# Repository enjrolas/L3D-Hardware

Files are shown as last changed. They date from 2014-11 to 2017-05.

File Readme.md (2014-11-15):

This repository contains all the hardware files we use to make our cubes.  It's organized in two directories 
for the two sizes of cubes we make, a 8x8x8 cube and a 16x16x16 cube.  Each directory includes the eagle files
for the baseboard that goes at the bottom of the cube, and the thin LED stick PCBs that hold the LED themselves.
The 8x8x8 cube has 64 LED sticks, and the 16x16x16 cube has a whopping 256 LED sticks.  

Electrically, the cubes are quite simple.  They're based around the popular WS2812B addressable LED and the Spark Core processor.  Our BOM
has Chinese sources, but you can also source the WS2812B LEDs from any number of sources, such as [Adafruit](https://www.adafruit.com/products/1655) and our 
friends [at Seeed Studios](http://www.seeedstudio.com/depot/WS2812B-RGB-LED-with-Integrated-Driver-Chip-10-PCs-pack-p-1675.html).
The other components are a few common passives detailed in the BOM.

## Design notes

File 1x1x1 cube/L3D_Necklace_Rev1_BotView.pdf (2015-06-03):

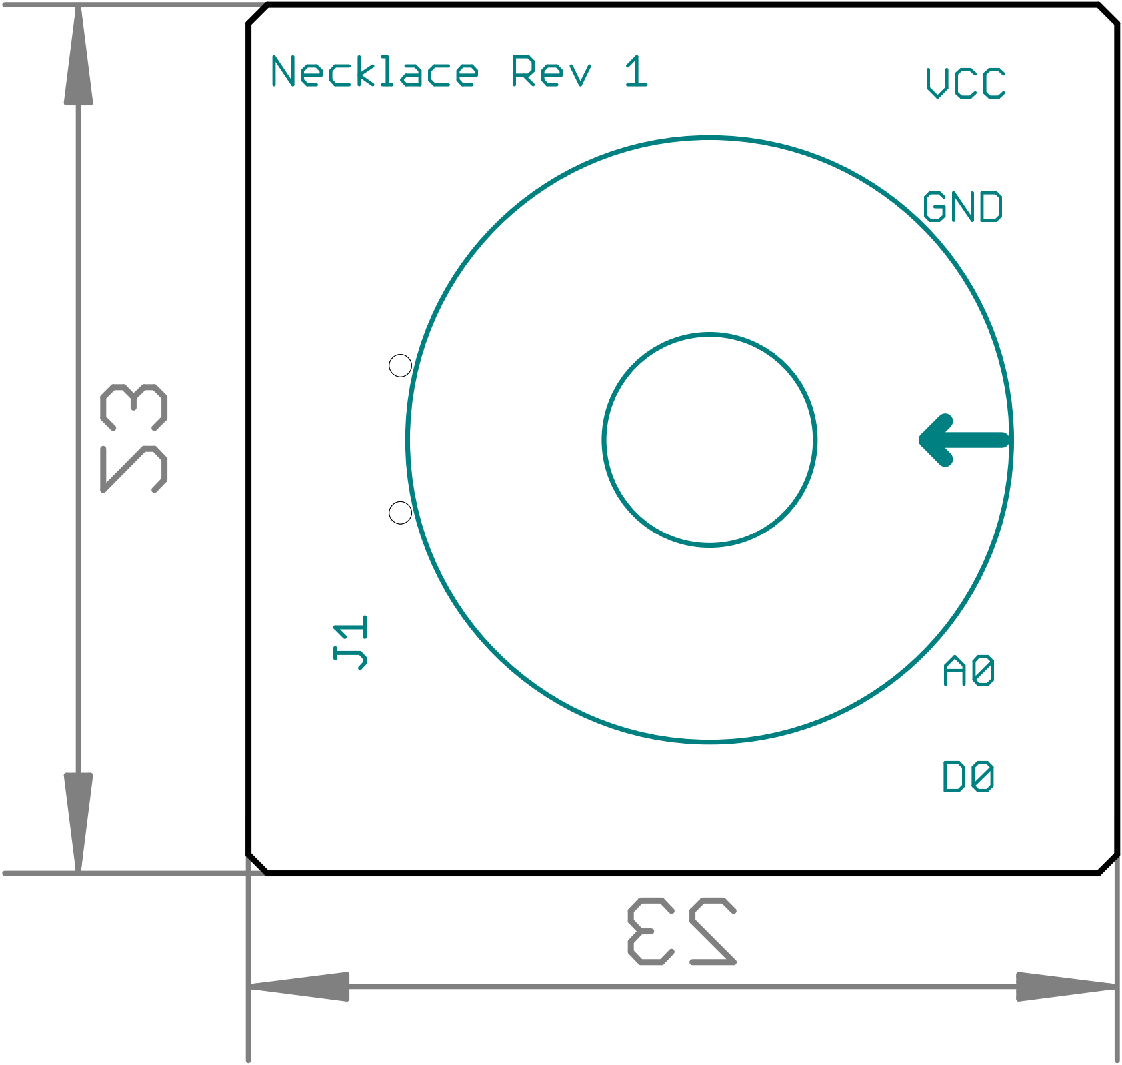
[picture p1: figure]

4/1/2015 4:39:10 PM f=8.00 mirrored D:\Dropbox\Dropbox (Haddock Invention)\L3D\Electronics\L3D_Necklace\L3D_NecklaceV1.brd

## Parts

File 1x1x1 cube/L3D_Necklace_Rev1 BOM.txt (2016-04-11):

Partlist exported from /Users/japhy/Downloads/L3D-Hardware-master/1x1x1 cube/L3D_Necklace_Rev1.sch at 4/11/16 1:42 PM

Part Value                              Device                             Package              Description                                                             
B1   BUTTONCELLLIR1632                  BUTTONCELLLIR1632                  BUTTONCELL_LIR1632                                                                           
C1   100nF                              C-0603                             0603                 Ceramic Capacitors                                                      
C2   100nF                              C-0603                             C0603                                                                                        
C6   10nF                               C-0603                             C0603                                                                                        
C7   100nF                              C-0603                             C0603                                                                                        
C9   100nF                              C-0603                             0603                 Ceramic Capacitors                                                      
C11  100nF                              C-0603                             0603                 Ceramic Capacitors                                                      
C12  100nF                              C-0603                             0603                 Ceramic Capacitors                                                      
D1                                      WS2812BWS2812B_STANDARD            WS2812B_STANDARD                                                                             
D2                                      LEDLED1206                         LED1206              LED                                                                     
J1   CONNECTOR-HEADER-2X3P2X3P-2.54-SMT CONNECTOR-HEADER-2X3P2X3P-2.54-SMT 2X3P-2.54-SMT                                                                                
J2   VCC                                1R5MM-HOLE                         1R5MM-HOLE                                                                                   
J3   GND                                1R5MM-HOLE                         1R5MM-HOLE                                                                                   
J4   D0                                 1R5MM-HOLE                         1R5MM-HOLE                                                                                   
J5   A0                                 1R5MM-HOLE                         1R5MM-HOLE                                                                                   
JP1  USBUSB-MICROB-SLOT-HOLE            USBUSB-MICROB-SLOT-HOLE            USB-MICROB-SLOT-HOLE                                                                         
M1   MICROPHONEMICROPHONE_1*3MM         MICROPHONEMICROPHONE_1*3MM         MICROPHONE_1*3MM                                                                             
Q1   TRANSISTOR-NPN-0400000P1           TRANSISTOR-NPN-0400000P1           SOT23                S9013：NPN Transistor                                                    
R1   75k                                R-0603                             0603                                                                                         
R2   100k                               R-0603                             0603                                                                                         
R3   50                                 R-0603                             0603                                                                                         
R4   1k                                 R-0603                             0603                                                                                         
R5   10k                                R-0603                             0603                                                                                         
R6   51                                 R-0603                             R0603                                                                                        
R7   100K                               R-0603                             R0603                                                                                        
R8   10K                                R-0603                             R0603                                                                                        
R9   10K                                R-0603                             R0603                                                                                        
R10  10K                                R-0603                             R0603                                                                                        
R11  100K                               R-0603                             R0603                                                                                        
R12  100K                               R-0603                             R0603                                                                                        
R13  100K                               R-0603                             R0603                                                                                        
R17  100K                               R-0603                             R0603                                                                                        
U1   MEGA8                              MEGA8                              MLF32X                                                                                       
U2   IC_SMD_FT232RQ                     IC_SMD_FT232RQ                     IC_SMD_QFN32         Source: http://www.ftdichip.com/Documents/DataSheets/DS_FT232R_v104.pdf 
U3   LM358DRSOT23-8(M8)                 LM358DRSOT23-8(M8)                 SOT-23-8(M8)         General purpose LOW Voltage, Rail-to-Rail Output Amplifiers             
Y1   SMARTPRJ_RESONATORMU               SMARTPRJ_RESONATORMU               SMARTPRJ_RESONATOR                                                                           
Z1   TL431                              TL431SOT23                         SOT23

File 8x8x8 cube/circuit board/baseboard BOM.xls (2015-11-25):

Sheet: Base PCBA
 |  | Base PCBA
Item | Part no. | Description | Reference | Qty | Remark
Base PCB | Base PCB | FR4, double side, 490x490mm, 2.0mm, 1oz black solder mask |  | 1
Resistors | ERJ-3GEYJ103V (http://www.digikey.com/product-detail/en/ERJ-3GEYJ103V) | RES 10K OHM 1/10W 5% 0603 SMD | R1,R4,R6,R8,R9,R10,R14,R15,R16,R20,R21,R26 | 12
Resistors | ERJ-3GEYJ104V (http://www.digikey.com/product-detail/en/ERJ-3GEYJ103V) | RES 100K OHM 1/10W 5% 0603 SMD | R11,R12,R18,R19, | 4
Resistors | ERJ-3GEYJ432V (http://www.digikey.com/product-detail/en/ERJ-3GEYJ103V) | RES 4.3K OHM 1/10W 5% 0603 SMD | R13 | 1
Resistors |  | RES 33 OHM, 1/10W 5% 0603 | R8 | 1
Resistors | ERJ-3GEYJ102V (http://www.digikey.com/product-detail/en/ERJ-3GEYJ103V) | RES 1K OHM 1/10W 5% 0603 SMD | R2,R5,R17 | 3
Resistors |  | RES 220K OHM 1/10W 5% 0603 | R22 | 1
Resistors |  | RES 180K OHM 1/10W 5% 0603 | R23 | 1
Resistors |  | RES 3.3M OHM 1/10W 5% 0603 | R24 | 1
Resistors |  | RESISTOR .68 OHM 2W, THROUGH HOLE | R3,R7 | 2
Capacitors | C1608X7R1E104K (http://www.digikey.com/product-detail/en/C1608X7R1E104K) | CAP CER 0.1UF 25V 10% X7R 0603 | C3,C6,C7,C8,C9,C10,C11,C12,C13 | 10
Capacitors | C3528 | TAN CAP 220UF C3528 | C19 | 1
Capacitors | C1608X7R1E106K (http://www.digikey.com/product-detail/en/C1608X7R1E104K) | CAP CER 10UF 6.3V 10% X7R 0603 | C5 | 1
Capacitors | C1608X7R1E224K | CAP CER 0.22uF 25V 10% X7R 0603 | C14, C17 | 2
Capacitors | C1608X7R1E104K (http://www.digikey.com/product-detail/en/C1608X7R1E104K) | CAP CER 10nF 25V 10% X7R 0603 | C15 | 1
Capacitors | C1608X7R1E681K | CAP CER 680PF 25V 10% NPO 0603 | C16 | 1
Capacitors |  | 470UF, 16V, E.CAP | C1,C2 | 2
Inductor | Inductors | 2.2uH, 100mA, 0603 | L1 | 1
MOSFET | FDD6637 | MOSFET, 5A, TO-252 | Q2 | 1
MOSFET | 2N7002 | 2N7002, SOT23, 200mA | Q1,Q3 | 2
DIODE | BAV199 | BAV199 | D1 | 1
DIODE | 1N4148 | 1N4148 | D2 | 1
TRANSISTOR | SS8550 | SS8550, SOT23 | Q4 | 1
OP AMP | LMV324I | OP AMP LMV324I SO-14 | U2 | 1
CONNECTOR | 2X2,FEMALE | XH2X2, 2.54MM, FEMALE, flash gold | j1-j64 | 64
CONNECTOR | 1X12, FEMALE | 1X12, FEMALE, 2.54MM | JP1,JP2 | 2
CONNECTOR | 1x40, MALE | 1X40, MALE PIN, 2.54MM | A1 | 1
SLIDE SWITCH | SK12D07VG3 | SLIDE SWITCH, 2P3T | S1 | 1
BUTTON SWITCH | MODE SWITCH | 12X12X7MM TACT SWITCH | MODE | 1
BUTTON SWITCH | RESET SWITCH | 6X6X5MM TACT SWITCH | RESET | 1
MICROPHONE | MICROPHONE | MICROPHONE, 52DB,DIA=9MM | M1 | 1
ACCELEROMETER | ADXL335BCPZ | ADXL335, 3 AXIS, 16FL | U1 | 1
Foam |  |  |  | 1

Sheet: LED PCBA
 |  | LED PCBA
Item | Part no. | Description | Reference | Qty
stick PCB | stick PCB | FR4, double side, 6.9x197mm, 1.0mm, 1oz black solder mask |  | 65
ESD bag | ESD bag | ESD bag 70*200, no zipper |  | 8
LED | WS2812B | WS2812B | D1-D520 | 520
connector | XH2x2 | XH2.54, 2X2, RIGHT ANGLE, FLASH GOLD | J1-J65 | 65

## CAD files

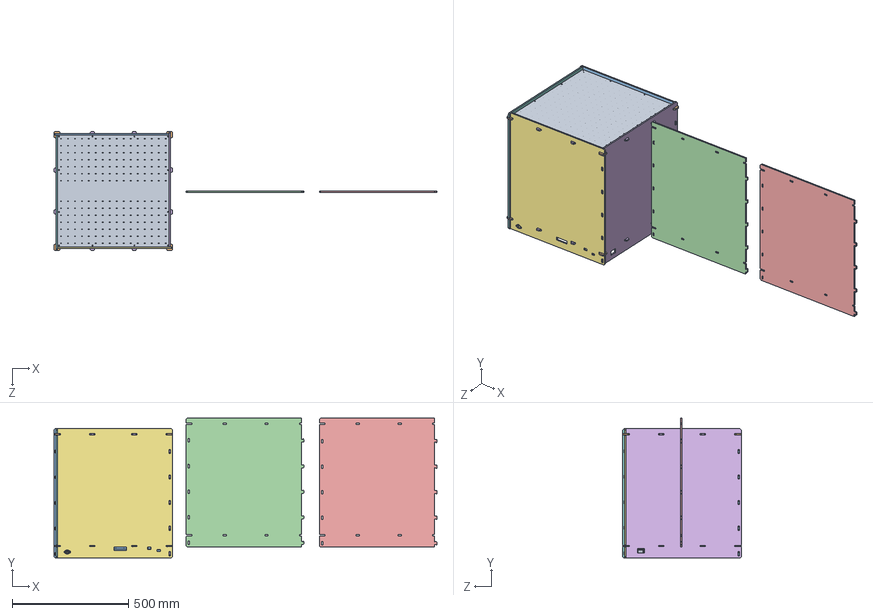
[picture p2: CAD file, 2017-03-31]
16x16x16 cube/3D model/LEDcube.SLDASM
1646.7 x 601.0 x 510.4 mm
pcb_bot
pcb_strick
box_side1
box_upside
box_downside
box_side2
box_side3
box_side4
box_top
corner x 8
box_bot
sup x 4
sup2 x 4
KPJX-PM-4S_rB8
spark
DC2DC
white connector
BigCubePowerPlugholder

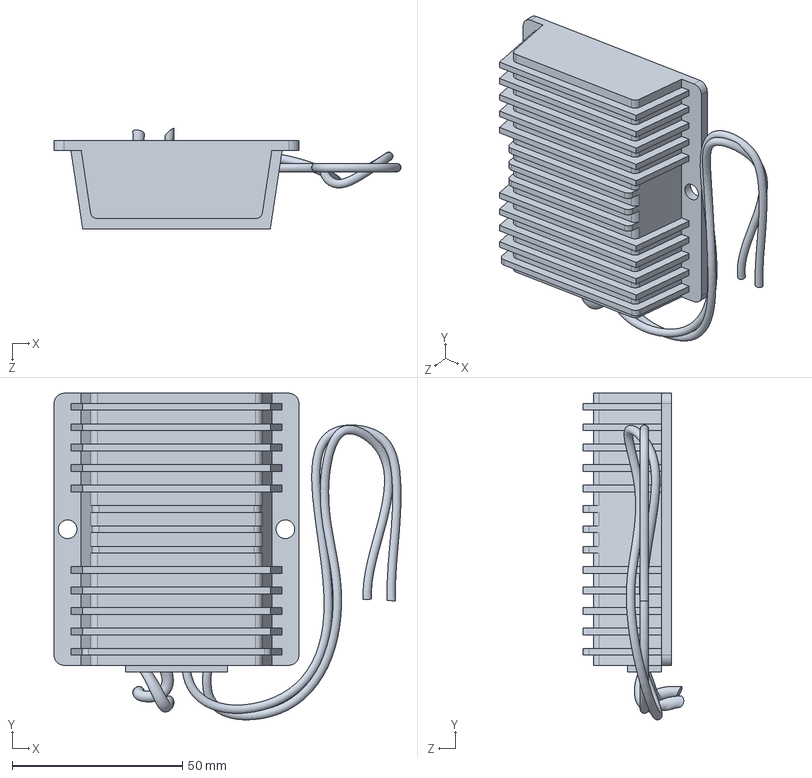
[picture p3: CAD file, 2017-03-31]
16x16x16 cube/3D model/DC2DC.SLDPRT
102.0 x 96.0 x 29.6 mm

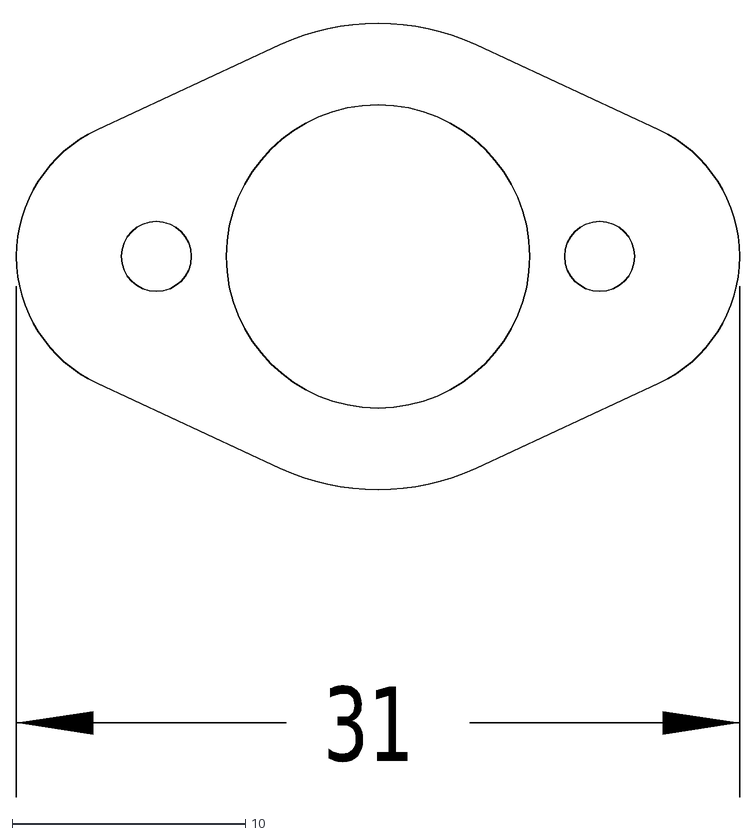
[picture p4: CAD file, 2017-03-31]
16x16x16 cube/case/3mm.DXF
31

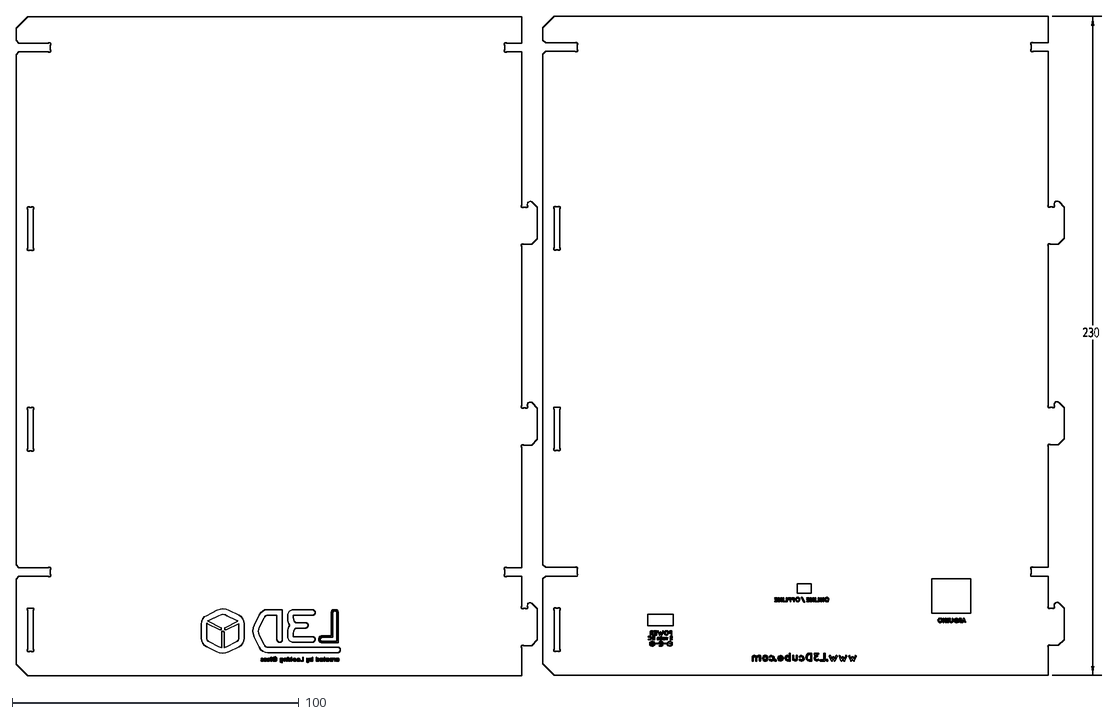
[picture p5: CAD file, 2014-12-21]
8x8x8 cube/case/2mm_eng.DXF
230

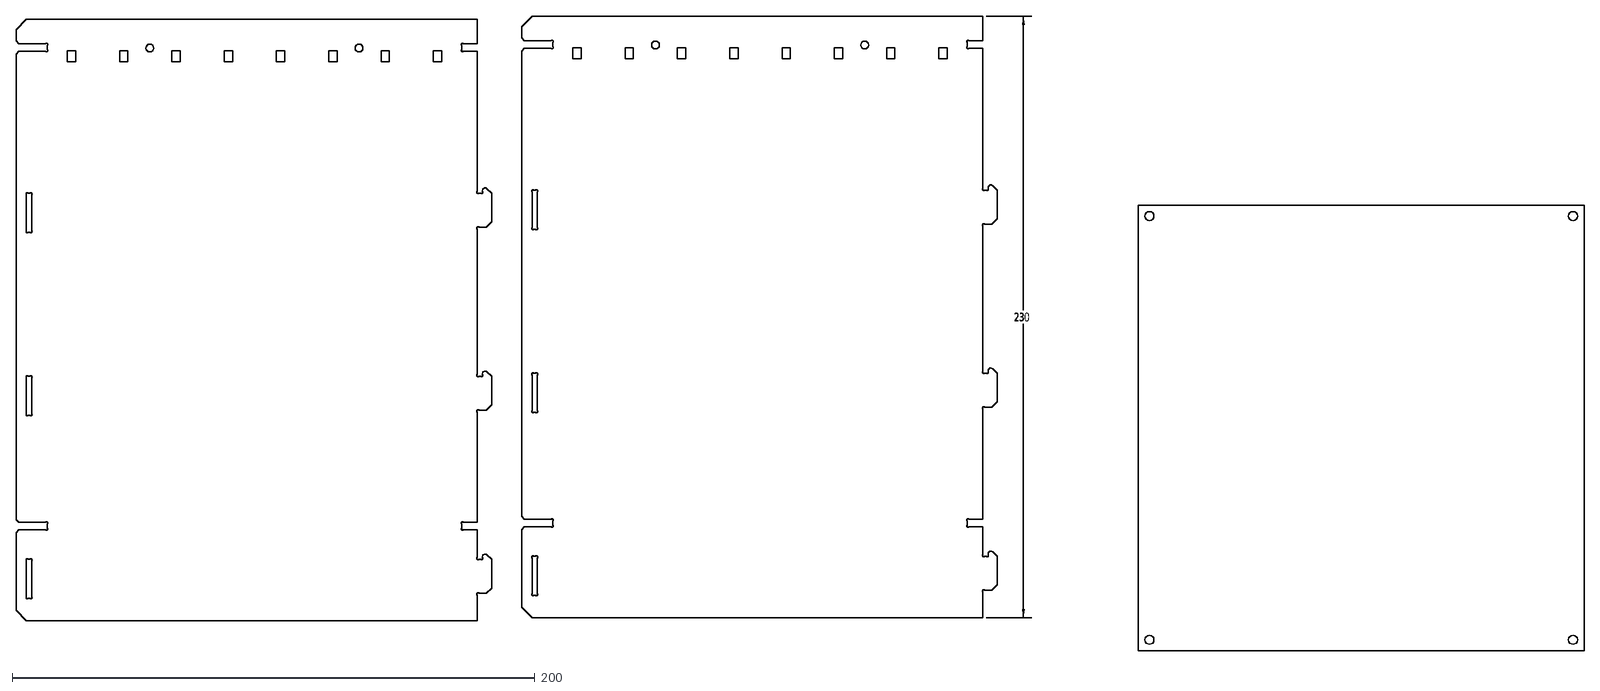
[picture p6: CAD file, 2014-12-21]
8x8x8 cube/case/2mm.DXF
230

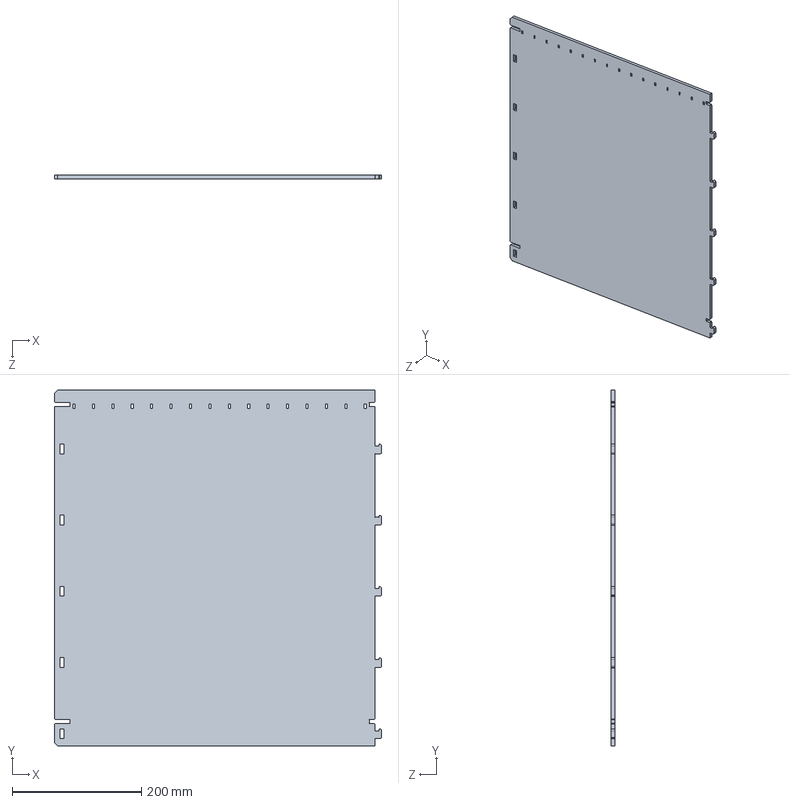
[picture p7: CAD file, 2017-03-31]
16x16x16 cube/3D model/box_side4.SLDPRT
505.4 x 550.0 x 6.00 mm

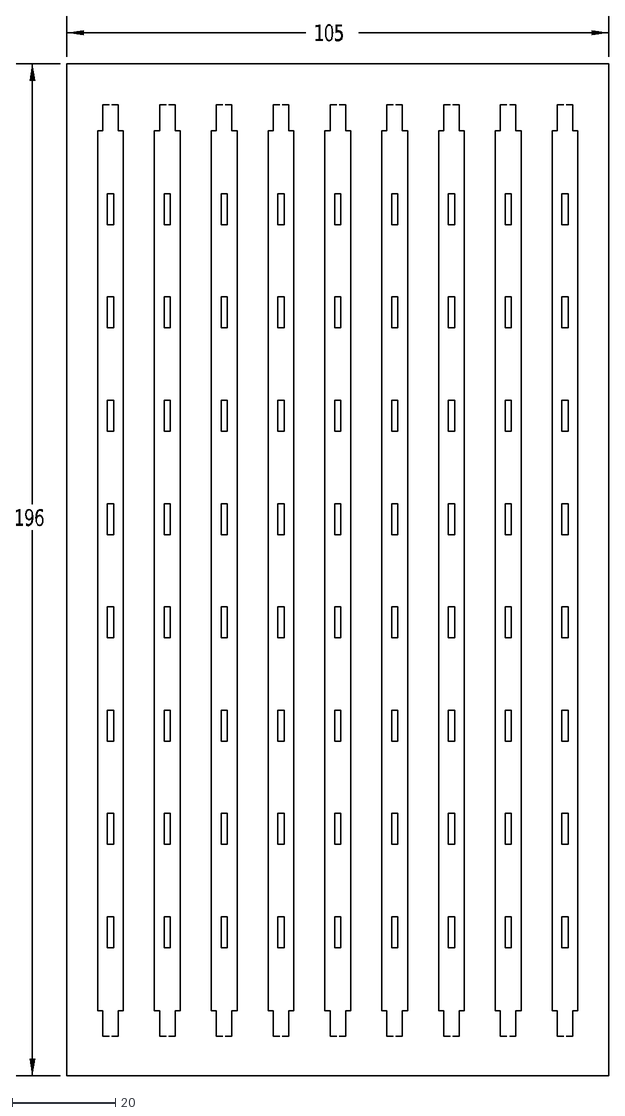
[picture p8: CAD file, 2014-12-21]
8x8x8 cube/case/4mm plate.DXF
105
196

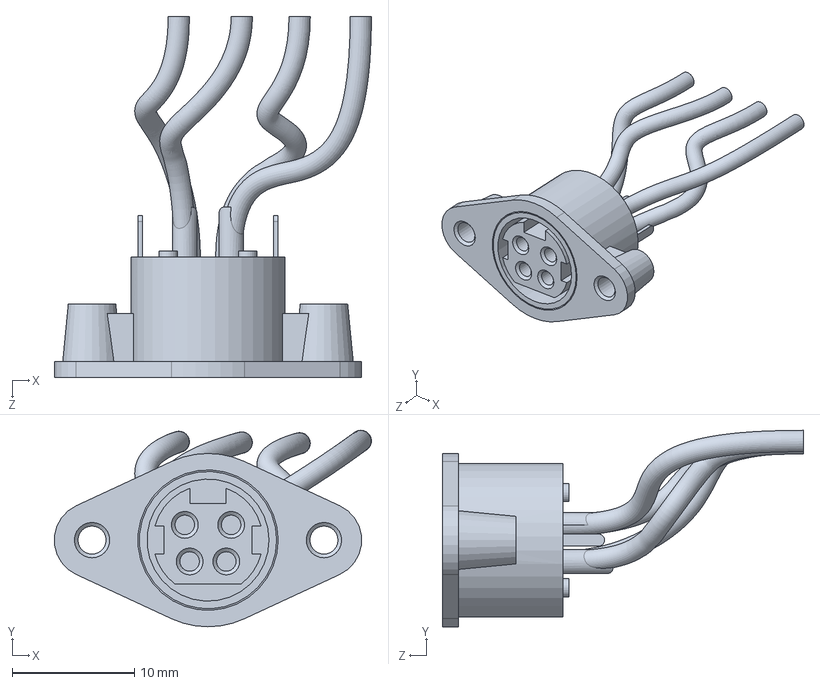
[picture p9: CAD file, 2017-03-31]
16x16x16 cube/3D model/KPJX-PM-4S_rB8.SLDPRT
26.0 x 16.1 x 29.6 mm

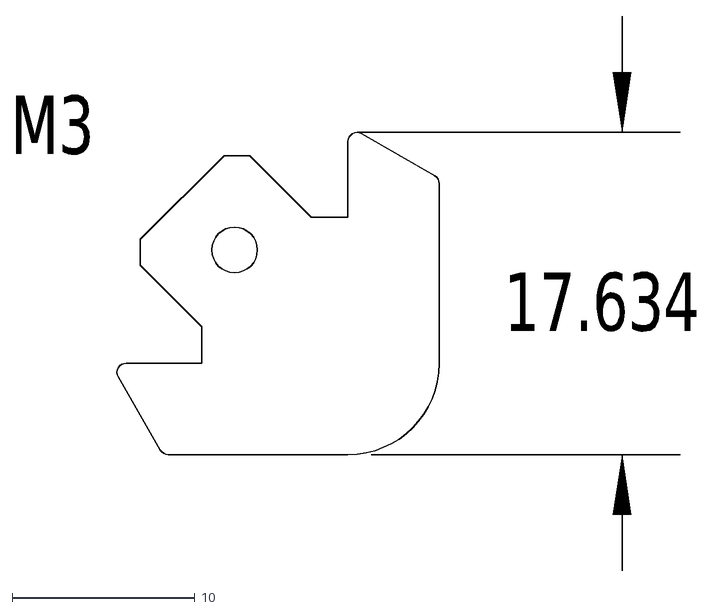
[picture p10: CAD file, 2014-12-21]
8x8x8 cube/case/corner.DXF
17.634
M3

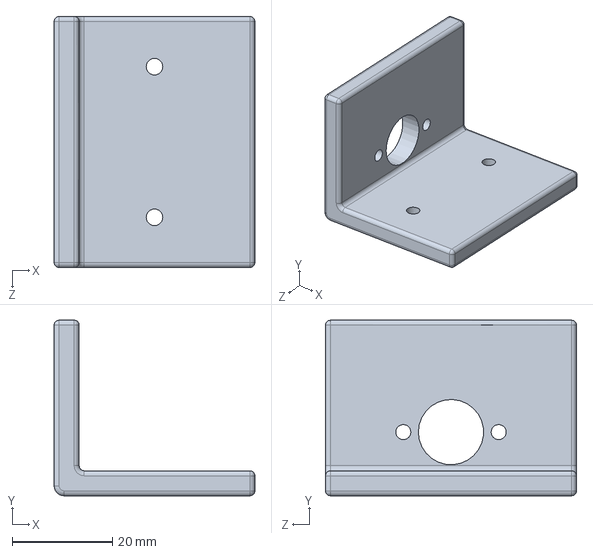
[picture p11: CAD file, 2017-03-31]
16x16x16 cube/3D model/BigCubePowerPlugholder.SLDPRT
40.0 x 35.0 x 50.0 mm

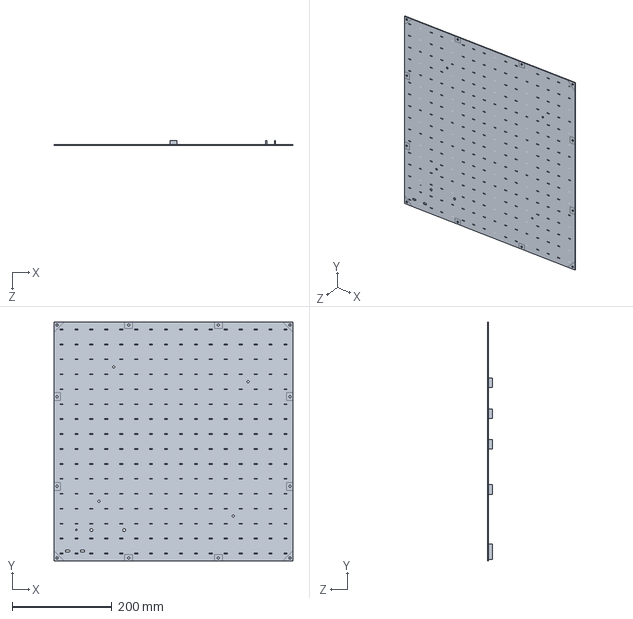
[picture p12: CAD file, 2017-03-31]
16x16x16 cube/3D model/pcb_bot.SLDPRT
480.0 x 480.0 x 10.5 mm

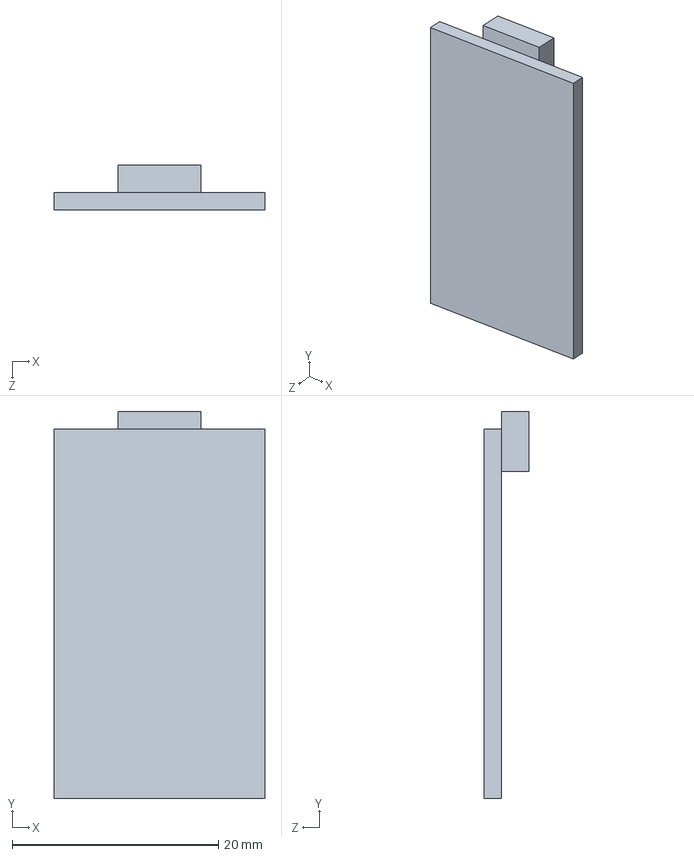
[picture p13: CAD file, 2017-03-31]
16x16x16 cube/3D model/spark.SLDPRT
20.4 x 37.5 x 4.40 mm

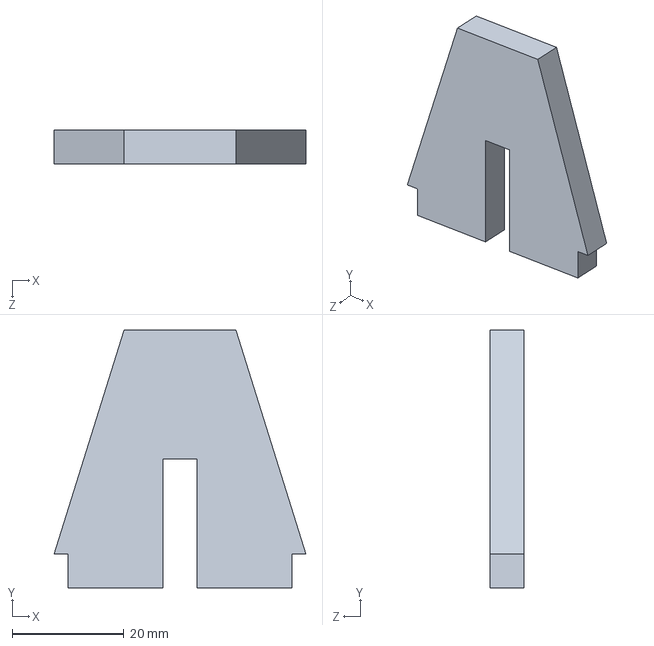
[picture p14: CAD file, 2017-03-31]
16x16x16 cube/3D model/sup2.SLDPRT
45.0 x 46.0 x 6.00 mm

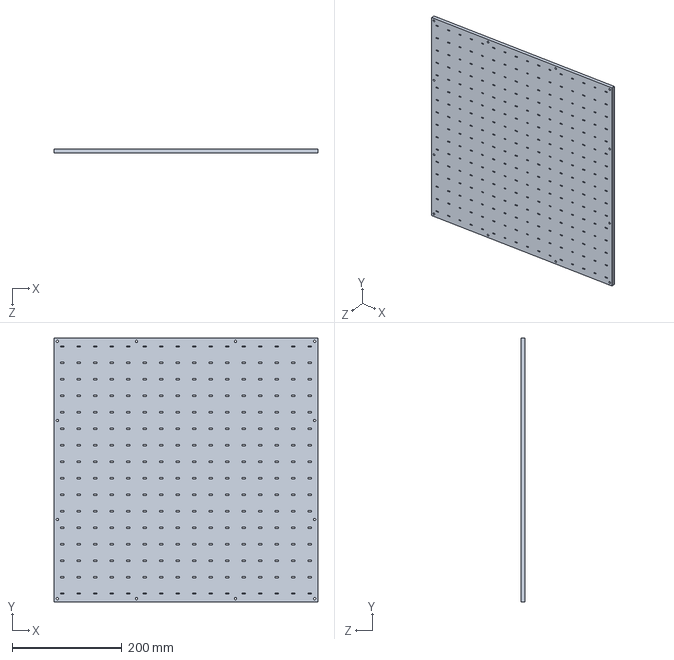
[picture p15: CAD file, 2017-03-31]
16x16x16 cube/3D model/box_top.SLDPRT
480.2 x 480.2 x 8.00 mm

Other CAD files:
16x16x16 cube/case/6mm.DXF
16x16x16 cube/case/8mm.DXF
16x16x16 cube/3D model/box_upside.SLDPRT
16x16x16 cube/3D model/box_side3.SLDPRT
16x16x16 cube/3D model/box_downside.SLDPRT
16x16x16 cube/3D model/box_side1.SLDPRT
16x16x16 cube/3D model/box_side2.SLDPRT
16x16x16 cube/3D model/corner.SLDPRT
16x16x16 cube/3D model/face.SLDPRT
16x16x16 cube/3D model/pcb_strick.SLDPRT
16x16x16 cube/3D model/sup.SLDPRT
16x16x16 cube/3D model/white connector.SLDPRT

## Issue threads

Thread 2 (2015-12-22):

Some questions about the L3D-Hardware

myxingchao, 2015-12-22:
Hello, I downloaded your hardware package, looked and found sch file with my altium designer can not open your schematic, ask you what software painting? ? Can you give me some guidance

enjrolas, 2015-12-22:
Hi — these were done in eagleCAD <https://www.google.com/url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>.  There’s a free download for hobbyist use.

—alex

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

myxingchao, 2015-12-30:
hello alex, after seen your schematic, I feel your light cube is very interesting, I ask that you have the entire list of parts it? ? Can you give me a look

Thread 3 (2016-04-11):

Is there a BOM for the 1x1x1 cube?

oculartechie, 2016-04-11:

enjrolas, 2016-04-11:
Thanks for mentioning — just added it to the repo.

—me

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

oculartechie, 2016-04-12:
Thanks.  Do you have Digikey part numbers for some of the parts?  Also, for the sketch, it is for one side of the 1x1x1 cube?  Thanks.

oculartechie, 2016-08-12:
Checking on this again.

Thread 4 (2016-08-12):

request .brd board layout for daughter board v3.1 (sept 2015) 16x16x16

scottjames, 2016-08-12:
Our local maker space and science center ([suncoastscience.org](http://suncoastscience.org)) has a 16x16x16 cube, and we really enjoy playing with it! Great job on the design and implementation!

However, ours has dark panels number 4, and 6.  I noticed the v3 schematic and board seems out of date, and wonder if you would update to the latest files for 16x cube?  The board on our cube shows Sept. 2015, but the .brd v3 files says January 2015.

Also, the v3 daughterboard has the .sch schematic layout, but no board .brd file.  I wanted to trace the signals to diagnose the two cube panels not working.  The schematic helps, but I was hoping to get the board layout file too?

We are also writing an updated library with driver for the 16x16x16 cube, since most files we find seem hardcoded for the 8x8x8 cube.  It's been a challenge finding software for the 16x cube and we wanted to create something to contribute back to the community.  This work is being done by the [Sarasota Software Engineers User Group](http://www.meetup.com/SarasotaSoftwareEngineers/) as we update create our library, we will update our [github page with Cube Examples](https://github.com/srqsoftware/Cubetube-Examples).

thanks!
-Scott

enjrolas, 2016-08-12:
Hi Scott,
	Thanks for letting me know, will chat with our team’s EE and get the latest schematic and board files up ASAP.  I’ll let you know once it’s up.

—me

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

ODINITE, 2017-02-08:
What is the status of the 16x16x16 .brd files? I can't seem to open the .brd files with Eagle.

Is there an updated set of files that can be posted? I am interested in seeing the layout to understand how to multiplex to 4096 addresses and may want to order a PCB sometime in the future to tinker with (when funds allow it).

enjrolas, 2017-02-08:
I just tried — was able to open them fine in eagle 7.7.0 on my mac — what version of eagle are you using?

—alex

On February 7, 2017 at 7:44:55 PM, Aaron Jensen (notifications@github.com) wrote:

What is the status of the 16x16x16 .brd files? I can't seem to open the .brd files with Eagle.

Is there an updated set of files that can be posted? I am interested in seeing the layout to understand how to multiplex to 4096 addresses and may want to order a PCB sometime in the future to tinker with (when funds allow it).

—
You are receiving this because you commented.
Reply to this email directly, view it on GitHub, or mute the thread.

enjrolas, 2017-02-08:
FWIW, we don’t multiplex in the L3D cube — we use WS2812B digital LEDs, and we clock the data out into strings of LEDs.  The 16x cube has 8 parallel data lines, and each data line has 512 LEDs — 2 16x16 planes.  The photon processor that we use is able to drive those strings at 60hz

On February 7, 2017 at 7:44:55 PM, Aaron Jensen (notifications@github.com) wrote:

What is the status of the 16x16x16 .brd files? I can't seem to open the .brd files with Eagle.

Is there an updated set of files that can be posted? I am interested in seeing the layout to understand how to multiplex to 4096 addresses and may want to order a PCB sometime in the future to tinker with (when funds allow it).

—
You are receiving this because you commented.
Reply to this email directly, view it on GitHub, or mute the thread.

ODINITE, 2017-02-08:
Thank you for the very prompt response. I reinstalled Eagle and re-downloaded the repository and it seems to be working now.

In the "L3D-Hardware-master\16x16x16 cube" folder, I see a Rev3 .brd file for the base board, but do not see a Rev3 .brd file for the Daughter board (although a .sch and a .pdf file exists for the Rev3 Daughter board). Is this missing, or will the Rev1 Daughter board work with the Rev3 base board?

Thanks for the info about the WS2812B digital LEDs! I erroneously assumed it was being multiplexed like some other Cube projects out there. I actually used a very similar setup on my Ambilight TV project. The LED strips are very easy to work with!

enjrolas, 2017-02-08:
Oh, good call — lemme chat with the EE and get the rev 3 brd file up in the repo.  Thanks for letting me know.  I’ll post once it’s up.

FWIW, there’s not that all that much going on in the daughter board.  We made that board because we couldn’t put the monster ~2’x2’ motherboard into a pick-and-place, so we just threw all the SMT parts onto the daughterboard so we could assemble it.

Basically, there’s a socket for a photon processor, a microphone and amplifier circuit (we route a mic signal into the photon so we can make stuff that responds to music), an accelerometer (I wrote a cute little interface where you smack the cube to change the pattern), and a 3.3v - 5v level shifter, to bring the 3.3v data signals from the photon for the WS2812s up to 5v, which the WS2812s prefer.

If you wanted a stripped-down DIY version, all you’d really need is the photon and the level shifter, and in fact, you can kiiinda get away without the level shifter, although with these long traces, it’s more reliable to work with 5V data.

On February 8, 2017 at 12:41:46 AM, Aaron Jensen (notifications@github.com) wrote:

Thank you for the very prompt response. I reinstalled Eagle and re-downloaded the repository and it seems to be working now.

In the "L3D-Hardware-master\16x16x16 cube" folder, I see a Rev3 .brd file for the base board, but do not see a Rev3 .brd file for the Daughter board (although a .sch and a .pdf file exists for the Rev3 Daughter board). Is this missing, or will the Rev1 Daughter board work with the Rev3 base board?

Thanks for the info about the WS2812B digital LEDs! I erroneously assumed it was being multiplexed like some other Cube projects out there. I actually used a very similar setup on my Ambilight TV project. The LED strips are very easy to work with!

—
You are receiving this because you commented.
Reply to this email directly, view it on GitHub, or mute the thread.

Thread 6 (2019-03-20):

Open hardware license

jdeglavina, 2019-03-20:
Hello!

I obviously missed when these cubes were first released. Awesome work!

I see that everything is open hardware, but I don't see any license attached on here, or to any of the hardware/software files. Is there one?

I'm asking because I made some tweaks to the design to use an ESP32 in place of a Particle Photon, and modified the LED sticks slightly. I would like to sell the PCB's in my store, if possible. Please let me know if we can arrange that.

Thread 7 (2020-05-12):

L3d Cube problem

Dan0583, 2020-05-12:
Hi. I bought the led cube some years ago. Cube tube site is not working anymore and I am unable to flash my cube. I wrongly deleted the firmware on the photon and I tried to add this one on the console but it doesn't work. Could you please help me? Thanks in advance.

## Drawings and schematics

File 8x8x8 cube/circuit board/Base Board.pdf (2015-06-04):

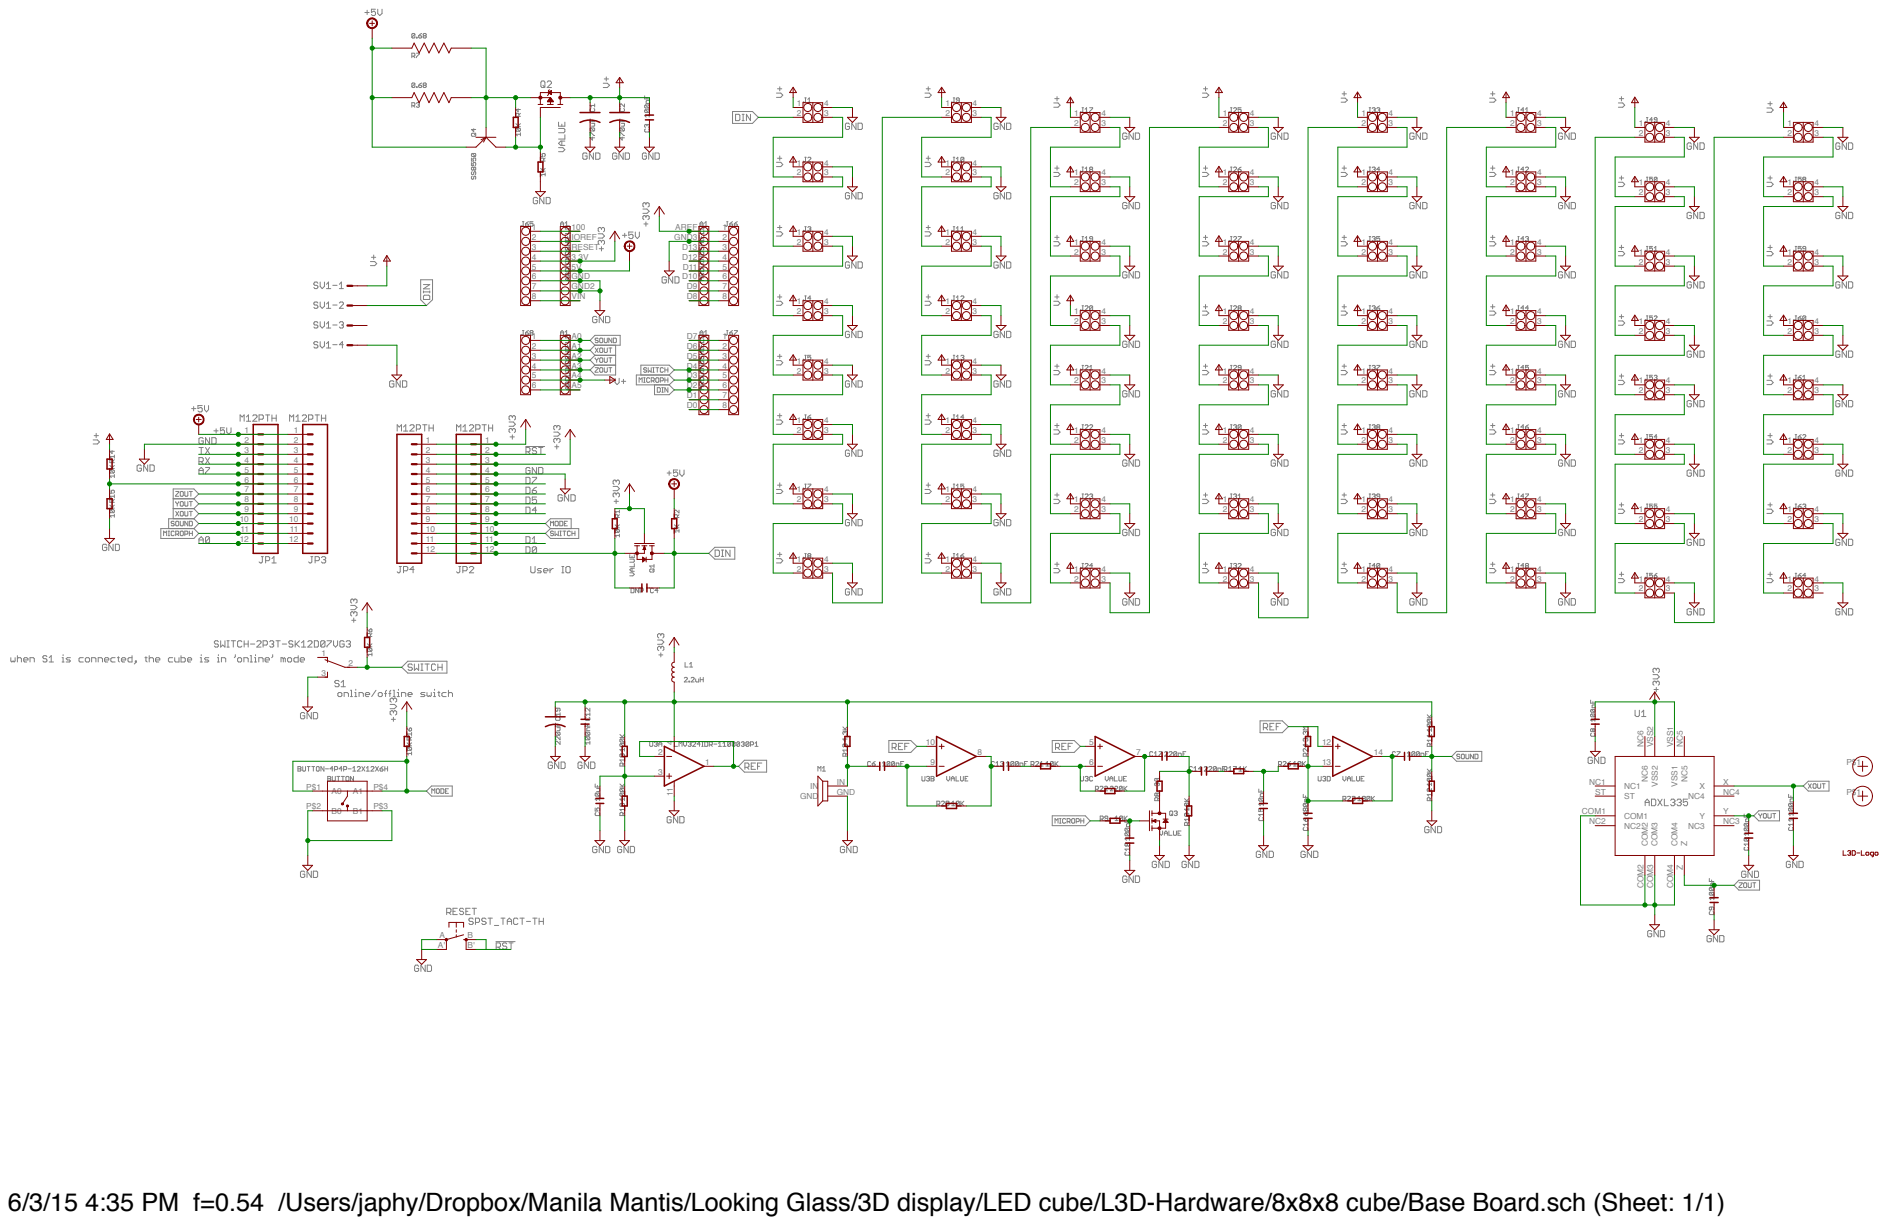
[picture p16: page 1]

6/3/15 4:35 PM f=0.54 /Users/japhy/Dropbox/Manila Mantis/Looking Glass/3D display/LED cube/L3D-Hardware/8x8x8 cube/Base Board.sch (Sheet: 1/1)

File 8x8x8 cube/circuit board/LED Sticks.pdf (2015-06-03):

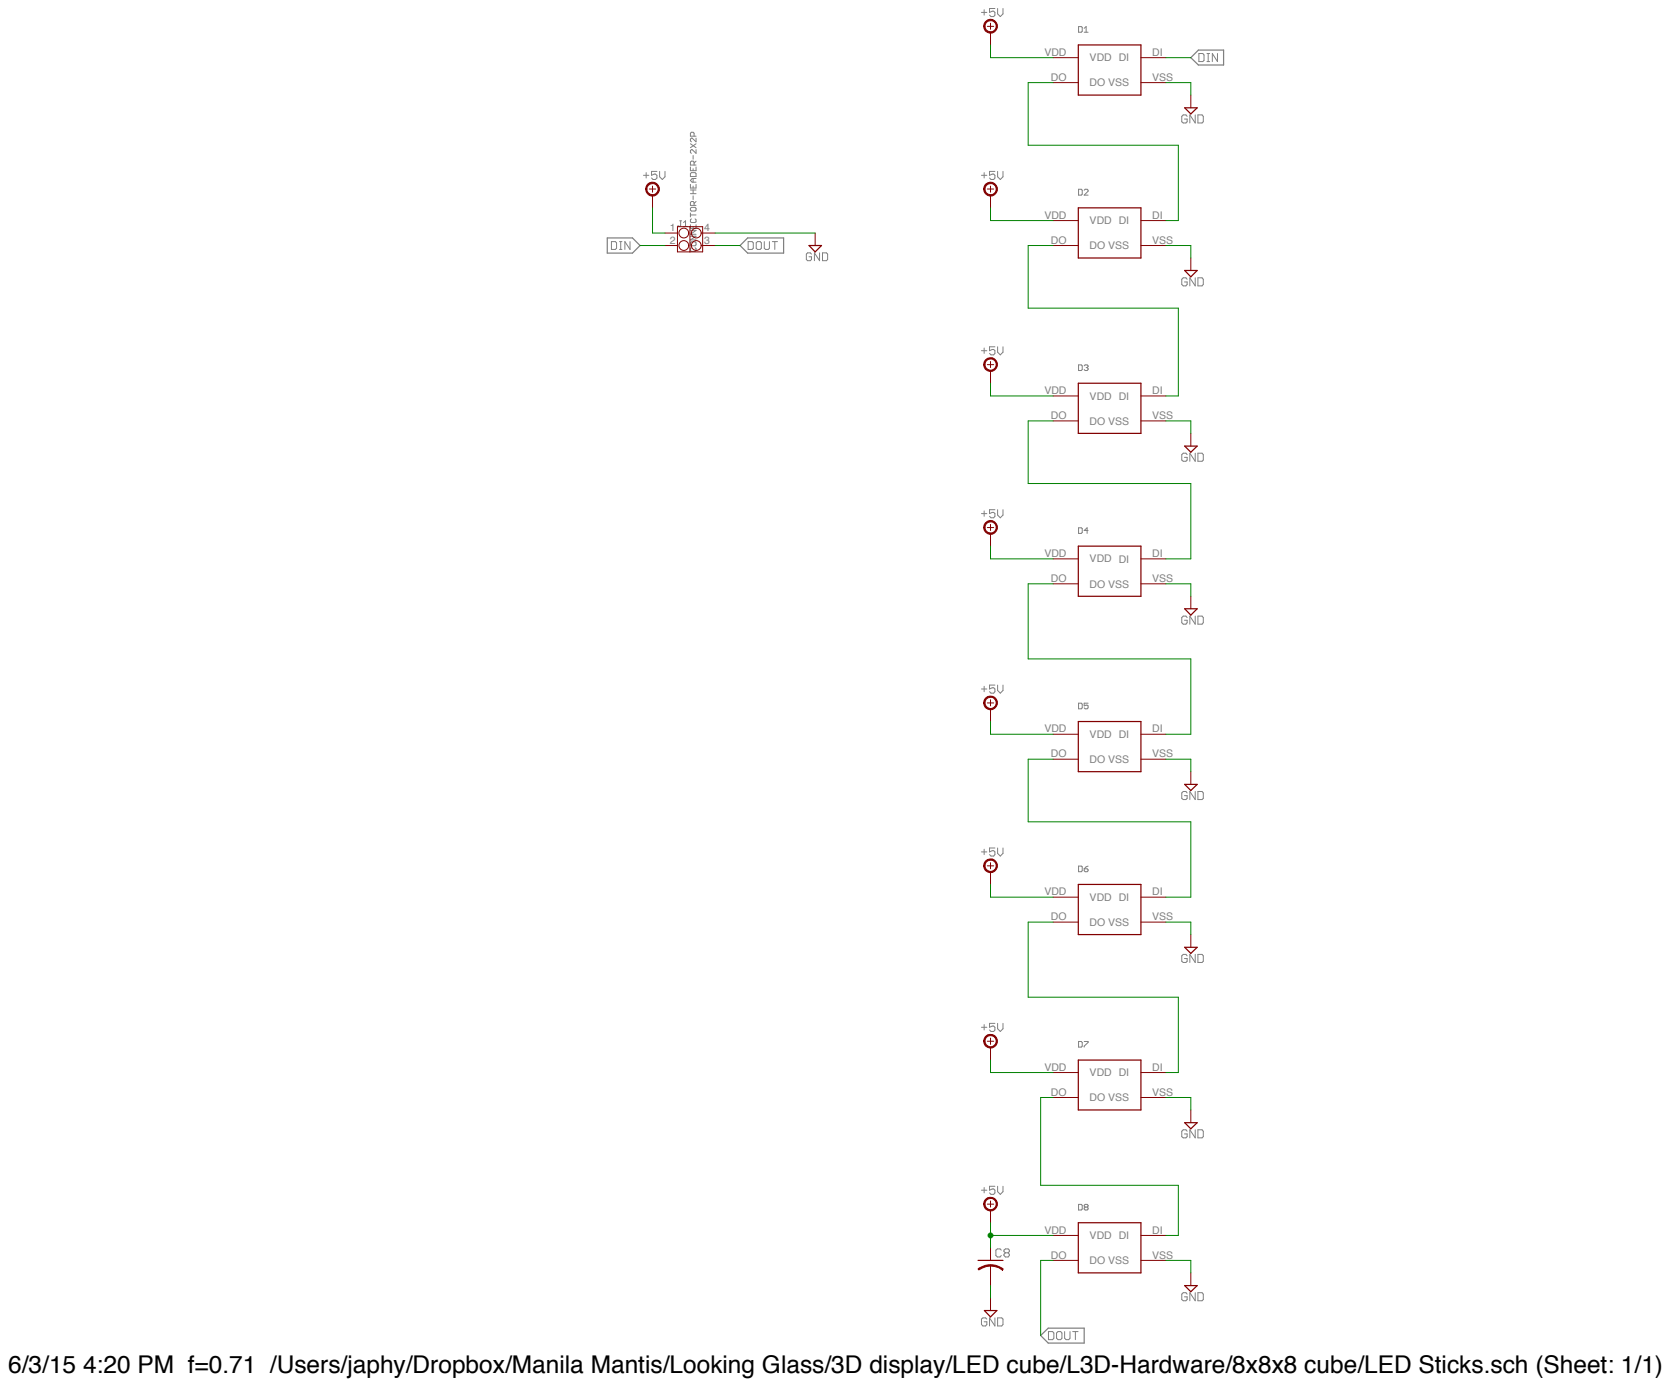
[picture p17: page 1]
VDD VDD; VSS

6/3/15 4:20 PM f=0.71 /Users/japhy/Dropbox/Manila Mantis/Looking Glass/3D display/LED cube/L3D-Hardware/8x8x8 cube/LED Sticks.sch (Sheet: 1/1)

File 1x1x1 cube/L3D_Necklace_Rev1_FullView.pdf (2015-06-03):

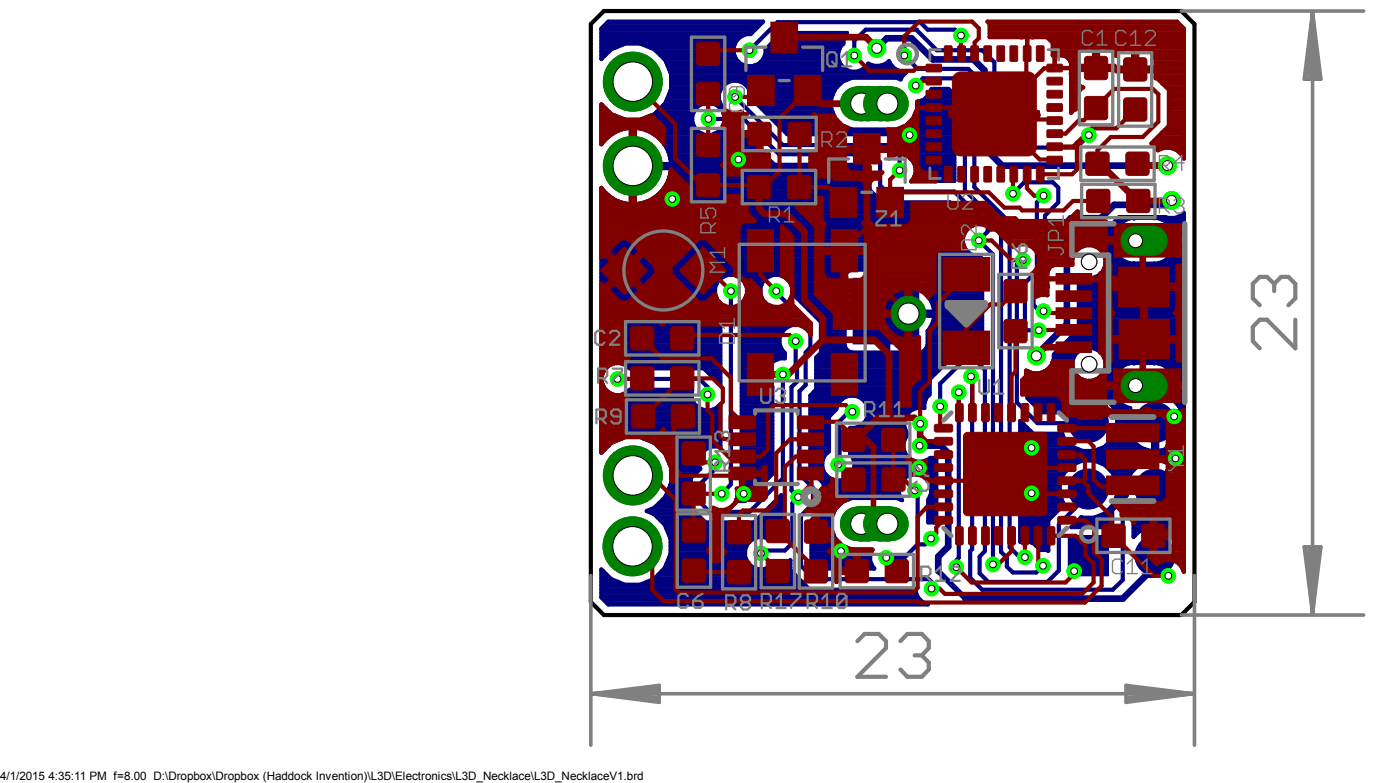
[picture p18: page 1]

4/1/2015 4:35:11 PM f=8.00 D:\Dropbox\Dropbox (Haddock Invention)\L3D\Electronics\L3D_Necklace\L3D_NecklaceV1.brd

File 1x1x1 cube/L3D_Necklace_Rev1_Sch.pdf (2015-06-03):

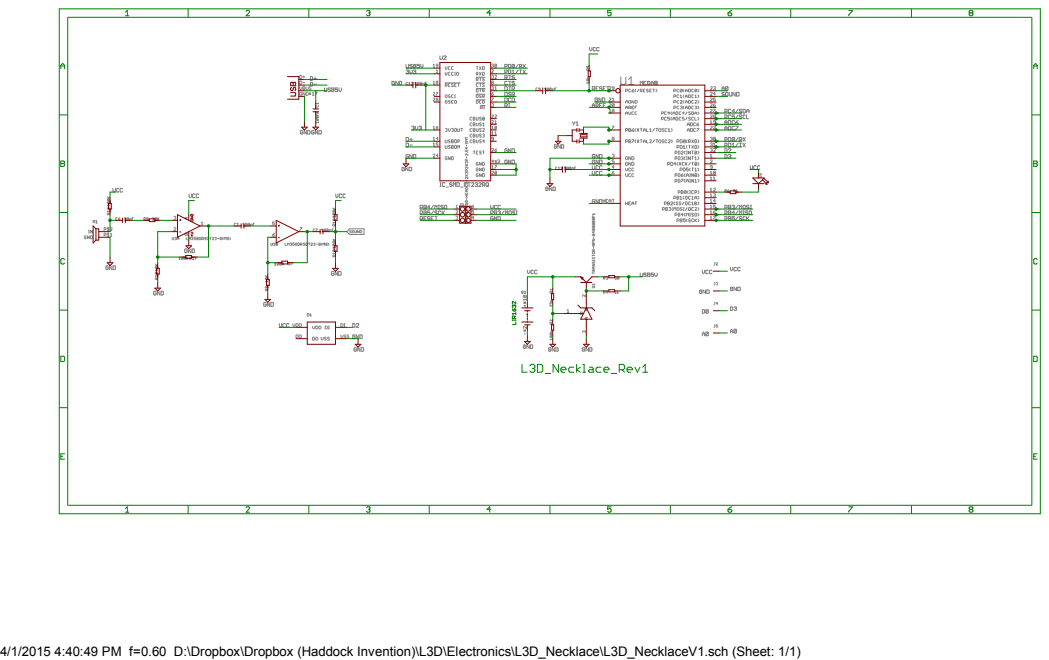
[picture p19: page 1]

4/1/2015 4:40:49 PM f=0.60 D:\Dropbox\Dropbox (Haddock Invention)\L3D\Electronics\L3D_Necklace\L3D_NecklaceV1.sch (Sheet: 1/1)

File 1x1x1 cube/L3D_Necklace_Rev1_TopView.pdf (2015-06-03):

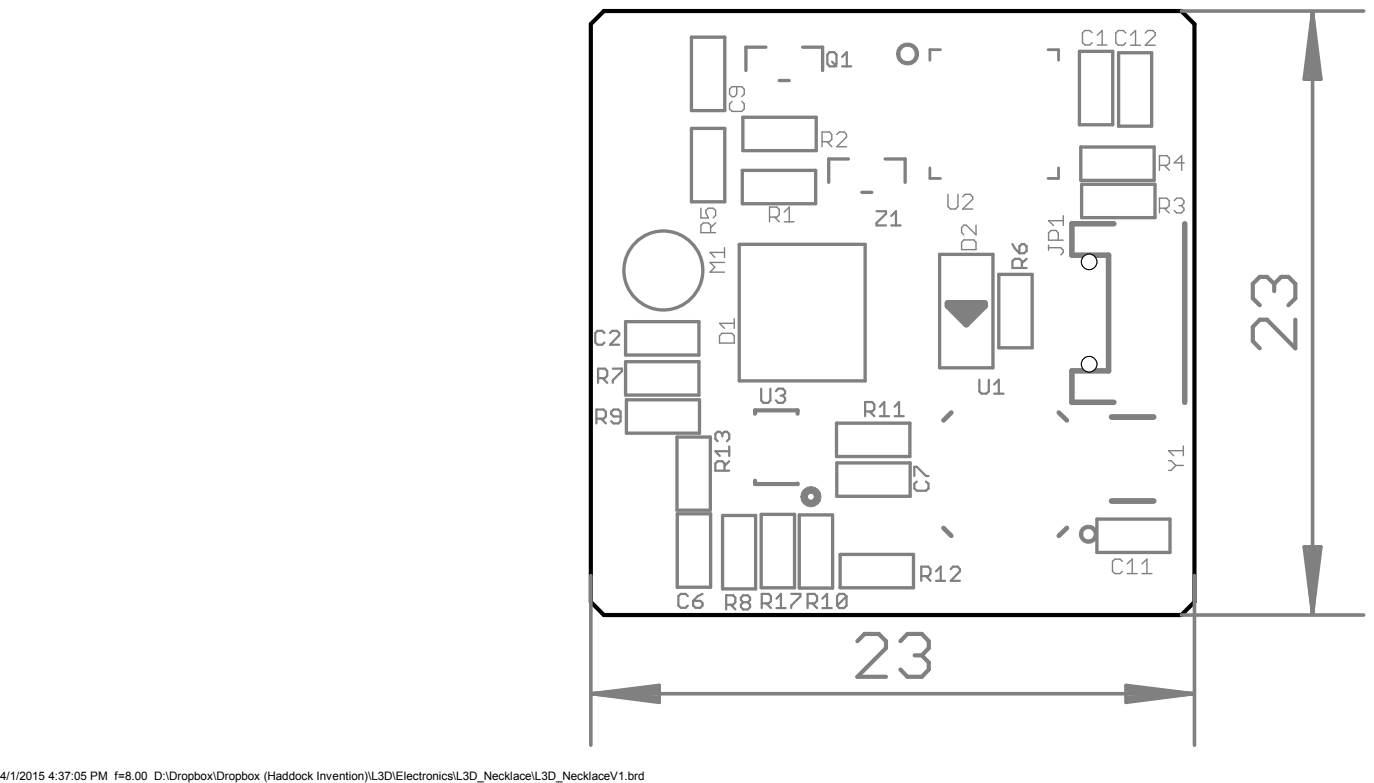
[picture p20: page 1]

4/1/2015 4:37:05 PM f=8.00 D:\Dropbox\Dropbox (Haddock Invention)\L3D\Electronics\L3D_Necklace\L3D_NecklaceV1.brd

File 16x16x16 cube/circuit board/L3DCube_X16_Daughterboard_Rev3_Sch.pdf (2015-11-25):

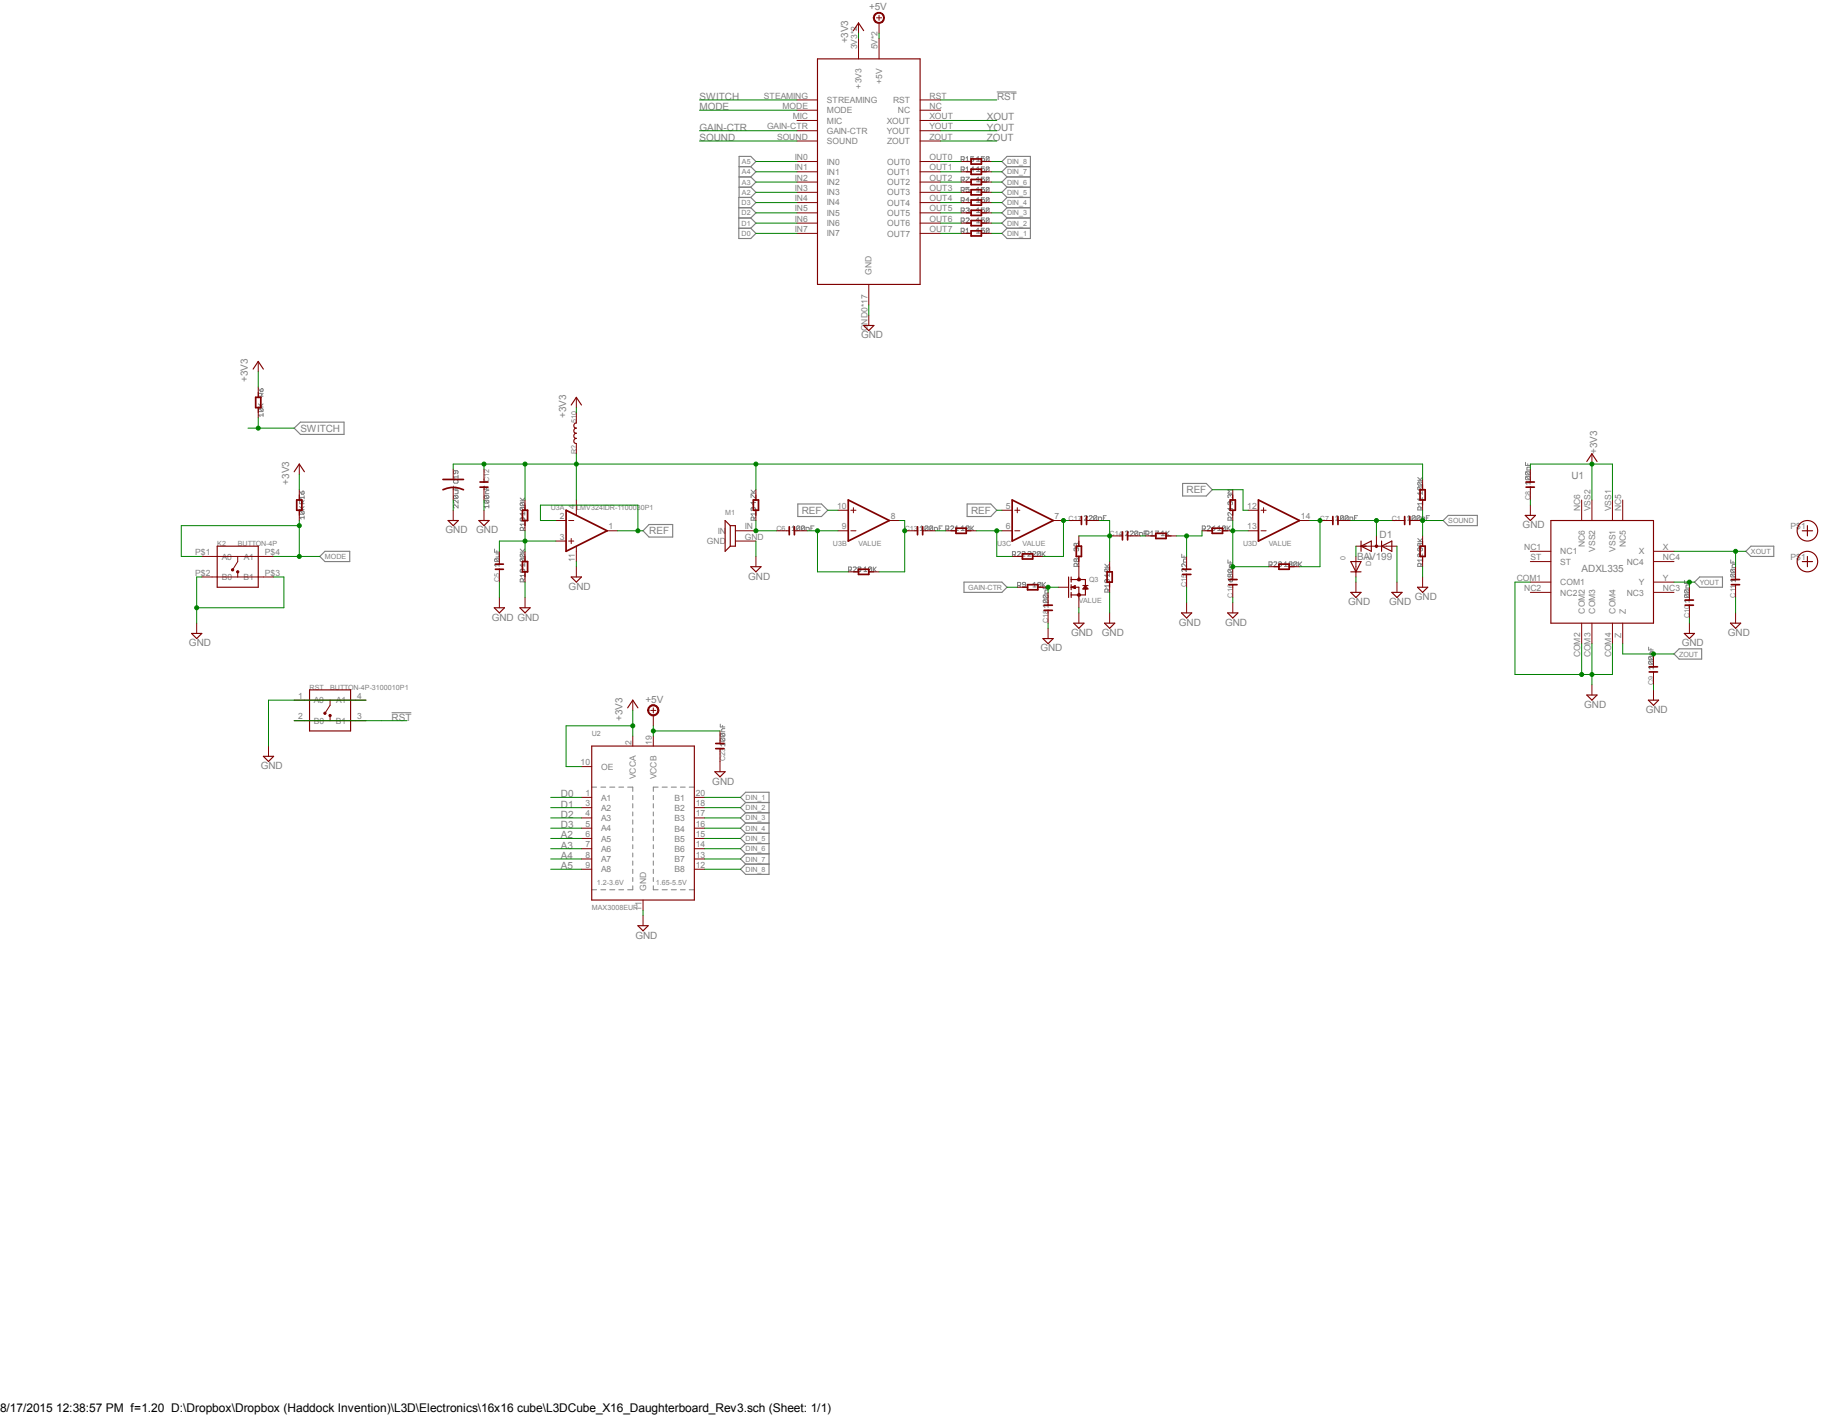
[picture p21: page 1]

GAIN-CTR
SOUND

8/17/2015 12:38:57 PM f=1.20 D:\Dropbox\Dropbox (Haddock Invention)\L3D\Electronics\16x16 cube\L3DCube_X16_Daughterboard_Rev3.sch (Sheet: 1/1)

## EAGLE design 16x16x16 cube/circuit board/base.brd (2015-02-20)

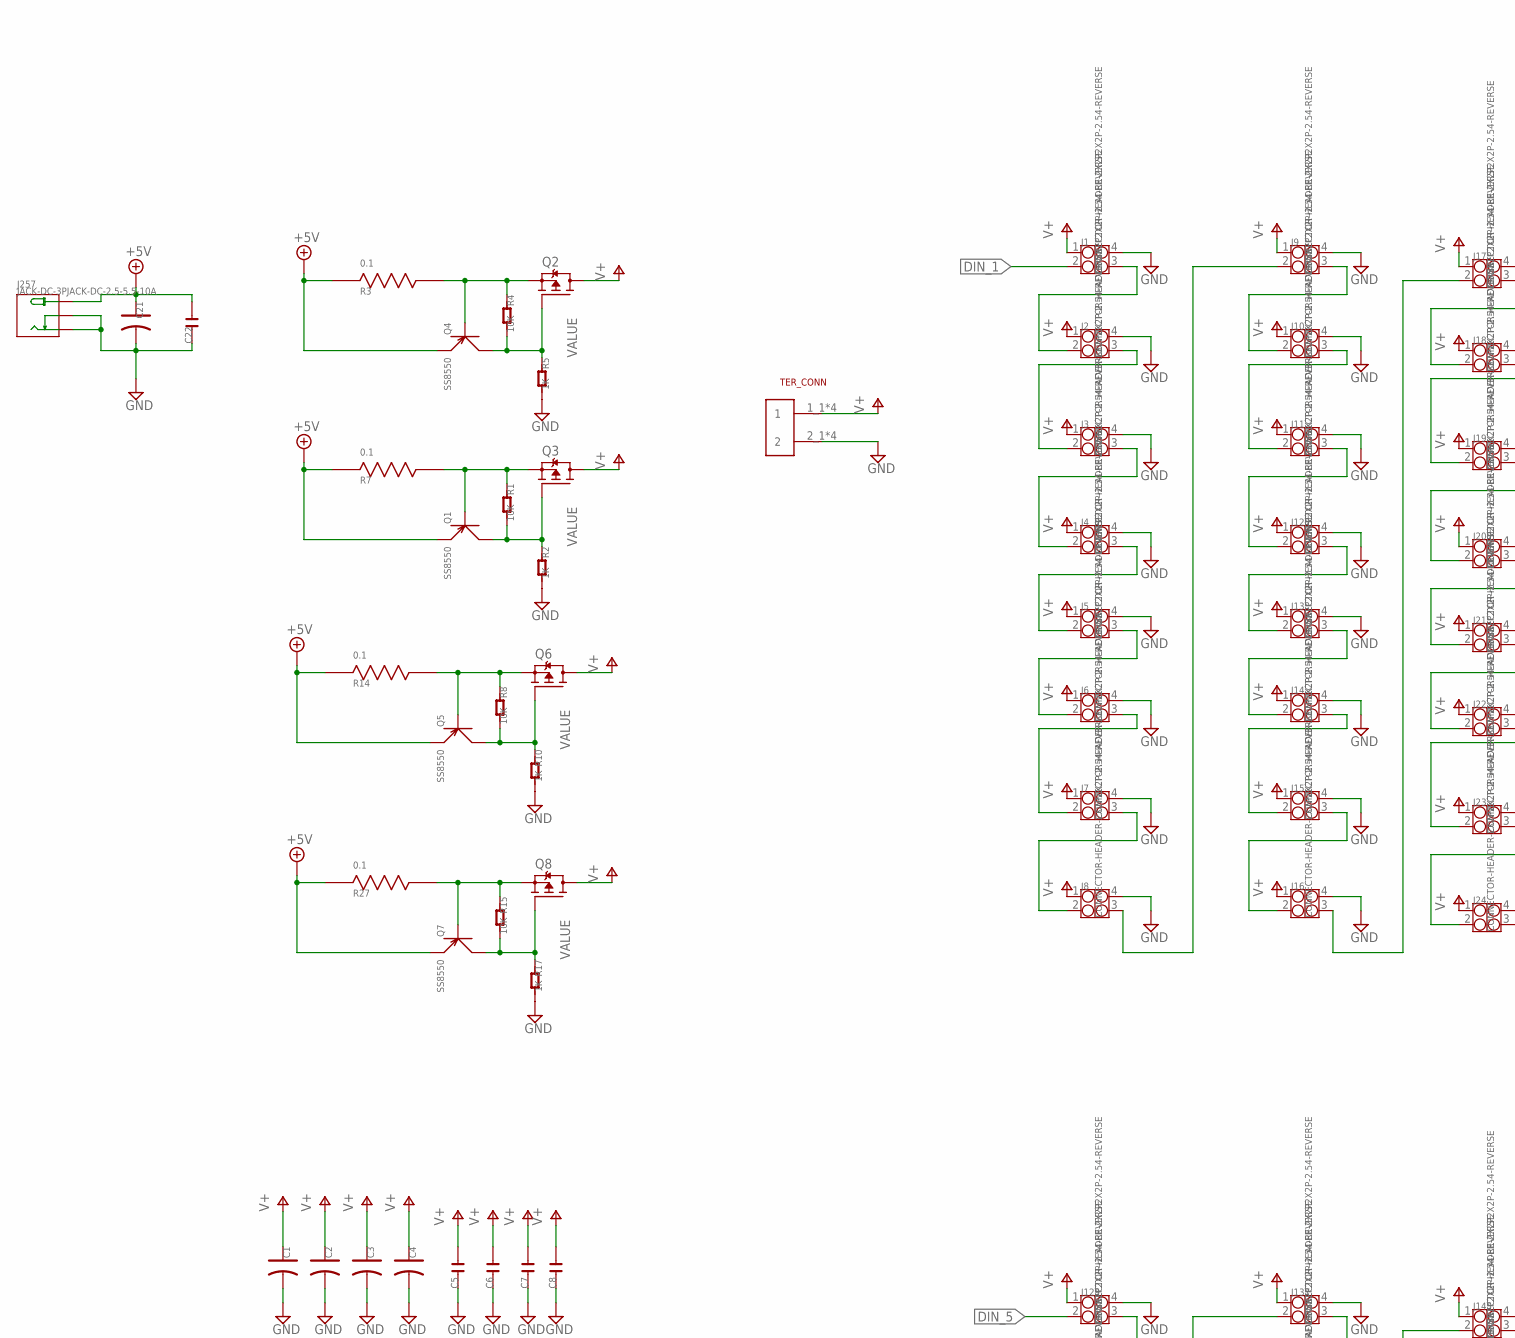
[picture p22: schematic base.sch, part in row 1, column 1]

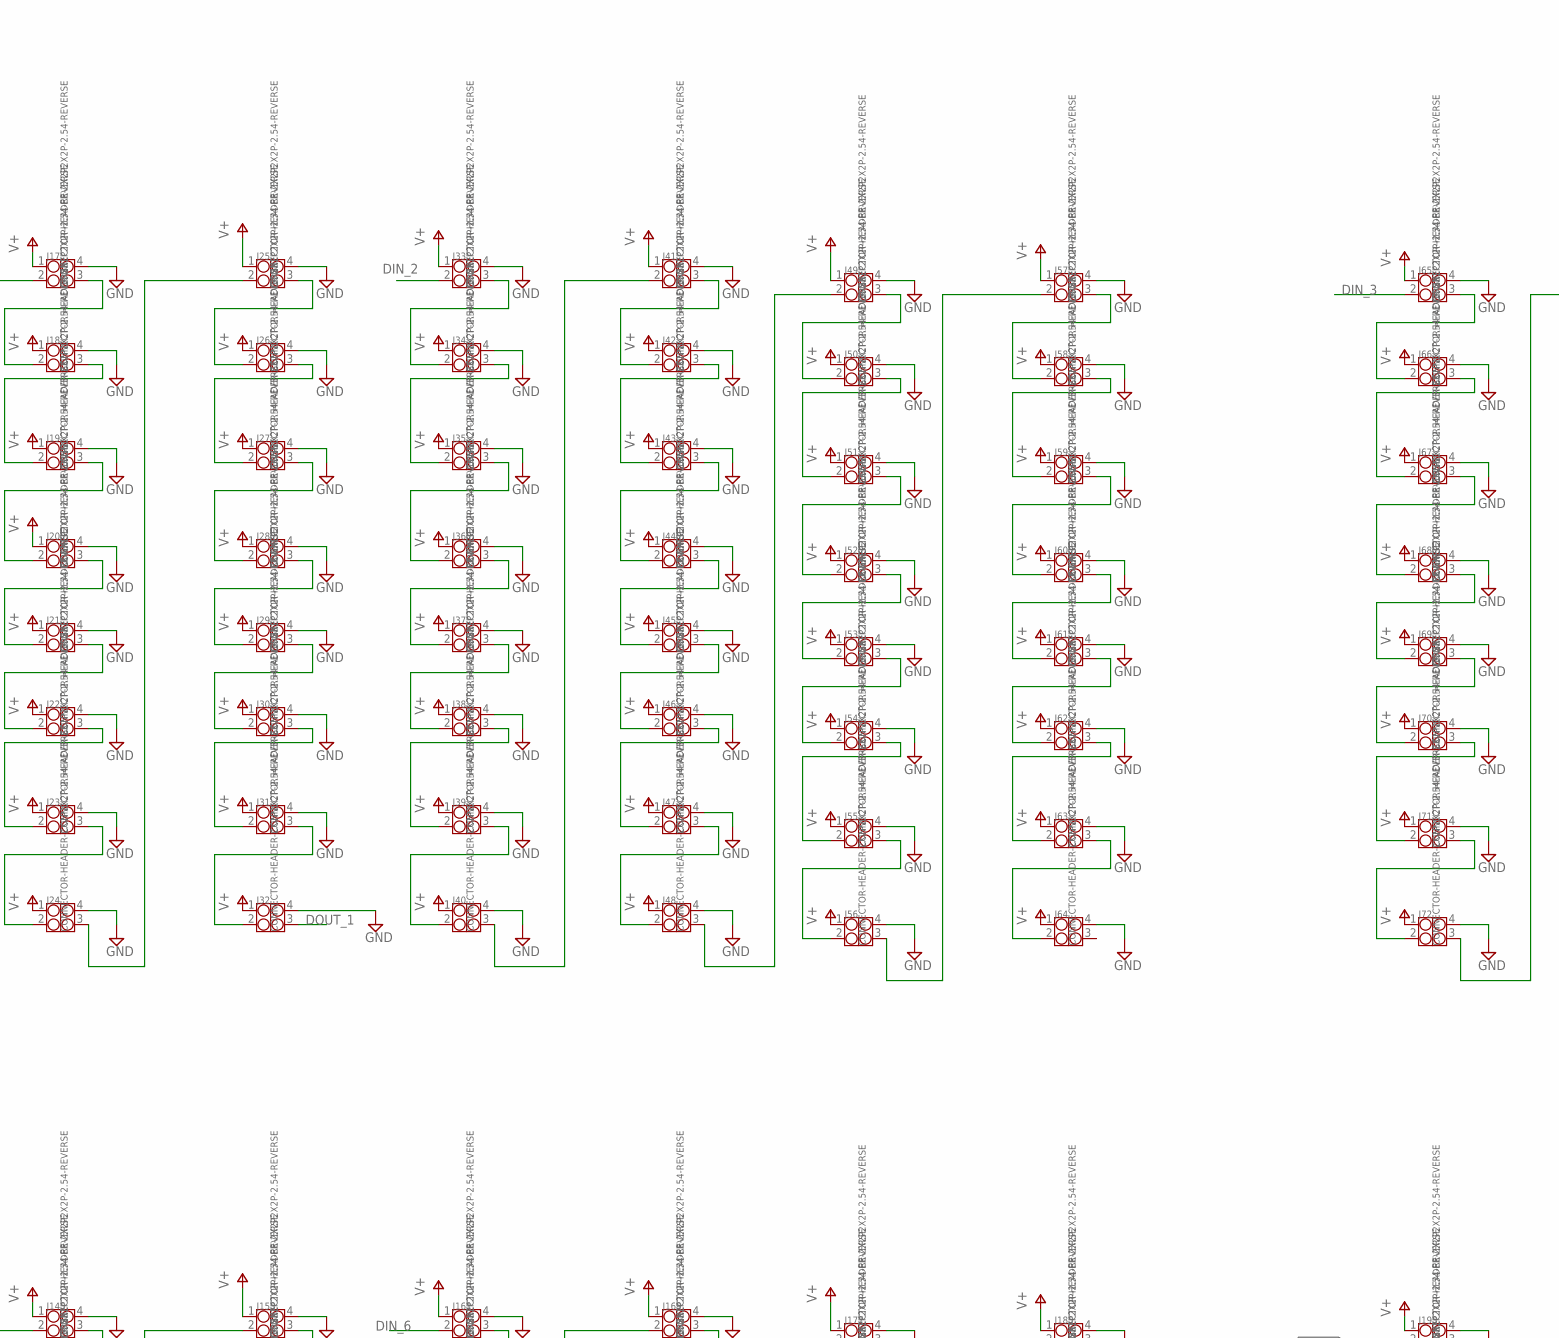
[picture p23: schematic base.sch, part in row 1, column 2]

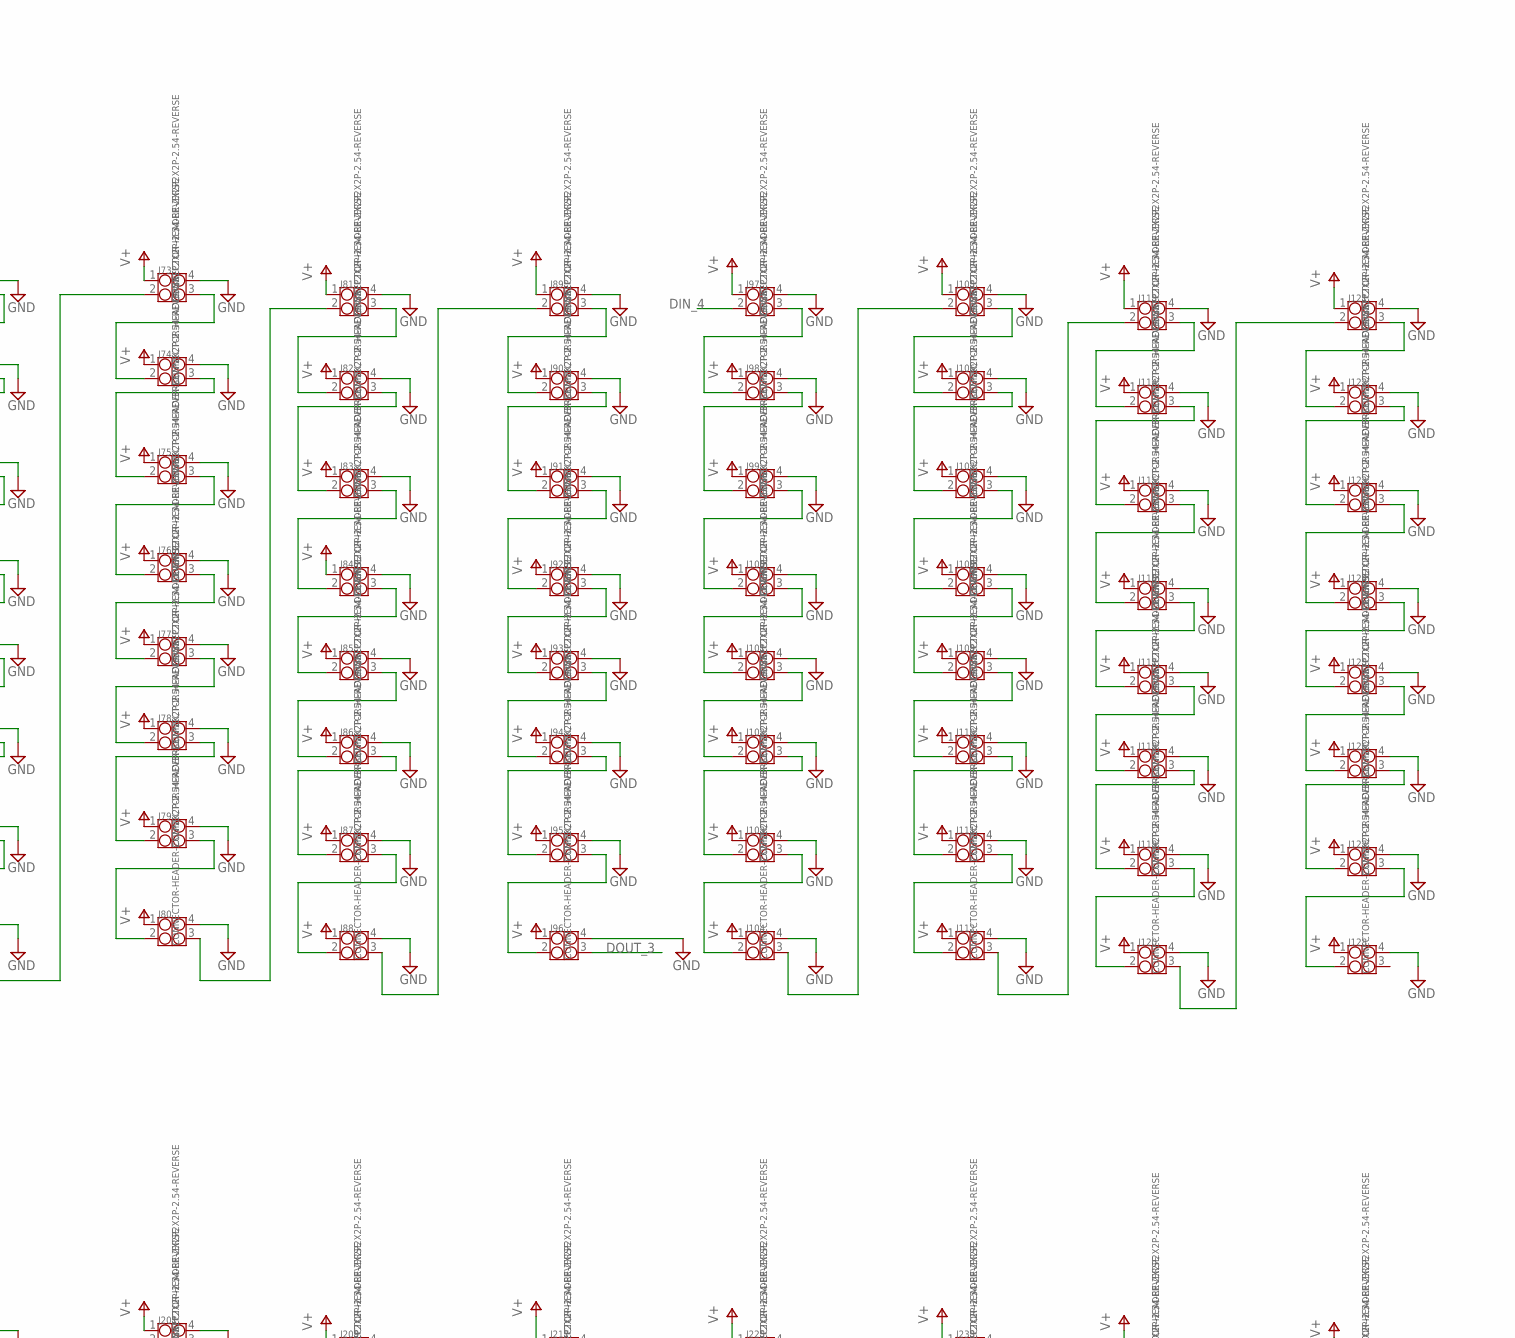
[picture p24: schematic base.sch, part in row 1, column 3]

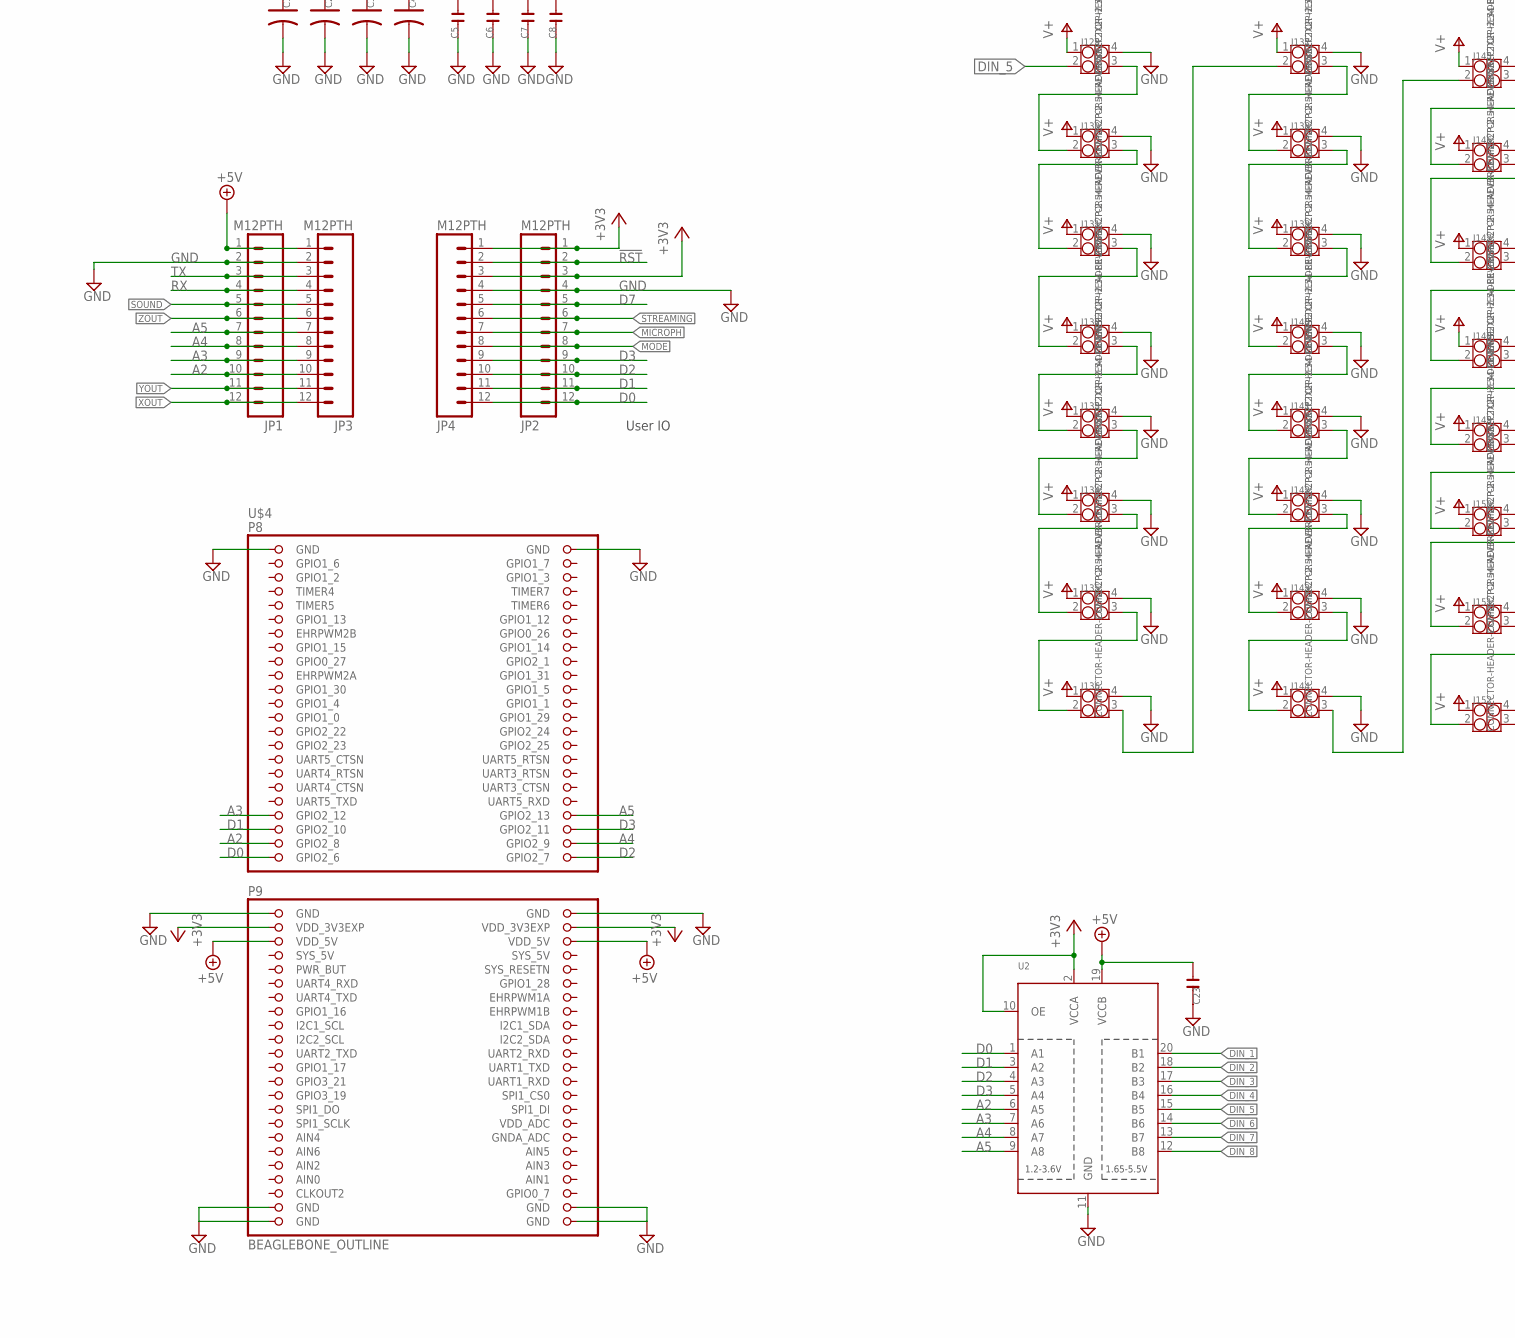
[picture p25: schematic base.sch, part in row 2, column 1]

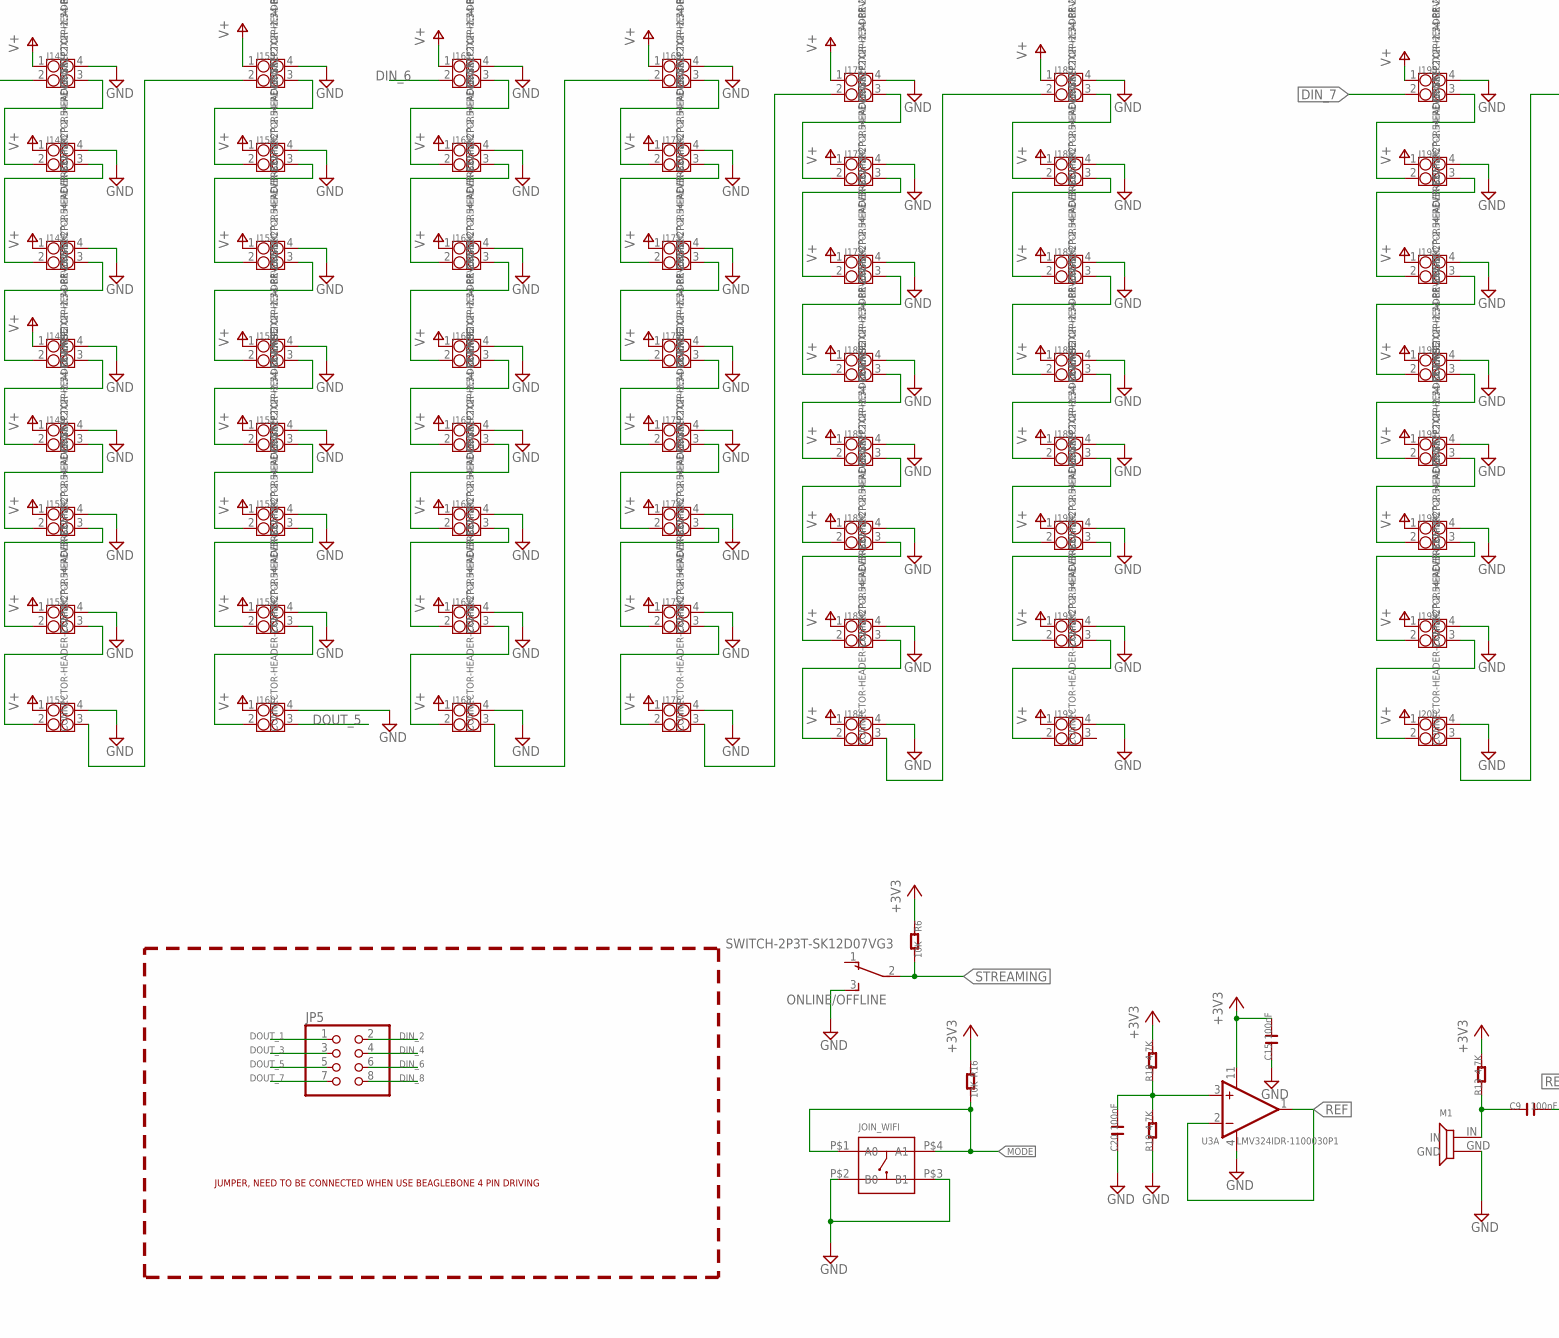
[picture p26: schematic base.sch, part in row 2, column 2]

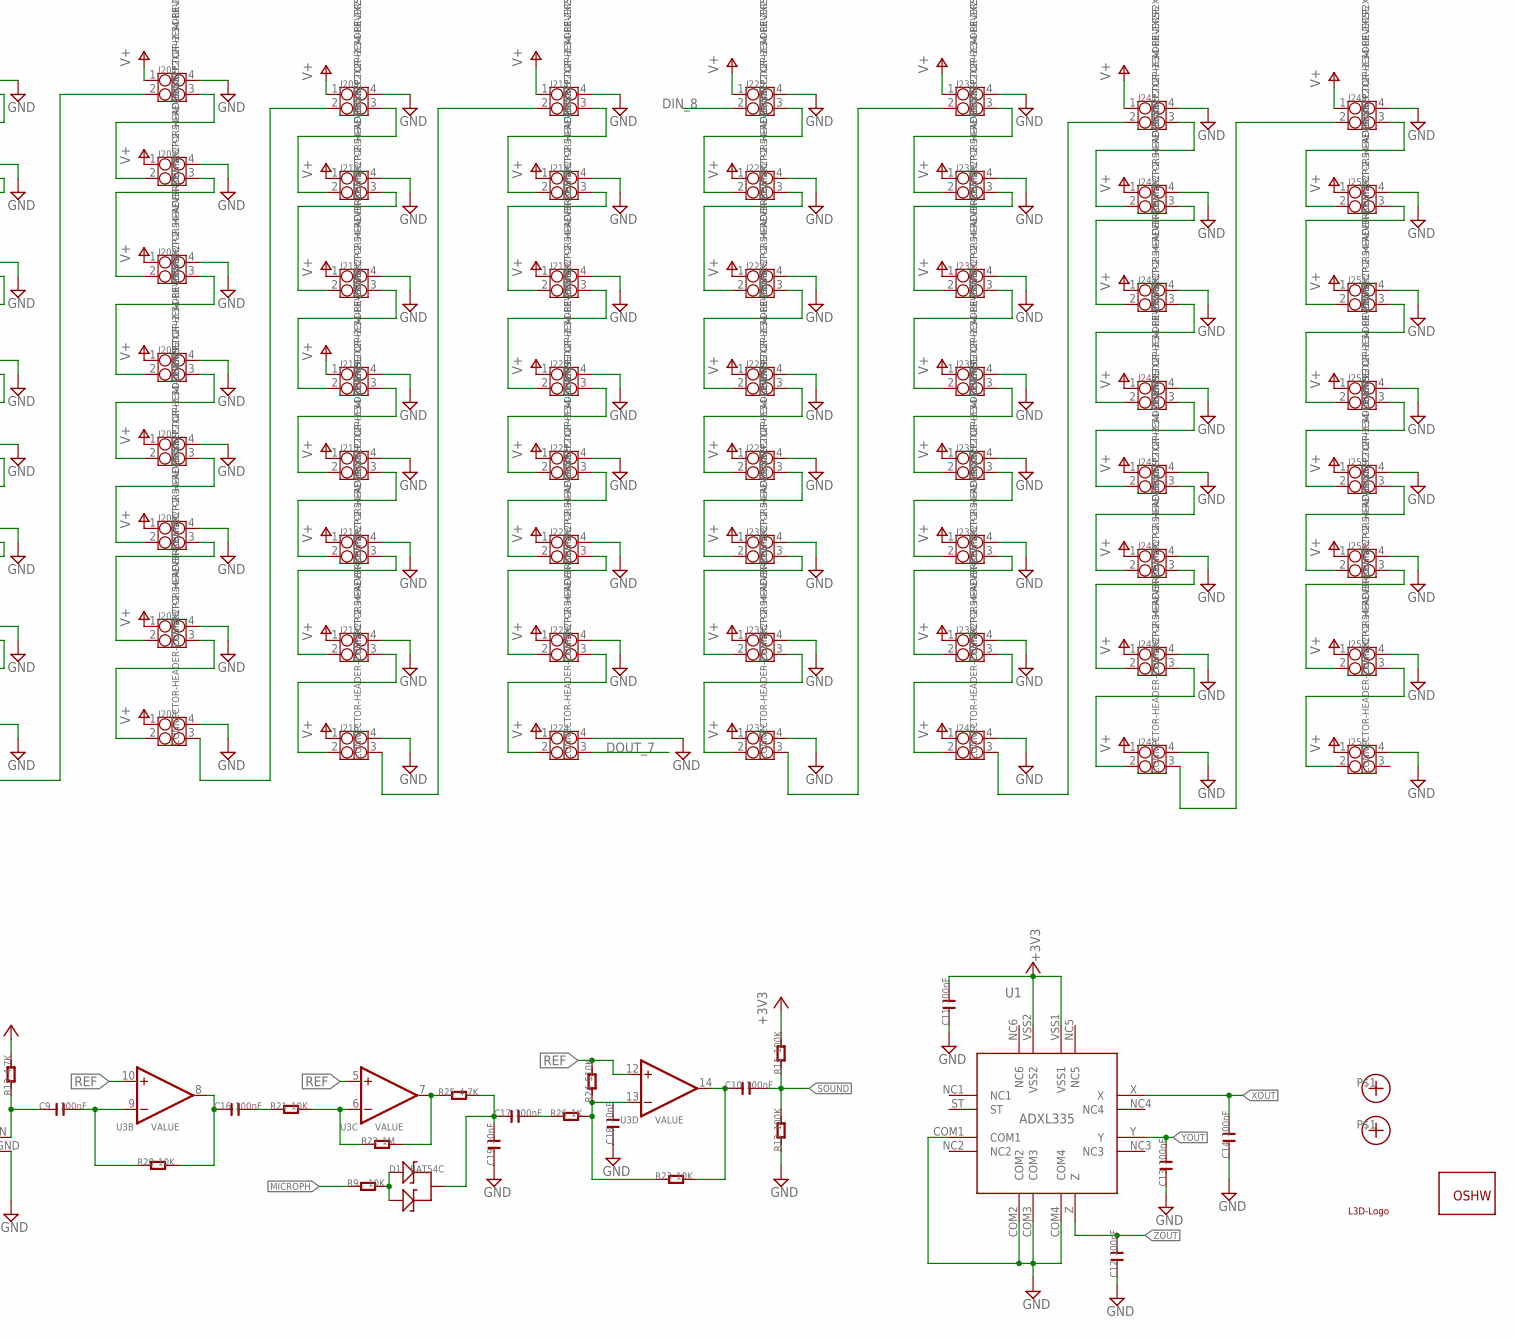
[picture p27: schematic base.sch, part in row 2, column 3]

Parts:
C1, C2, C3, C4, C21: C-POLAR; CAPACITOR-E3-8
C5, C6, C7, C8, C22, C23: C-0603; C0603
C9, C10, C11, C12, C13, C14, C15, C16, C17, C20: 100nF; C0603
C18, C19: 10nF; C0603
D1: BAT54C; SOT23
GOLD_ORB_SM1: OSHWLOGO_GOLD_ORB_LG; OSHW0
J1, J2, J3, J4, J5, J6, J7, J8, J9, J10, J11, J12, J13, J14, J15, J16, J17, J18, J19, J20, J21, J22, J23, J24, J25, J26, J27, J28, J29, J30, J31, J32, J33, J34, J35, J36, J37, J38, J39, J40, J41, J42, J43, J44, J45, J46, J47, J48, J49, J50, J51, J52, J53, J54, J55, J56, J57, J58, J59, J60, J61, J62, J63, J64, J65, J66, J67, J68, J69, J70, J71, J72, J73, J74, J75, J76, J77, J78, J79, J80, J81, J82, J83, J84, J85, J86, J87, J88, J89, J90, J91, J92, J93, J94, J95, J96, J97, J98, J99, J100, J101, J102, J103, J104, J105, J106, J107, J108, J109, J110, J111, J112, J113, J114, J115, J116, J117, J118, J119, J120, J121, J122, J123, J124, J125, J126, J127, J128, J129, J130, J131, J132, J133, J134, J135, J136, J137, J138, J139, J140, J141, J142, J143, J144, J145, J146, J147, J148, J149, J150, J151, J152, J153, J154, J155, J156, J157, J158, J159, J160, J161, J162, J163, J164, J165, J166, J167, J168, J169, J170, J171, J172, J173, J174, J175, J176, J177, J178, J179, J180, J181, J182, J183, J184, J185, J186, J187, J188, J189, J190, J191, J192, J193, J194, J195, J196, J197, J198, J199, J200, J201, J202, J203, J204, J205, J206, J207, J208, J209, J210, J211, J212, J213, J214, J215, J216, J217, J218, J219, J220, J221, J222, J223, J224, J225, J226, J227, J228, J229, J230, J231, J232, J233, J234, J235, J236, J237, J238, J239, J240, J241, J242, J243, J244, J245, J246, J247, J248, J249, J250, J251, J252, J253, J254, J255, J256: CONNECTOR-HEADER-2X2P2X2P-2.54-REVERSE; 2X2P-2.54-REVERSE
J257: JACK-DC-3PJACK-DC-2.5-5.5-10A; JACK-DC-2.5-5.5-10A
JOIN_WIFI: BUTTON-4P4P-12X12X6H; 4P-12X12X6H
JP1, JP2, JP3, JP4: M12PTH; 1X12-SMALL-PADS
JP5: PINHD-2X4; 2X04
M1: MICROPHONE
ONLINE/OFFLINE: SWITCH-2P3T-SK12D07VG3
Q1, Q4, Q5, Q7: SS8550; SOT23
Q2, Q3, Q6, Q8: FDD6637; TO252
R1, R4, R6, R8, R9, R15, R16, R20, R21, R23: 10K; R0603
R2, R5, R10, R17, R26: 1K; R0603
R3, R7, R14, R27: 0.1; RESISTOR-3W-20MM
R11, R12: 100K; R0603
R13, R18, R19, R25: 4.7K; R0603
R22: 1M; R0603
R24: 510K; R0603
TER_CONN: TERMINAL_CONN; TERMINALCONNECTOR_15MM
U1: ADXL335
U2: TXB0108PWR; TSSOP20
U3: LMV324IDR-1100030P1; SOIC14
U$1: L3D-LOGOL3DCUBE-LOGO-0.8X2.5; L3DCUBE-LOGO-0.8X2.5
U$2, U$3: FIDUCIAL-MARK
U$4: BEAGLEBONE_OUTLINE; BEAGLEBONE_SHIELD

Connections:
!RST: JP2.2, JP4.2
+3V3: C11.2, C15.2, JP2.1, JP2.3, JP4.1, JP4.3, R6.1, R11.2, R13.2, R16.1, R18.2, U1.VSS1, U1.VSS2, U2.2 (VCCA), U2.10 (OE), U3.11 (V-), U$4.49 (VDD_3V3EXP), U$4.50 (VDD_3V3EXP)
+5V: C21.+ (1), C22.2, C23.2, J257.+, JP1.1, JP3.1, Q1.2 (E), Q4.2 (E), Q5.2 (E), Q7.2 (E), R3.1, R7.1, R14.1, R27.1, U2.19 (VCCB), U$4.51 (VDD_5V), U$4.52 (VDD_5V)
A2: JP1.10, JP3.10, U2.6 (A5), U$4.43 (GPIO2_8)
A3: JP1.9, JP3.9, U2.7 (A6), U$4.39 (GPIO2_12)
A4: JP1.8, JP3.8, U2.8 (A7), U$4.44 (GPIO2_9)
A5: JP1.7, JP3.7, U2.9 (A8), U$4.40 (GPIO2_13)
AIN0: U$4.85 (AIN0)
D0: JP2.12, JP4.12, U2.1 (A1), U$4.45 (GPIO2_6)
D1: JP2.11, JP4.11, U2.3 (A2), U$4.41 (GPIO2_10)
D2: JP2.10, JP4.10, U2.4 (A3), U$4.46 (GPIO2_7)
D3: JP2.9, JP4.9, U2.5 (A4), U$4.42 (GPIO2_11)
D7: JP2.5, JP4.5
DIN_1: J1.2, U2.20 (B1)
DIN_2: J33.2, JP5.2, U2.18 (B2)
DIN_3: J65.2, U2.17 (B3)
DIN_4: J97.2, JP5.4, U2.16 (B4)
DIN_5: J129.2, U2.15 (B5)
DIN_6: J161.2, JP5.6, U2.14 (B6)
DIN_7: J193.2, U2.13 (B7)
DIN_8: J225.2, JP5.8, U2.12 (B8)
DOUT_1: J32.3, JP5.1
DOUT_3: J96.3, JP5.3
DOUT_5: J160.3, JP5.5
DOUT_7: J224.3, JP5.7
GND: C1.- (2), C2.- (2), C3.- (2), C4.- (2), C5.1, C6.1, C7.1, C8.1, C11.1, C12.1, C13.1, C14.1, C15.1, C18.1, C19.1, C20.1, C21.- (2), C22.1, C23.1, J1.4, J2.4, J3.4, J4.4, J5.4, J6.4, J7.4, J8.4, J9.4, J10.4, J11.4, J12.4, J13.4, J14.4, J15.4, J16.4, J17.4, J18.4, J19.4, J20.4, J21.4, J22.4, J23.4, J24.4, J25.4, J26.4, J27.4, J28.4, J29.4, J30.4, J31.4, J32.4, J33.4, J34.4, J35.4, J36.4, J37.4, J38.4, J39.4, J40.4, J41.4, J42.4, J43.4, J44.4, J45.4, J46.4, J47.4, J48.4, J49.4, J50.4, J51.4, J52.4, J53.4, J54.4, J55.4, J56.4, J57.4, J58.4, J59.4, J60.4, J61.4, J62.4, J63.4, J64.4, J65.4, J66.4, J67.4, J68.4, J69.4, J70.4, J71.4, J72.4, J73.4, J74.4, J75.4, J76.4, J77.4, J78.4, J79.4, J80.4, J81.4, J82.4, J83.4, J84.4, J85.4, J86.4, J87.4, J88.4, J89.4, J90.4, J91.4, J92.4, J93.4, J94.4, J95.4, J96.4, J97.4, J98.4, J99.4, J100.4, J101.4, J102.4, J103.4, J104.4, J105.4, J106.4, J107.4, J108.4, J109.4, J110.4, J111.4, J112.4, J113.4, J114.4, J115.4, J116.4, J117.4, J118.4, J119.4, J120.4, J121.4, J122.4, J123.4, J124.4, J125.4, J126.4, J127.4, J128.4, J129.4, J130.4, J131.4, J132.4, J133.4, J134.4, J135.4, J136.4, J137.4, J138.4, J139.4, J140.4, J141.4, J142.4, J143.4, J144.4, J145.4, J146.4, J147.4, J148.4, J149.4, J150.4, J151.4, J152.4, J153.4, J154.4, J155.4, J156.4, J157.4, J158.4, J159.4, J160.4, J161.4, J162.4, J163.4, J164.4, J165.4, J166.4, J167.4, J168.4, J169.4, J170.4, J171.4, J172.4, J173.4, J174.4, J175.4, J176.4, J177.4, J178.4, J179.4, J180.4, J181.4, J182.4, J183.4, J184.4, J185.4, J186.4, J187.4, J188.4, J189.4, J190.4, J191.4, J192.4, J193.4, J194.4, J195.4, J196.4, J197.4, J198.4, J199.4, J200.4, J201.4, J202.4, J203.4, J204.4, J205.4, J206.4, J207.4, J208.4, J209.4, J210.4, J211.4, J212.4, J213.4, J214.4, J215.4, J216.4, J217.4, J218.4, J219.4, J220.4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
MICROPH: JP2.7, JP4.7, R9.1
MODE: JOIN_WIFI.P$1 (A0), JOIN_WIFI.P$4 (A1), JP2.8, JP4.8, R16.2
unnamed: J1.3, J2.2
unnamed: J2.3, J3.2
unnamed: J3.3, J4.2
unnamed: J5.3, J6.2
unnamed: J6.3, J7.2
unnamed: J7.3, J8.2
unnamed: J4.3, J5.2
unnamed: J9.3, J10.2
unnamed: J10.3, J11.2
unnamed: J11.3, J12.2
unnamed: J13.3, J14.2
unnamed: J14.3, J15.2
unnamed: J15.3, J16.2
unnamed: J12.3, J13.2
unnamed: J17.3, J18.2
unnamed: J18.3, J19.2
unnamed: J19.3, J20.2
unnamed: J21.3, J22.2
unnamed: J22.3, J23.2
unnamed: J23.3, J24.2
unnamed: J20.3, J21.2
unnamed: J25.3, J26.2
unnamed: J26.3, J27.2
unnamed: J27.3, J28.2
unnamed: J29.3, J30.2
unnamed: J30.3, J31.2
unnamed: J31.3, J32.2
unnamed: J28.3, J29.2
unnamed: J8.3, J9.2
unnamed: J16.3, J17.2
unnamed: J24.3, J25.2
unnamed: J65.3, J66.2
unnamed: J33.3, J34.2
unnamed: J34.3, J35.2
unnamed: J35.3, J36.2
unnamed: J37.3, J38.2
unnamed: J38.3, J39.2
unnamed: J39.3, J40.2
unnamed: J36.3, J37.2
unnamed: J41.3, J42.2
unnamed: J42.3, J43.2
unnamed: J43.3, J44.2
unnamed: J45.3, J46.2
unnamed: J46.3, J47.2
unnamed: J47.3, J48.2
unnamed: J44.3, J45.2
unnamed: J49.3, J50.2
unnamed: J50.3, J51.2
unnamed: J51.3, J52.2
unnamed: J53.3, J54.2
unnamed: J54.3, J55.2
unnamed: J55.3, J56.2
unnamed: J52.3, J53.2
unnamed: J57.3, J58.2
unnamed: J58.3, J59.2
unnamed: J59.3, J60.2
unnamed: J61.3, J62.2
unnamed: J62.3, J63.2
unnamed: J63.3, J64.2
unnamed: J60.3, J61.2
unnamed: J40.3, J41.2
unnamed: J48.3, J49.2
unnamed: J56.3, J57.2
unnamed: Q2.2 (S), Q4.1 (B), R3.2, R4.1
unnamed: J66.3, J67.2
unnamed: J67.3, J68.2
unnamed: J69.3, J70.2
unnamed: J70.3, J71.2
unnamed: J71.3, J72.2
unnamed: J68.3, J69.2
unnamed: J73.3, J74.2
unnamed: J74.3, J75.2
unnamed: J75.3, J76.2
unnamed: J77.3, J78.2
unnamed: J78.3, J79.2
unnamed: J79.3, J80.2
unnamed: J76.3, J77.2
unnamed: J81.3, J82.2
unnamed: J82.3, J83.2
unnamed: J83.3, J84.2
unnamed: J85.3, J86.2
unnamed: J86.3, J87.2
unnamed: J87.3, J88.2
unnamed: J84.3, J85.2
unnamed: J89.3, J90.2
unnamed: J90.3, J91.2
unnamed: J91.3, J92.2
unnamed: J93.3, J94.2
unnamed: J94.3, J95.2
unnamed: J95.3, J96.2
unnamed: J92.3, J93.2
unnamed: J72.3, J73.2
unnamed: J80.3, J81.2
unnamed: J88.3, J89.2
unnamed: J97.3, J98.2
unnamed: J98.3, J99.2
unnamed: J99.3, J100.2
unnamed: J101.3, J102.2
unnamed: J102.3, J103.2
unnamed: J103.3, J104.2
unnamed: J100.3, J101.2
unnamed: J105.3, J106.2
unnamed: J106.3, J107.2
unnamed: J107.3, J108.2
unnamed: J109.3, J110.2
unnamed: J110.3, J111.2
unnamed: J111.3, J112.2
unnamed: J108.3, J109.2
unnamed: J113.3, J114.2
unnamed: J114.3, J115.2
unnamed: J115.3, J116.2
unnamed: J117.3, J118.2
unnamed: J118.3, J119.2
unnamed: J119.3, J120.2
unnamed: J116.3, J117.2
unnamed: J121.3, J122.2
unnamed: J122.3, J123.2
unnamed: J123.3, J124.2
unnamed: J125.3, J126.2
unnamed: J126.3, J127.2
unnamed: J127.3, J128.2
unnamed: J124.3, J125.2
unnamed: J104.3, J105.2
unnamed: J112.3, J113.2
unnamed: J120.3, J121.2
unnamed: Q2.1 (G), Q4.3 (C), R4.2, R5.1
unnamed: J129.3, J130.2
unnamed: J130.3, J131.2
unnamed: J131.3, J132.2
unnamed: J133.3, J134.2
unnamed: J134.3, J135.2
unnamed: J135.3, J136.2
unnamed: J132.3, J133.2
unnamed: J137.3, J138.2
unnamed: J138.3, J139.2
unnamed: J139.3, J140.2
unnamed: J141.3, J142.2
unnamed: J142.3, J143.2
unnamed: J143.3, J144.2
unnamed: J140.3, J141.2
unnamed: J145.3, J146.2
unnamed: J146.3, J147.2
unnamed: J147.3, J148.2
unnamed: J149.3, J150.2
unnamed: J150.3, J151.2
unnamed: J151.3, J152.2
unnamed: J148.3, J149.2
unnamed: J153.3, J154.2
unnamed: J154.3, J155.2
unnamed: J155.3, J156.2
unnamed: J157.3, J158.2
unnamed: J158.3, J159.2
unnamed: J159.3, J160.2
unnamed: J156.3, J157.2
unnamed: J136.3, J137.2
unnamed: J144.3, J145.2
unnamed: J152.3, J153.2
unnamed: J161.3, J162.2
unnamed: J162.3, J163.2
unnamed: J163.3, J164.2
unnamed: J165.3, J166.2
unnamed: J166.3, J167.2
unnamed: J167.3, J168.2
unnamed: J164.3, J165.2
unnamed: J169.3, J170.2
unnamed: J170.3, J171.2
unnamed: J171.3, J172.2
unnamed: J173.3, J174.2
unnamed: J174.3, J175.2
unnamed: J175.3, J176.2
unnamed: J172.3, J173.2
unnamed: J177.3, J178.2
unnamed: J178.3, J179.2
unnamed: J179.3, J180.2
unnamed: J181.3, J182.2
unnamed: J182.3, J183.2
unnamed: J183.3, J184.2
unnamed: J180.3, J181.2
unnamed: J185.3, J186.2
unnamed: J186.3, J187.2
unnamed: J187.3, J188.2
unnamed: J189.3, J190.2
unnamed: J190.3, J191.2
unnamed: J191.3, J192.2
unnamed: J188.3, J189.2
unnamed: J168.3, J169.2
unnamed: J176.3, J177.2
unnamed: J184.3, J185.2
unnamed: Q1.1 (B), Q3.2 (S), R1.1, R7.2
unnamed: J193.3, J194.2
unnamed: J194.3, J195.2
unnamed: J195.3, J196.2
unnamed: J197.3, J198.2
unnamed: J198.3, J199.2
unnamed: J199.3, J200.2
unnamed: J196.3, J197.2
unnamed: J201.3, J202.2
unnamed: J202.3, J203.2
unnamed: J203.3, J204.2
unnamed: J205.3, J206.2
unnamed: J206.3, J207.2
unnamed: J207.3, J208.2
unnamed: J204.3, J205.2
unnamed: J209.3, J210.2
unnamed: J210.3, J211.2
unnamed: J211.3, J212.2
unnamed: J213.3, J214.2
unnamed: J214.3, J215.2
unnamed: J215.3, J216.2
unnamed: J212.3, J213.2
unnamed: J217.3, J218.2
unnamed: J218.3, J219.2
unnamed: J219.3, J220.2
unnamed: J221.3, J222.2
unnamed: J222.3, J223.2
unnamed: J223.3, J224.2
unnamed: J220.3, J221.2
unnamed: J200.3, J201.2
unnamed: J208.3, J209.2
unnamed: J216.3, J217.2
unnamed: J225.3, J226.2
unnamed: J226.3, J227.2
unnamed: J227.3, J228.2
unnamed: J229.3, J230.2
unnamed: J230.3, J231.2
unnamed: J231.3, J232.2
unnamed: J228.3, J229.2
unnamed: J233.3, J234.2
unnamed: J234.3, J235.2
unnamed: J235.3, J236.2
unnamed: J237.3, J238.2
unnamed: J238.3, J239.2
unnamed: J239.3, J240.2
unnamed: J236.3, J237.2
unnamed: J241.3, J242.2
unnamed: J242.3, J243.2
unnamed: J243.3, J244.2
unnamed: J245.3, J246.2
unnamed: J246.3, J247.2
unnamed: J247.3, J248.2
unnamed: J244.3, J245.2
unnamed: J249.3, J250.2
unnamed: J250.3, J251.2
unnamed: J251.3, J252.2
unnamed: J253.3, J254.2
unnamed: J254.3, J255.2
unnamed: J255.3, J256.2
unnamed: J252.3, J253.2
unnamed: J232.3, J233.2
unnamed: J240.3, J241.2
unnamed: J248.3, J249.2
unnamed: Q1.3 (C), Q3.1 (G), R1.2, R2.1
unnamed: C9.1, M1.IN, R13.1
unnamed: C20.2, R18.1, R19.2, U3.3 (IN+)
unnamed: C9.2, R20.1, U3.9 (IN-)
unnamed: C16.1, R20.2, U3.8 (OUT)
unnamed: C16.2, R21.1
unnamed: R21.2, R22.1, U3.6 (IN-)
unnamed: C18.2, R23.1, R24.1, R26.2, U3.13 (IN-)
unnamed: C10.1, R23.2, U3.14 (OUT)
unnamed: C17.2, R26.1
unnamed: R22.2, R25.1, U3.7 (OUT)
unnamed: C17.1, C19.2, D1.3, R25.2
unnamed: D1.1, D1.2, R9.2
unnamed: Q5.1 (B), Q6.2 (S), R8.1, R14.2
unnamed: Q5.3 (C), Q6.1 (G), R8.2, R10.1
unnamed: Q7.1 (B), Q8.2 (S), R15.1, R27.2
unnamed: Q7.3 (C), Q8.1 (G), R15.2, R17.1
REF: R24.2, U3.1 (OUT), U3.2 (IN-), U3.5 (IN+), U3.10 (IN+), U3.12 (IN+)
RX: JP1.4, JP3.4
SOUND: C10.2, JP1.5, JP3.5, R11.1, R12.2
STREAMING: JP2.6, JP4.6, ONLINE/OFFLINE.2, R6.2
SYS_5V: U$4.53 (SYS_5V)
TX: JP1.3, JP3.3
V+: C1.+ (1), C2.+ (1), C3.+ (1), C4.+ (1), C5.2, C6.2, C7.2, C8.2, J1.1, J2.1, J3.1, J4.1, J5.1, J6.1, J7.1, J8.1, J9.1, J10.1, J11.1, J12.1, J13.1, J14.1, J15.1, J16.1, J17.1, J18.1, J19.1, J20.1, J21.1, J22.1, J23.1, J24.1, J25.1, J26.1, J27.1, J28.1, J29.1, J30.1, J31.1, J32.1, J33.1, J34.1, J35.1, J36.1, J37.1, J38.1, J39.1, J40.1, J41.1, J42.1, J43.1, J44.1, J45.1, J46.1, J47.1, J48.1, J49.1, J50.1, J51.1, J52.1, J53.1, J54.1, J55.1, J56.1, J57.1, J58.1, J59.1, J60.1, J61.1, J62.1, J63.1, J64.1, J65.1, J66.1, J67.1, J68.1, J69.1, J70.1, J71.1, J72.1, J73.1, J74.1, J75.1, J76.1, J77.1, J78.1, J79.1, J80.1, J81.1, J82.1, J83.1, J84.1, J85.1, J86.1, J87.1, J88.1, J89.1, J90.1, J91.1, J92.1, J93.1, J94.1, J95.1, J96.1, J97.1, J98.1, J99.1, J100.1, J101.1, J102.1, J103.1, J104.1, J105.1, J106.1, J107.1, J108.1, J109.1, J110.1, J111.1, J112.1, J113.1, J114.1, J115.1, J116.1, J117.1, J118.1, J119.1, J120.1, J121.1, J122.1, J123.1, J124.1, J125.1, J126.1, J127.1, J128.1, J129.1, J130.1, J131.1, J132.1, J133.1, J134.1, J135.1, J136.1, J137.1, J138.1, J139.1, J140.1, J141.1, J142.1, J143.1, J144.1, J145.1, J146.1, J147.1, J148.1, J149.1, J150.1, J151.1, J152.1, J153.1, J154.1, J155.1, J156.1, J157.1, J158.1, J159.1, J160.1, J161.1, J162.1, J163.1, J164.1, J165.1, J166.1, J167.1, J168.1, J169.1, J170.1, J171.1, J172.1, J173.1, J174.1, J175.1, J176.1, J177.1, J178.1, J179.1, J180.1, J181.1, J182.1, J183.1, J184.1, J185.1, J186.1, J187.1, J188.1, J189.1, J190.1, J191.1, J192.1, J193.1, J194.1, J195.1, J196.1, J197.1, J198.1, J199.1, J200.1, J201.1, J202.1, J203.1, J204.1, J205.1, J206.1, J207.1, J208.1, J209.1, J210.1, J211.1, J212.1, J213.1, J214.1, J215.1, J216.1, J217.1, J218.1, J219.1, J220.1, J221.1, J222.1, J223.1, J224.1, J225.1, J226.1, J227.1, J228.1, J229.1, J230.1, J231.1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
XOUT: C14.2, JP1.12, JP3.12, U1.X
YOUT: C13.2, JP1.11, JP3.11, U1.Y
ZOUT: C12.2, JP1.6, JP3.6, U1.Z

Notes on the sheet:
User IO
JUMPER, NEED TO BE CONNECTED WHEN USE BEAGLEBONE 4 PIN DRIVING

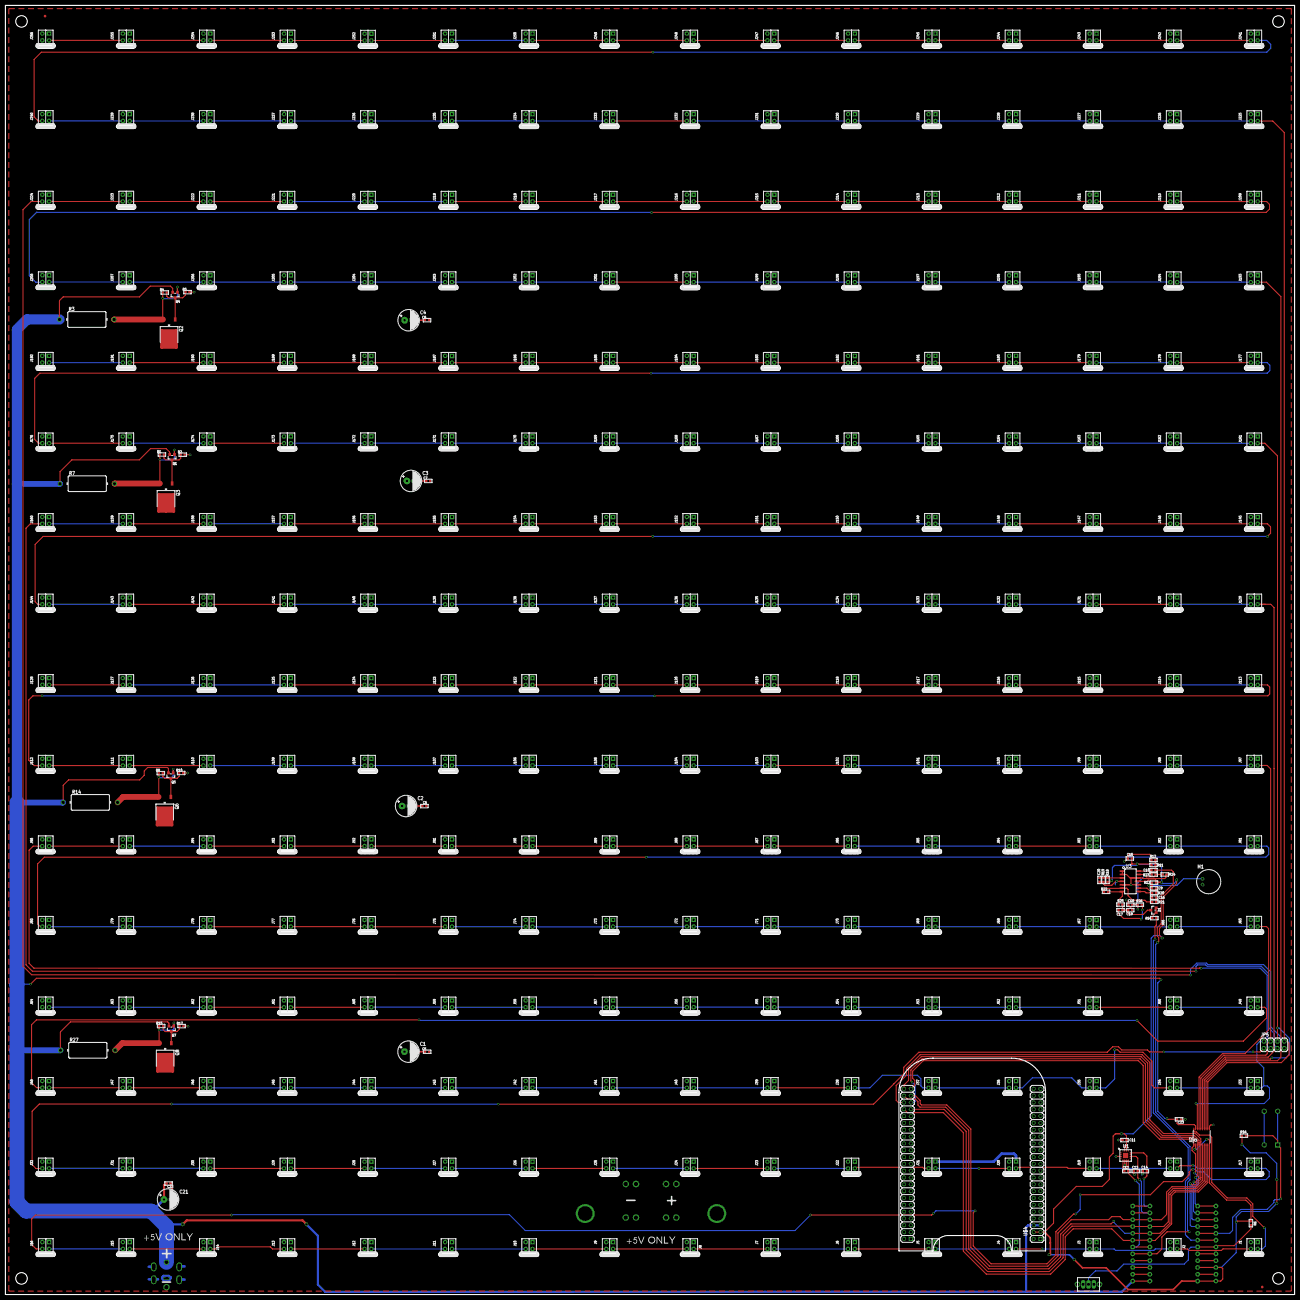
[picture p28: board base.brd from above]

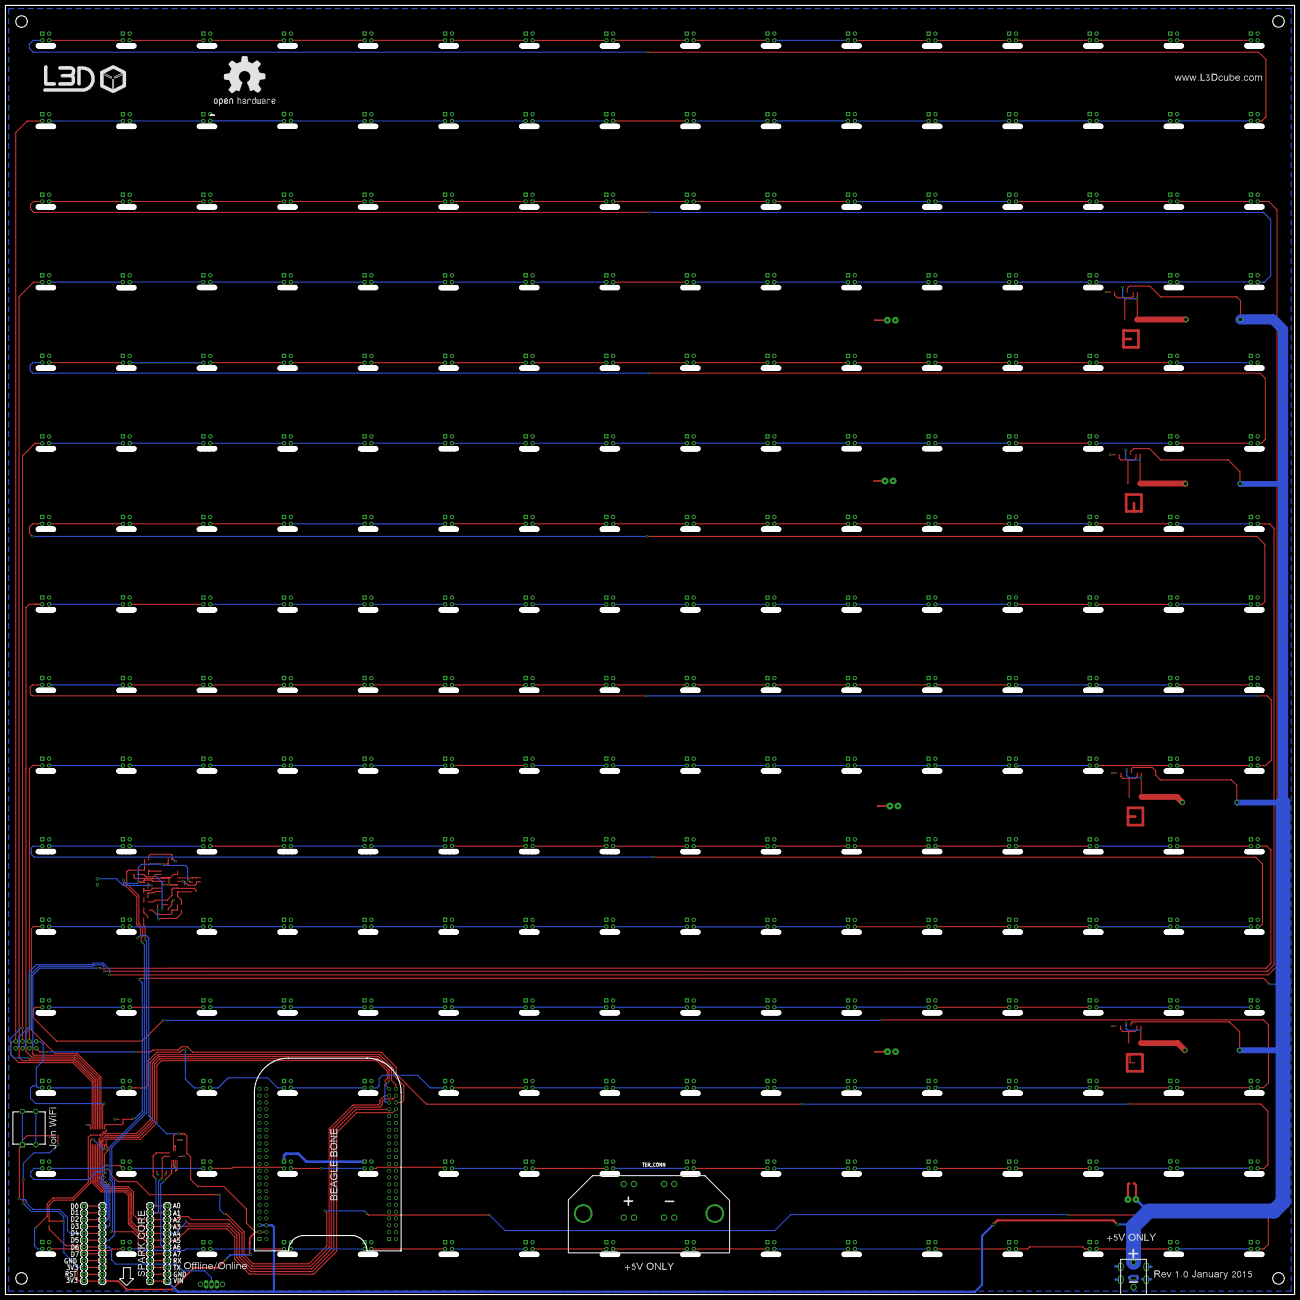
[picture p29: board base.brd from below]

Board: 2 copper layers, 480.0 x 480.0 mm, 333 parts (5 on the bottom side), 304 nets.

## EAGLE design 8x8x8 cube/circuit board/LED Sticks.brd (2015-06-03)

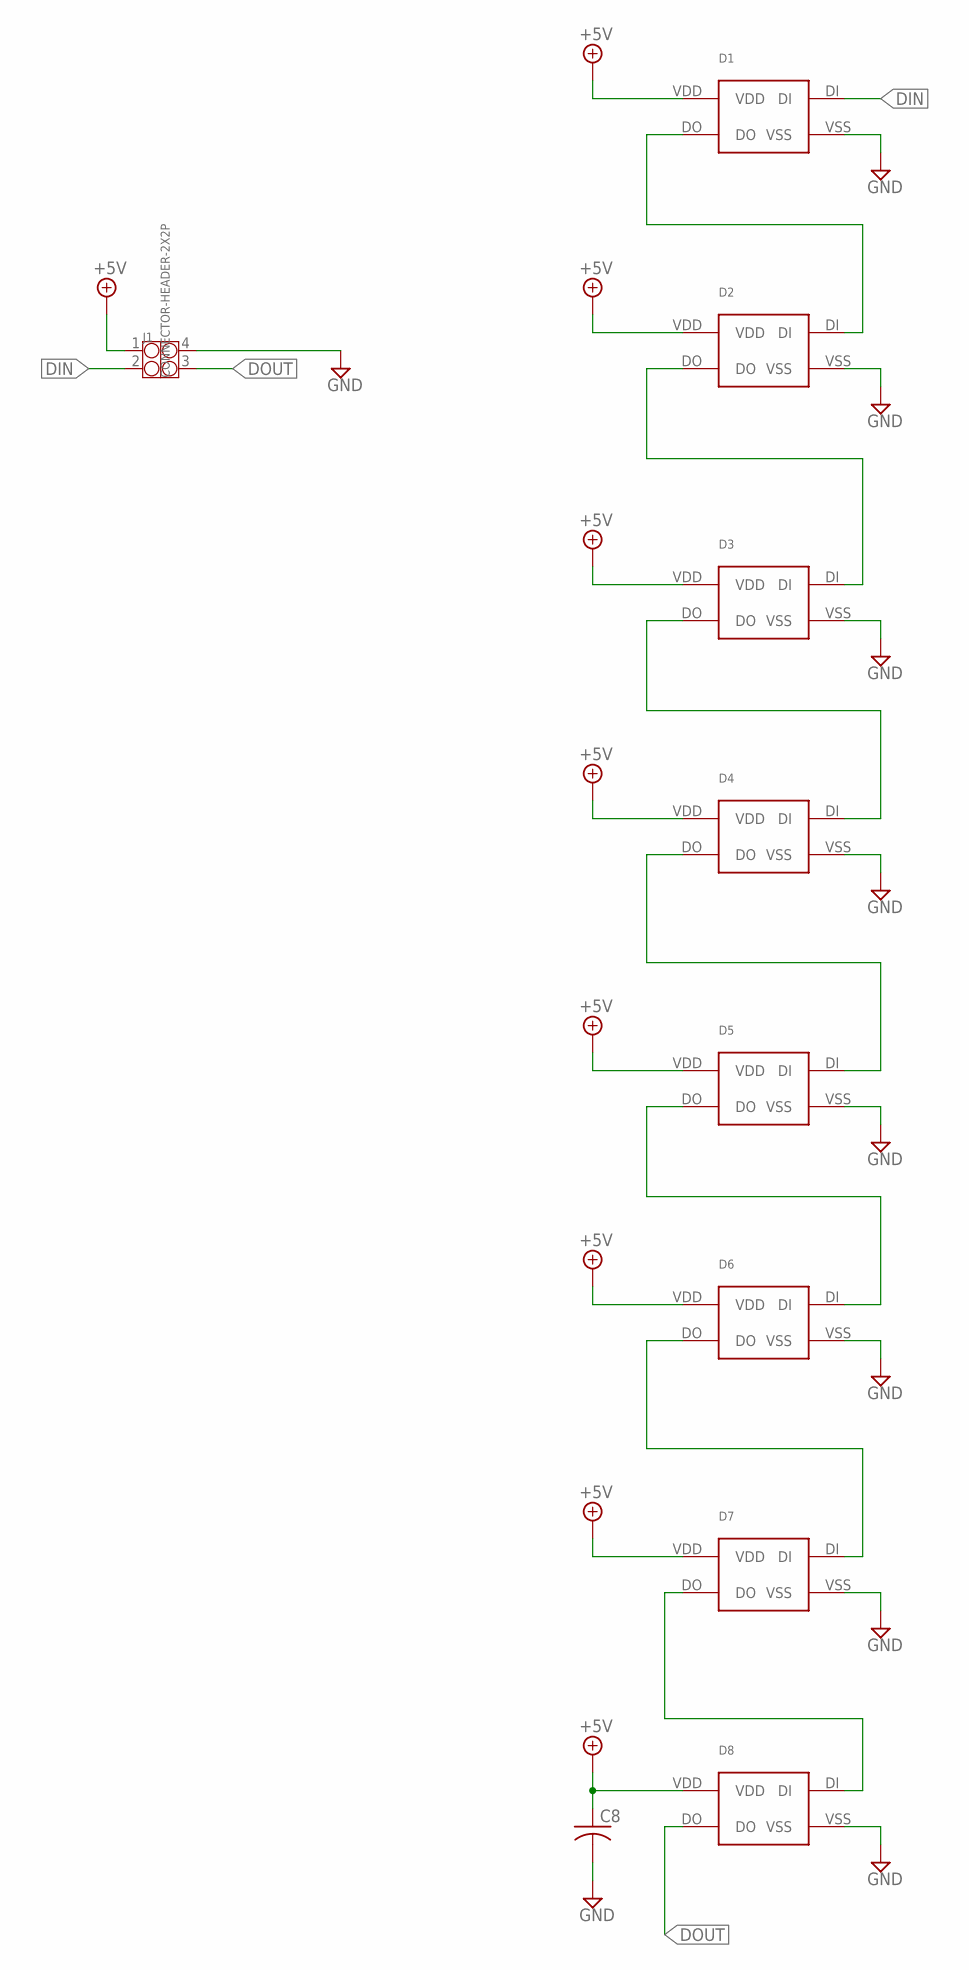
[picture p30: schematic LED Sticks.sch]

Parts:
C8: C-USC0603K; C0603K
D1, D2, D3, D4, D5, D6, D7, D8: WS2812B
J1: CONNECTOR-HEADER-2X2P; 2X2P-2.54

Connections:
+5V: C8.1, D1.VDD, D2.VDD, D3.VDD, D4.VDD, D5.VDD, D6.VDD, D7.VDD, D8.VDD, J1.1
DIN: D1.DI, J1.2
DOUT: D8.DO, J1.3
GND: C8.2, D1.VSS, D2.VSS, D3.VSS, D4.VSS, D5.VSS, D6.VSS, D7.VSS, D8.VSS, J1.4
unnamed: D1.DO, D2.DI
unnamed: D2.DO, D3.DI
unnamed: D3.DO, D4.DI
unnamed: D4.DO, D5.DI
unnamed: D5.DO, D6.DI
unnamed: D6.DO, D7.DI
unnamed: D7.DO, D8.DI

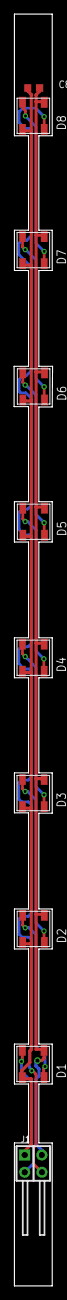
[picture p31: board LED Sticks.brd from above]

Board: 2 copper layers, 5.7 x 187.5 mm, 10 parts (0 on the bottom side), 11 nets.

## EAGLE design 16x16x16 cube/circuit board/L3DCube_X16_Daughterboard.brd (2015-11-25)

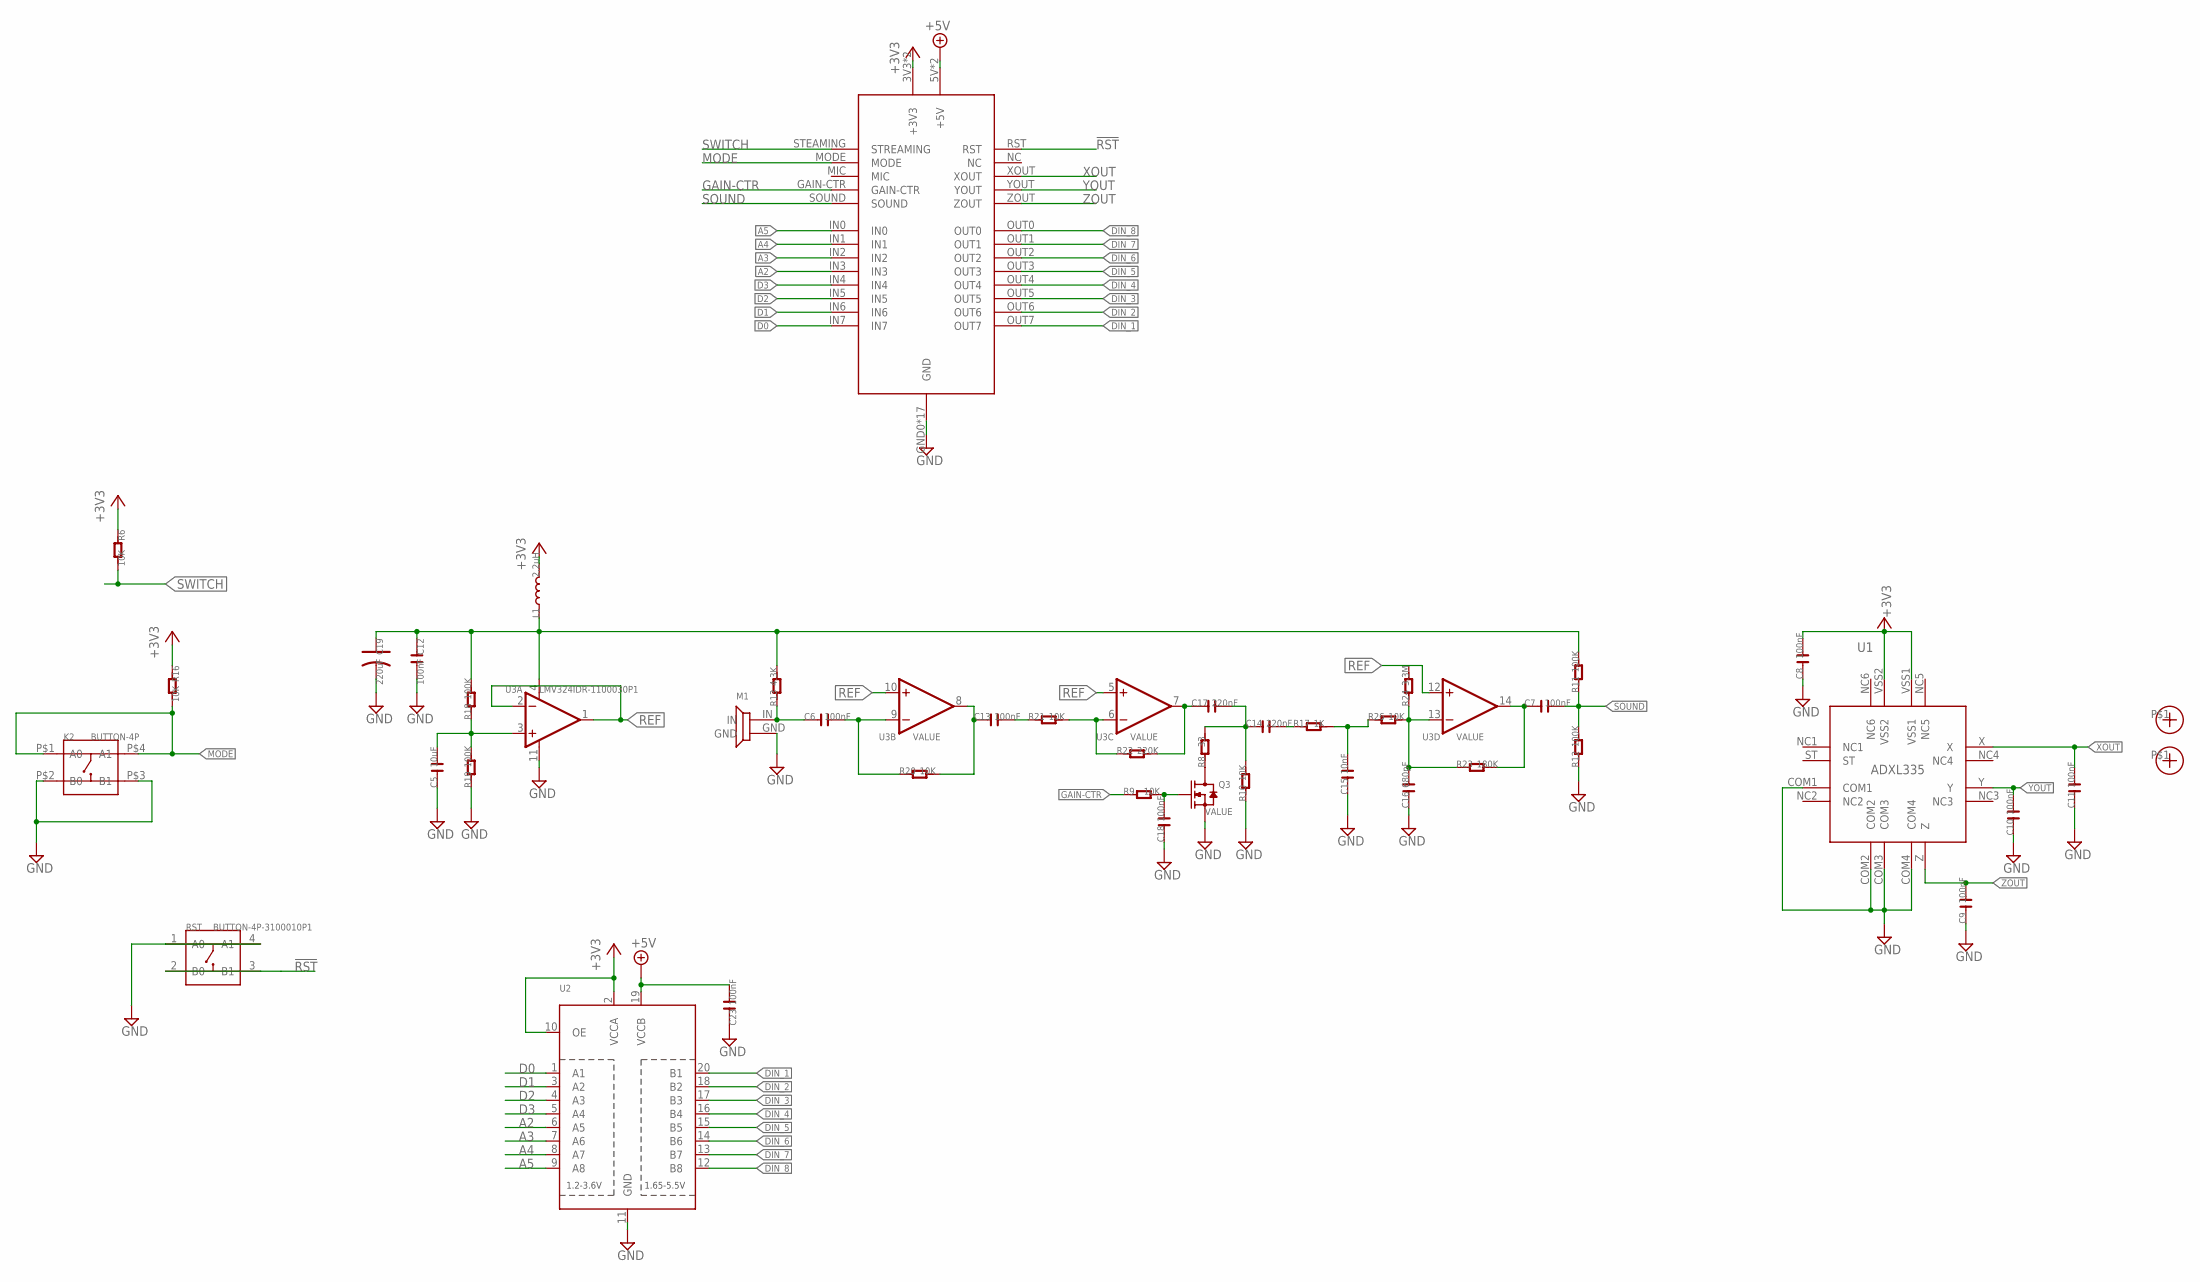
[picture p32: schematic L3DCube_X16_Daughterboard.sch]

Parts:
C5: 10uF; C0603
C6, C7, C8, C9, C10, C11, C12, C13, C18, C23: 100nF; C0603
C14, C17: 220nF; C0603
C15: 10nF; C0603
C16: 680pF; C0603
C19: 220uF; AVX-B
K2: BUTTON-4P; 4P-12X12X6-SMD
L1: 2.2uH; L0603
M1: MICROPHONE
Q3: 2N7002; SOT23
R6, R9, R10, R16, R20, R21, R26: 10K; R0603
R8: 33; R0603
R11, R12, R18, R19: 100K; R0603
R13: 4.3K; R0603
R17: 1K; R0603
R22: 220K; R0603
R23: 180K; R0603
R24: 3.3M; R0603
RST: BUTTON-4P-3100010P1; 4P-SMD-6.0X6.0X5.0H
U1: ADXL335
U2: TXB0108PWR; TSSOP20
U3: LMV324IDR-1100030P1; SOIC14
U$1: CUBE-16-DAUGHTERBOARD
U$2, U$3: FIDUCIAL-MARK

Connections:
!RST: RST.2 (B0), RST.3 (B1), U$1.RST
+3V3: C8.2, L1.2, R6.1, R16.1, U1.VSS1, U1.VSS2, U2.2 (VCCA), U2.10 (OE), U$1.3V3 (+3V3), U$1.3V3' (+3V3)
+5V: C23.2, U2.19 (VCCB), U$1.5V (+5V), U$1.5V' (+5V)
A2: U2.6 (A5), U$1.IN3
A3: U2.7 (A6), U$1.IN2
A4: U2.8 (A7), U$1.IN1
A5: U2.9 (A8), U$1.IN0
D0: U2.1 (A1), U$1.IN7
D1: U2.3 (A2), U$1.IN6
D2: U2.4 (A3), U$1.IN5
D3: U2.5 (A4), U$1.IN4
DIN_1: U2.20 (B1), U$1.OUT7
DIN_2: U2.18 (B2), U$1.OUT6
DIN_3: U2.17 (B3), U$1.OUT5
DIN_4: U2.16 (B4), U$1.OUT4
DIN_5: U2.15 (B5), U$1.OUT3
DIN_6: U2.14 (B6), U$1.OUT2
DIN_7: U2.13 (B7), U$1.OUT1
DIN_8: U2.12 (B8), U$1.OUT0
GAIN-CTR: R9.1, U$1.GAIN-CTR
GND: C5.1, C8.1, C9.1, C10.1, C11.1, C12.2, C15.1, C16.1, C18.1, C19.- (2), C23.1, K2.P$2 (B0), K2.P$3 (B1), M1.GND, Q3.2 (S), R10.1, R12.1, R19.1, RST.1 (A0), RST.4 (A1), U1.COM1, U1.COM2, U1.COM3, U1.COM4, U2.11 (GND), U3.11 (V-), U$1.GND0 (GND), U$1.GND1 (GND), U$1.GND2 (GND), U$1.GND3 (GND), U$1.GND4 (GND), U$1.GND5 (GND), U$1.GND7 (GND), U$1.GND8 (GND), U$1.GND9 (GND), U$1.GND10 (GND), U$1.GND11 (GND), U$1.GND13 (GND), U$1.GND14 (GND), U$1.GND15 (GND), U$1.GND16 (GND), U$1.GND17 (GND), U$1.P$37 (GND)
MIC: C6.1, M1.IN, R13.1
MODE: K2.P$1 (A0), K2.P$4 (A1), R16.2, U$1.MODE
unnamed: C18.2, Q3.1 (G), R9.2
unnamed: Q3.3 (D), R8.1
unnamed: C14.2, R17.1
unnamed: C15.2, R17.2, R26.1
unnamed: C16.2, R23.1, R24.1, R26.2, U3.13 (IN-)
unnamed: C5.2, R18.1, R19.2, U3.3 (IN+)
unnamed: C6.2, R20.1, U3.9 (IN-)
unnamed: C13.1, R20.2, U3.8 (OUT)
unnamed: C13.2, R21.1
unnamed: R21.2, R22.1, U3.6 (IN-)
unnamed: C14.1, C17.2, R8.2, R10.2
unnamed: C12.1, C19.+ (1), L1.1, R11.2, R13.2, R18.2, U3.4 (V+)
unnamed: C7.1, R23.2, U3.14 (OUT)
unnamed: C17.1, R22.2, U3.7 (OUT)
REF: R24.2, U3.1 (OUT), U3.2 (IN-), U3.5 (IN+), U3.10 (IN+), U3.12 (IN+)
SOUND: C7.2, R11.1, R12.2, U$1.SOUND
SWITCH: R6.2, U$1.STEAMING (STREAMING)
XOUT: C11.2, U1.X, U$1.XOUT
YOUT: C10.2, U1.Y, U$1.YOUT
ZOUT: C9.2, U1.Z, U$1.ZOUT

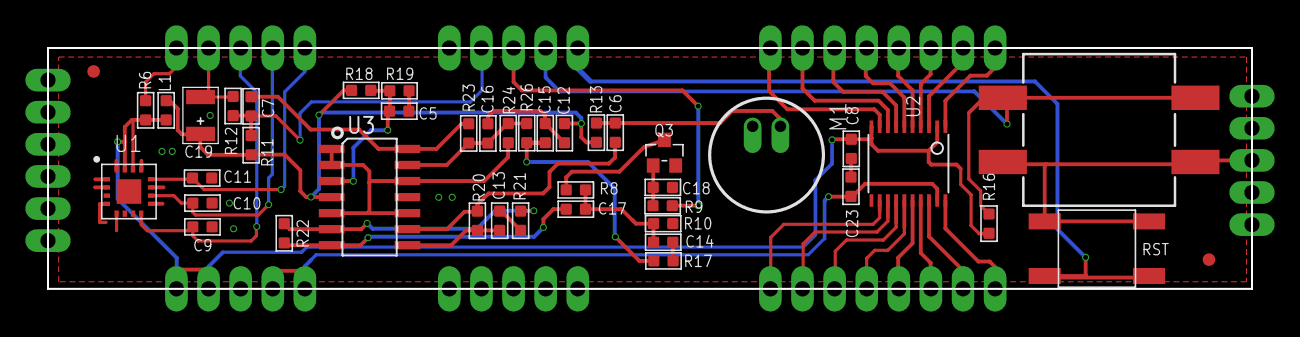
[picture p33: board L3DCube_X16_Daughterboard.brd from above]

Board: 2 copper layers, 95.2 x 19.1 mm, 44 parts (0 on the bottom side), 43 nets.

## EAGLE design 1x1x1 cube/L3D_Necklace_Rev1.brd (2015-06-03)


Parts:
B1: BUTTONCELLLIR1632; BUTTONCELL_LIR1632
C1, C9, C11, C12: 100nF; 0603
C2, C7: 100nF; C0603
C6: 10nF; C0603
D1: WS2812BWS2812B_STANDARD; WS2812B_STANDARD
D2: LEDLED1206; LED1206
J1: CONNECTOR-HEADER-2X3P2X3P-2.54-SMT; 2X3P-2.54-SMT
J2: VCC; 1R5MM-HOLE
J3: GND; 1R5MM-HOLE
J4: D0; 1R5MM-HOLE
J5: A0; 1R5MM-HOLE
JP1: USBUSB-MICROB-SLOT-HOLE; USB-MICROB-SLOT-HOLE
M1: MICROPHONEMICROPHONE_1*3MM; MICROPHONE_1*3MM
Q1: TRANSISTOR-NPN-0400000P1; SOT23
R1: 75k; 0603
R2: 100k; 0603
R3: 50; 0603
R4: 1k; 0603
R5: 10k; 0603
R6: 51; R0603
R7, R11, R12, R13, R17: 100K; R0603
R8, R9, R10: 10K; R0603
U1: MEGA8; MLF32X
U2: IC_SMD_FT232RQ; IC_SMD_QFN32
U3: LM358DRSOT23-8(M8); SOT-23-8(M8)
Y1: SMARTPRJ_RESONATORMU; SMARTPRJ_RESONATOR
Z1: TL431; SOT23

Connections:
3V3: C12.2, U2.1 (VCCIO), U2.16 (3V3OUT), U2.18 (!RESET)
A0: J5.P$1, U1.23 (PC0(ADC0))
ADC6: U1.19 (ADC6)
ADC7: U1.22 (ADC7)
AREF: U1.20 (AREF)
CTS: U2.8 (!CTS)
D2: D1.DI, U1.32 (PD2(INT0))
D3: J4.P$1, U1.1 (PD3(INT1))
D+: JP1.D+, U2.14 (USBDP)
D-: JP1.D-, U2.15 (USBDM)
DCD: U2.7 (!DCD)
DSR: U2.6 (!DSR)
DTR: C9.1, U2.31 (!DTR)
GND: B1.-, B1.-' (-), C1.2, C11.1, C12.1, D1.VSS, J1.4, J3.P$1, JP1.GND, JP1.MT1 (GND), JP1.MT2 (GND), JP1.MT3 (GND), JP1.MT4 (GND), JP1.MT5 (GND), JP1.MT6 (GND), JP1.MT7 (GND), JP1.MT8 (GND), JP1.MT9 (GND), JP1.MT10 (GND), JP1.MT11 (GND), JP1.MT12 (GND), JP1.P$1 (GND), JP1.P$2 (GND), JP1.P$3 (GND), JP1.P$4 (GND), M1.P$1 (GND), R2.2, R9.1, R10.1, R12.1, U1.3 (GND), U1.5 (GND), U1.21 (AGND), U1.HEAT, U2.4 (GND), U2.17 (GND), U2.20 (GND), U2.24 (GND), U2.26 (TEST), U2.EXP (GND), U3.8 (+V), Y1.2, Z1.3 (A)
unnamed: R1.2, R2.1, Z1.1 (R)
unnamed: Q1.1 (B), R4.1, Z1.2 (K)
unnamed: R8.2, U3.3 (+IN1)
unnamed: Q1.3 (C), R3.1
unnamed: C2.1, R17.1, U3.1 (OUT1)
unnamed: R6.1, U1.12 (PB0(ICP))
unnamed: D2.-, R6.2
unnamed: R10.2, R17.2, U3.2 (-IN1)
unnamed: C7.1, R7.1, U3.7 (OUT2)
unnamed: C2.2, U3.5 (+IN2)
unnamed: R7.2, R9.2, U3.6 (-IN2)
unnamed: C6.2, R8.1
unnamed: C6.1, M1.P$2 (IN), R13.1
PB3/MOSI: J1.5, U1.15 (PB3(MOSI/OC2))
PB4/MISO: J1.1, U1.16 (PB4(MISO))
PB5/SCK: J1.2, U1.17 (PB5(SCK))
PC4/SDA: U1.27 (PC4(ADC4/SDA))
PC5/SCL: U1.28 (PC5(ADC5/SCL))
PD0/RX: U1.30 (PD0(RXD)), U2.30 (TXD)
PD1/TX: U1.31 (PD1(TXD)), U2.2 (RXD)
RESET: C9.2, J1.3, R5.2, U1.29 (PC6(/RESET))
RI: U2.3 (!RI)
RTS: U2.32 (!RTS)
SOUND: C7.2, R11.1, R12.2, U1.24 (PC1(ADC1))
USB5V: C1.1, JP1.VBUS, R3.2, R4.2, U2.19 (VCC)
VCC: B1.+, B1.+1' (+), B1.P$3 (+), B1.P$4 (+), B1.P$5 (+), B1.P$6 (+), B1.P$7 (+), B1.P$8 (+), B1.P$9 (+), B1.P$10 (+), C11.2, D1.VDD, D2.+, J1.6, J2.P$1, Q1.2 (E), R1.1, R5.1, R11.2, R13.2, U1.4 (VCC), U1.6 (VCC), U1.18 (AVCC), U3.4 (GND)
XTAL1: U1.7 (PB6(XTAL1/TOSC1)), Y1.1
XTAL2: U1.8 (PB7(XTAL2/TOSC2)), Y1.3

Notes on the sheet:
L3D_Necklace_Rev1
LIR1632



Board: 2 copper layers, 23.0 x 23.0 mm, 37 parts (2 on the bottom side), 32 nets.

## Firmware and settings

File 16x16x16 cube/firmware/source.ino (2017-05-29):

#include <math.h>  
#include "application.h"
SYSTEM_THREAD(ENABLED);

// IMPORTANT: Set pixel COUNT, PIN and TYPE
#define PIXEL_PIN D0
#define totalPIXEL 4096
#define stripPIXEL totalPIXEL/8    //THERE IS FOUR PINS TO DRIVE EACH STRIPS
#define PIXEL_TYPE WS2812B

#define SIZE 16
#define PI 3.14159



/**********************************
 * flip variables *
 * ********************************/
 //accelerometer pinout
#define X A0
#define Y A1
#define Z A6
#define NUM_SAMPLES 100
int accelerometer[3];
unsigned long totals[3];
int runningAverage[3];
boolean whack[3];
boolean whacked=false;
#define WHACK_X 20
#define WHACK_Y 20
#define WHACK_Z 20

bool autoCycle=true;    //start on autocycle by default

/*******************************
 * fade variables *
 * ****************************/
bool fading=false;
int fadeValue=255;
int fadeSpeed=2;

/*  datatype definitions
*/

/**   An RGB color. */
struct Color
{
  unsigned char red, green, blue;

  Color(int r, int g, int b) : red(r), green(g), blue(b) {}
  Color() : red(0), green(0), blue(0) {}
};

/**   A point in 3D space.  */
struct Point
{
  float x;
  float y;
  float z;
  Point() : x(0), y(0), z(0) {}
  Point(float _x, float _y, float _z) : x(_x), y(_y), z(_z) {}
};

struct Rocket
{
	float x,y,z;
	float xVel, yVel, zVel;
	float gravity;
	Color col;	
	Rocket():x((SIZE-1)/2), y(0), z((SIZE-1)/2), col(Color(255,0,0)){}
};


#define NUM_ROCKETS 50
Rocket rockets[NUM_ROCKETS];
float offset=0;

int y=0;
int yinc=1;
int maxBrightness=50;

#define FIREWORKS 0
#define CIRCLES 1
#define ROMAN_CANDLE 2
#define FFT_JOY 3

int demo=FIREWORKS;

#define MICROPHONE A7
#define GAIN_CONTROL D5

#define NUM_SAMPLES 2222
float micAverage;   

/*********************************
 * FFTJoy variables *
 * *******************************/
#define M 5
float real[(int)pow(2,M)];
float imaginary[(int)pow(2,M)];
float maxValue=0;
float sample;


/******************************
 * fireworks variables *
 * ****************************/
int centerX, centerY, centerZ;
int launchX, launchZ;
int red, green, blue;
float radius=0;
float speed;
bool showRocket;
bool exploded;
bool dead;
float xInc, yInc, zInc;
float rocketX, rocketY, rocketZ;
float launchTime;
int maxSize;
int fireworkRes;
Color rocketColor, fireworkColor;

uint8_t PIXEL_RGB[totalPIXEL*3];  //EACH PIXELS HAS 3 BYTES DATA

void setVoxel(int x, int y, int z, Color col);
void setVoxel(Point p, Color col);
Color getVoxel(int x, int y, int z);
Color getVoxel(Point p);
void line(Point p1, Point p2, Color col);
void line(int x1, int y1, int z1, int x2, int y2, int z2, Color col);
void sphere(Point center, float radius, Color col);
void sphere(Point center, float radius, Color col, int res);
void sphere(float x, float y, float z, float radius, Color col);
void sphere(float x, float y, float z, float radius, Color col, int res);
void background(Color col);
Color colorMap(float val, float minVal, float maxVal);
Color lerpColor(Color a, Color b, int val, int minVal, int maxVal);
Point add(Point a, Point b);

#define DEMO_ROUTINES 4

int frame;

Point poly1[4];
float poly1Angles[4];
float poly1AnglesInc[4];

Point poly2[4];
float poly2Angles[4];
float poly2AnglesInc[4];

Point poly3[4];
float poly3Angles[4];
float poly3AnglesInc[4];

float poly1Color, poly2Color, poly3Color;
float poly1ColorInc=0.001, poly2ColorInc=0.0005, poly3ColorInc=0.0007;

Point center;
unsigned int lastDemo=0;
#define DEMO_TIME 30000
int timeout=0;

bool onlinePressed=false;
bool lastOnline=true;
#define BUTTON D6 //press this button to connect to the internet
#define MODE D4

void setup() 
{
    randomSeed(analogRead(A0));
    Serial.begin(115200);
	  pinMode(GAIN_CONTROL, OUTPUT);
  	  digitalWrite(GAIN_CONTROL, LOW);
    micAverage=analogRead(MICROPHONE);
    for(int i=0;i<NUM_SAMPLES;i++)
    	micAverage=micAverage+(analogRead(MICROPHONE)-micAverage)/NUM_SAMPLES;
    initFireworks();
    initCircles();
    initRockets();
    initAccelerometer();
    pinMode(D0,OUTPUT);  //PB7
    pinMode(D1,OUTPUT); //PB6
    pinMode(D2,OUTPUT);  //BP5
    pinMode(D3,OUTPUT);  //PB4
    pinMode(A2,OUTPUT);  //PA4
    pinMode(A3,OUTPUT); //PA5
    pinMode(A4,OUTPUT);  //BA6
    pinMode(A5,OUTPUT);  //PA7

    pinMode(D7, OUTPUT);
    digitalWrite(D7, HIGH);
}

//initializes the running average values for the accelerometer
//I just set them to the first reading of the accelerometer on boot -- this is an imperfect method, 
//but it gets the rolling average very close it its eventual value
//I chose to base it off of each cube's individual ADC reading, rather than hardcode the values from my sample cube
void initAccelerometer()
{
	runningAverage[0]=analogRead(X);
	runningAverage[1]=analogRead(Y);
	runningAverage[2]=analogRead(Z);
}

void updateAccelerometer()
{
	accelerometer[0]=analogRead(X);
	accelerometer[1]=analogRead(Y);
	accelerometer[2]=analogRead(Z);
	for(int i=0;i<3;i++)
	{
		totals[i]+=accelerometer[i];	
		//sweet running average algorithm:  average[i+1]=average[i]+(sample[i]-average[i])/NUM_SAMPLES
		//I average over 100 samples, or ~2.5 seconds
		runningAverage[i]=runningAverage[i]+((accelerometer[i]-runningAverage[i])/NUM_SAMPLES);
		whack[i]=false;
	}	
	if(abs(accelerometer[0]-runningAverage[0])>WHACK_X)
		whack[0]=true;
	if(abs(accelerometer[1]-runningAverage[1])>WHACK_Y)
		whack[1]=true;
	if(abs(accelerometer[2]-runningAverage[2])>WHACK_Z)
		whack[2]=true;
	whacked=whack[0] | whack[1] | whack[2];	
}

void initRockets()
{
    for(int i=0;i<NUM_ROCKETS;i++)
    {
		rockets[i].gravity=-0.01;
		rockets[i].y=0;
		rockets[i].x=center.x;
		rockets[i].z=center.z;
		rockets[i].col=Color(255,0,0);	
		rockets[i].xVel=-.5;//(random(10)/10)-0.5;
		rockets[i].yVel=0.25;//random(10)/10;
		rockets[i].zVel=0.25;//(random(10)/10)-0.5;
     }
}

void initCircles()
{
    center=Point((SIZE-1)/2,(SIZE-1)/2,(SIZE-1)/2);
    for(int i=0;i<4;i++)
    {
        poly1Angles[i]=random(6.28);
        poly2Angles[i]=random(6.28);
        poly3Angles[i]=random(6.28);
    }
    poly1AnglesInc[0]=random(10)/100 - 0.05;
    poly1AnglesInc[1]=random(20)/100 - 0.1;
    poly1AnglesInc[2]=random(10)/100 - 0.05;
    poly1AnglesInc[3]=random(20)/100 - 0.1;

    poly2AnglesInc[0]=random(20)/100 - 0.1;
    poly2AnglesInc[1]=random(20)/100 - 0.1;
    poly2AnglesInc[2]=random(20)/100 - 0.1;
    poly2AnglesInc[3]=random(20)/100 - 0.1;

    poly3AnglesInc[0]=random(20)/100 - 0.1;
    poly3AnglesInc[1]=random(20)/100 - 0.1;
    poly3AnglesInc[2]=random(20)/100 - 0.1;
    poly3AnglesInc[3]=random(20)/100 - 0.1;
}


void romanCandle()
{
  background(Color(0,0,0));
    for(int i=0;i<pow(2,M);i++)
    {
        real[i]=analogRead(MICROPHONE)-993;  //adapted for the 0.8v bias point of the big cube 
        delayMicroseconds(212);  
        imaginary[i]=0;
    }
    FFT(1, M, real, imaginary);
    for(int i=0;i<pow(2,M);i++)
    {
        imaginary[i]=sqrt(pow(imaginary[i],2)+pow(real[i],2));
        if(imaginary[i]>maxValue)
            maxValue=imaginary[i];
    }
    if(maxValue>100)
        maxValue--;
    int rocketsToFire=0;
    for(int i=0;i<pow(2,M)/2;i++)
    {
        imaginary[i]=SIZE*imaginary[i]/maxValue;
	if(imaginary[i]>SIZE/2)
		rocketsToFire++;
    }	

	    for(int i=0;i<NUM_ROCKETS;i++)
	    {
		rockets[i].yVel+=rockets[i].gravity;
		rockets[i].x+=rockets[i].xVel;
		rockets[i].y+=rockets[i].yVel;
		rockets[i].z+=rockets[i].zVel;
		if(rockets[i].col.green>5)
			rockets[i].col.green-=5;
		if(rockets[i].col.blue>5)
			rockets[i].col.blue-=5;
		/*
		Serial.print(rockets[i].col.red);
		Serial.print(" ");
		Serial.print(rockets[i].col.green);
		Serial.print(" ");
		Serial.println(rockets[i].col.blue);
		setVoxel(rockets[i].x,rockets[i].y,rockets[i].z,rockets[i].col);
		*/

		if(rocketsToFire>0)
		if(rockets[i].y<0)
		{
		rocketsToFire--;
		rockets[i].gravity=-0.01;
		rockets[i].y=0;
		rockets[i].x=center.x;
		rockets[i].z=center.z;
		rockets[i].col=Color(random(100),random(100),random(100));
		rockets[i].xVel=(float)random(10)/10;//((float)random(10)/10)-0.5;
		rockets[i].yVel=(float)random(10)/10;
		rockets[i].zVel=((float)random(5)/10);
		}
	    }
	    for(int i=0;i<(NUM_ROCKETS%2==0?NUM_ROCKETS:NUM_ROCKETS-1);i+=2)
		line(rockets[i].x*cos(offset), rockets[i].y, rockets[i].z*sin(offset),rockets[i+1].x, rockets[i+1].y, rockets[i+1].z,rockets[i].col);
	    offset+=0.1;
	    mirror();
}

void mirror()
{
	for(int x=center.x;x<SIZE;x++)
		for(int y=0;y<SIZE;y++)
			for(int z=center.z;z<SIZE;z++)
			{
				setVoxel(center.x-(x-center.x),y,z, getVoxel(x,y,z));
				setVoxel(center.x-(x-center.x),y,center.z-(z-center.z), getVoxel(x,y,z));
				setVoxel(x,y,center.z-(z-center.z), getVoxel(x,y,z));
			}
}
void loop() 
{    
  if(fading)
        fade();
    else
    {   switch(demo%DEMO_ROUTINES){
   
   case(FIREWORKS):
	updateFireworks();
   break;
   
   case(CIRCLES):
      circles();
   break;
   
   case(ROMAN_CANDLE):
      romanCandle();
   break;
   
   case(FFT_JOY):
      fft_joy();
   break;
   }
   frame++;    
    }
   show();
   if(autoCycle)
      if(millis()-lastDemo>DEMO_TIME)
      {
		fading=true;
		demo++;
		lastDemo=millis();
      }

    if(fading)
    {
        fadeValue-=fadeSpeed;
        //if we're done fading)
        if(fadeValue<=0)
        {
            fading=false;
            fadeValue=255;
        }
        else
            fade();
    }

   //uncomment to enable whack-to-change

  updateAccelerometer();

   if((whacked)&&((millis()-timeout)>250))
   {
	autoCycle=false;
	fading=true;
	demo++;
	timeout=millis();
	}

}

void fade()
{
    setFadeSpeed();
    Color voxelColor;
        for(int x=0;x<SIZE;x++)
            for(int y=0;y<SIZE;y++)
                for(int z=0;z<SIZE;z++)
                    {
                        voxelColor=getVoxel(x,y,z);
                        if(voxelColor.red>0)
                            voxelColor.red--;
                        if(voxelColor.green>0)
                             voxelColor.green--;
                        if(voxelColor.blue>0)
                            voxelColor.blue--;
                        setVoxel(x,y,z, voxelColor);    
                    }
}



/********************************************
 *   FFT JOY functions
 * *****************************************/
void fft_joy(){
    for(int i=0;i<pow(2,M);i++)
    {
	int micValue=analogRead(MICROPHONE);
	micAverage=micAverage+((float)micValue-micAverage)/NUM_SAMPLES;
        real[i]=micValue-micAverage;
        delayMicroseconds(120); //200; //this sets our 'sample rate'.  I went through a bunch of trial and error to
                                //find a good sample rate to put a soprano's vocal range in the spectrum of the cube
      //  Serial.print(real[i]);
        imaginary[i]=0;
    }
    FFT(1, M, real, imaginary);
    for(int i=0;i<pow(2,M);i++)
    {
        imaginary[i]=sqrt(pow(imaginary[i],2)+pow(real[i],2));
        if(imaginary[i]>maxValue)
            maxValue=imaginary[i];
    }
    if(maxValue>100)
        maxValue--;
    for(int i=0;i<pow(2,M)/2;i++)
    {
        imaginary[i]=SIZE*imaginary[i]/maxValue;
        int y;
        for(y=0;y<=imaginary[i];y++)
            setVoxel(i,y,SIZE-1,colorMap(y,0,SIZE));
        for(;y<SIZE;y++)
            setVoxel(i,y,SIZE-1,Color(0,0,0));
    }
    for(int z=0;z<SIZE-1;z++)
        for(int x=0;x<SIZE;x++)
            for(int y=0;y<SIZE;y++)
            {
                Color col=getVoxel(x,y,z+1);
                setVoxel(x,y,z,col);
            }

    sample++;
    if(sample>=pow(2,M))
        sample-=pow(2,M);
}

short FFT(short int dir,int m,float *x,float *y)
{
   int n,i,i1,j,k,i2,l,l1,l2;
   float c1,c2,tx,ty,t1,t2,u1,u2,z;

   /* Calculate the number of points */
   n = 1;
   for (i=0;i<m;i++) 
      n *= 2;

   /* Do the bit reversal */
   i2 = n >> 1;
   j = 0;
   for (i=0;i<n-1;i++) {
      if (i < j) {
         tx = x[i];
         ty = y[i];
         x[i] = x[j];
         y[i] = y[j];
         x[j] = tx;
         y[j] = ty;
      }
      k = i2;
      while (k <= j) {
         j -= k;
         k >>= 1;
      }
      j += k;
   }

   /* Compute the FFT */
   c1 = -1.0; 
   c2 = 0.0;
   l2 = 1;
   for (l=0;l<m;l++) {
      l1 = l2;
      l2 <<= 1;
      u1 = 1.0; 
      u2 = 0.0;
      for (j=0;j<l1;j++) {
         for (i=j;i<n;i+=l2) {
            i1 = i + l1;
            t1 = u1 * x[i1] - u2 * y[i1];
            t2 = u1 * y[i1] + u2 * x[i1];
            x[i1] = x[i] - t1; 
            y[i1] = y[i] - t2;
            x[i] += t1;
            y[i] += t2;
         }
         z =  u1 * c1 - u2 * c2;
         u2 = u1 * c2 + u2 * c1;
         u1 = z;
      }
      c2 = sqrt((1.0 - c1) / 2.0);
      if (dir == 1) 
         c2 = -c2;
      c1 = sqrt((1.0 + c1) / 2.0);
   }

   /* Scaling for forward transform */
   if (dir == 1) {
      for (i=0;i<n;i++) {
         x[i] /= n;
         y[i] /= n;
      }
   }

   return(0);
}

void circles()
{
   background(Color(0,0,0));
   poly1[0]=Point(center.x+(SIZE/2)*cos(poly1Angles[0]),0,center.z+(SIZE/2)*sin(poly1Angles[0]));
   poly1[1]=Point(0,center.y+(SIZE/2)*cos(poly1Angles[1]),center.z+(SIZE/2)*sin(poly1Angles[1]));
   poly1[2]=Point(center.x+(SIZE/2)*cos(poly1Angles[2]),SIZE-1,center.z+(SIZE/2)*sin(poly1Angles[2]));
   poly1[3]=Point(SIZE-1,center.y+(SIZE/2)*cos(poly1Angles[3]),center.z+(SIZE/2)*sin(poly1Angles[3]));

   poly2[0]=Point(center.x+(SIZE/2)*cos(poly2Angles[0]),center.y+(SIZE/2)*sin(poly2Angles[0]),0);
   poly2[1]=Point(SIZE-1,center.y+(SIZE/2)*cos(poly2Angles[1]),center.z+(SIZE/2)*sin(poly2Angles[1]));
   poly2[2]=Point(center.x+(SIZE/2)*cos(poly2Angles[2]),center.y+(SIZE/2)*sin(poly2Angles[2]),SIZE-1);
   poly2[3]=Point(0,center.y+(SIZE/2)*cos(poly2Angles[3]),center.z+(SIZE/2)*sin(poly2Angles[3]));

   poly3[0]=Point(center.x+(SIZE/2)*cos(poly3Angles[0]),0, center.z+(SIZE/2)*sin(poly3Angles[0]));
   poly3[1]=Point(center.x+(SIZE/2)*cos(poly3Angles[1]),center.y+(SIZE/2)*cos(poly3Angles[1]),0);
   poly3[2]=Point(center.x+(SIZE/2)*cos(poly3Angles[2]),SIZE-1, center.z+(SIZE/2)*sin(poly3Angles[2]));
   poly3[3]=Point(center.x+(SIZE/2)*cos(poly3Angles[3]),center.y+(SIZE/2)*cos(poly3Angles[3]),SIZE-1); 

   for(int i=0;i<4;i++)
   {
	poly1Angles[i]+=poly1AnglesInc[i];
	poly2Angles[i]+=poly2AnglesInc[i];
	poly3Angles[i]+=poly3AnglesInc[i];
	float sin1=(float)255*sin(poly1Color);
	float sin2=(float)255*sin(poly2Color);
	float sin3=(float)255*sin(poly3Color);
   	line(poly1[i], poly1[(i+1)%4], Color(abs(sin1),0,0));
   	line(poly2[i], poly2[(i+1)%4], Color(0,0,abs(sin2)));
   	line(poly3[i], poly3[(i+1)%4], Color(0,abs(sin3),0));
   }
   poly1Color+=poly1ColorInc;
   poly2Color+=poly2ColorInc;
   poly3Color+=poly3ColorInc;
}

void background(Color col)
{
    for(int x=0;x<SIZE;x++)
        for(int y=0;y<SIZE;y++)
            for(int z=0;z<SIZE;z++)
                setVoxel(x,y,z,col);
}

void setVoxel(int x, int y, int z, Color col)
{
    if((x>=0)&&(x<SIZE))
        if((y>=0)&&(y<SIZE))
            if((z>=0)&&(z<SIZE))
            {
                int index=z*256+x*16+y;
                PIXEL_RGB[index*3]=col.green;
                PIXEL_RGB[index*3+1]=col.red;
                PIXEL_RGB[index*3+2]=col.blue;
            }
}

void setVoxel(Point p, Color col)
{
    setVoxel(p.x, p.y, p.z, col);
}

void line(Point p1, Point p2, Color col)
{
    line(p1.x, p1.y, p1.z, p2.x, p2.y, p2.z, col);
}

void line(int x1, int y1, int z1, int x2, int y2, int z2, Color col)
{
  Point currentPoint;
  currentPoint.x=x1;
  currentPoint.y=y1;
  currentPoint.z=z1;
  
  int dx = x2 - x1;
  int dy = y2 - y1;
  int dz = z2 - z1;
  int x_inc = (dx < 0) ? -1 : 1;
  int l = abs(dx);
  int y_inc = (dy < 0) ? -1 : 1;
  int m = abs(dy);
  int z_inc = (dz < 0) ? -1 : 1;
  int n = abs(dz);
  int dx2 = l << 1;
  int dy2 = m << 1;
  int dz2 = n << 1;

  if((l >= m) && (l >= n)) {
    int err_1 = dy2 - l;
    int err_2 = dz2 - l;

    for(int i = 0; i < l; i++) {
      setVoxel(currentPoint, col);

      if(err_1 > 0) {
        currentPoint.y += y_inc;
        err_1 -= dx2;
      }

      if(err_2 > 0) {
        currentPoint.z += z_inc;
        err_2 -= dx2;
      }

      err_1 += dy2;
      err_2 += dz2;
      currentPoint.x += x_inc;
    }
  } else if((m >= l) && (m >= n)) {
    int err_1 = dx2 - m;
    int err_2 = dz2 - m;

    for(int i = 0; i < m; i++) {
      setVoxel(currentPoint, col);

      if(err_1 > 0) {
        currentPoint.x += x_inc;
        err_1 -= dy2;
      }

      if(err_2 > 0) {
        currentPoint.z += z_inc;
        err_2 -= dy2;
      }

      err_1 += dx2;
      err_2 += dz2;
      currentPoint.y += y_inc;
    }
  } else {
    int err_1 = dy2 - n;
    int err_2 = dx2 - n;

    for(int i = 0; i < n; i++) {
      setVoxel(currentPoint, col);

      if(err_1 > 0) {
        currentPoint.y += y_inc;
        err_1 -= dz2;
      }

      if(err_2 > 0) {
        currentPoint.x += x_inc;
        err_2 -= dz2;
      }

      err_1 += dy2;
      err_2 += dx2;
      currentPoint.z += z_inc;
    }
  }

  setVoxel(currentPoint, col);
}


Point add(Point a, Point b)
{
	return Point(a.x+b.x, a.y+b.y, a.z+b.z);
}

// draws a hollow  centered around the 'center' PVector, with radius
// radius and color col
void sphere(Point center, float radius, Color col) {
     float res = 30;
     for (float m = 0; m < res; m++)
     	 for (float n = 0; n < res; n++)
	     setVoxel(center.x + radius * sin((float) PI * m / res) * cos((float) 2 * PI * n / res),
		      center.y + radius * sin((float) PI * m / res) * sin((float) 2 * PI * n / res),
		      center.z + radius * cos((float) PI * m / res),
		      col);
}

// draws a hollow  centered around the 'center' PVector, with radius
// radius and color col
void sphere(Point center, float radius, Color col, int res) {
     for (float m = 0; m < res; m++)
     	 for (float n = 0; n < res; n++)
	     setVoxel(center.x + radius * sin((float) PI * m / res) * cos((float) 2 * PI * n / res),
		      center.y + radius * sin((float) PI * m / res) * sin((float) 2 * PI * n / res),
		      center.z + radius * cos((float) PI * m / res),
		      col);
}

void sphere(float x, float y, float z, float radius, Color col) {
     sphere(Point(x,y,z),radius, col);
}

void sphere(float x, float y, float z, float radius, Color col, int res) {
     sphere(Point(x,y,z),radius, col, res);
}

void show(){
    uint8_t *ptrA,*ptrB,*ptrC,*ptrD,*ptrE,*ptrF,*ptrG,*ptrH;
    uint8_t mask;
    uint8_t c=0,a=0,b=0,j=0;
    
    GPIOA->BSRRH=0xE0;    //set A3~A5 to low
    GPIOB->BSRRH=0xF0;    //set D0~D4 to low
    GPIOC->BSRRH=0x04;     //set A2 to low
    
    ptrA=&PIXEL_RGB[0];
    ptrB=ptrA+stripPIXEL*3;
    ptrC=ptrB+stripPIXEL*3;
    ptrD=ptrC+stripPIXEL*3;
    ptrE=ptrD+stripPIXEL*3;
    ptrF=ptrE+stripPIXEL*3;
    ptrG=ptrF+stripPIXEL*3;
    ptrH=ptrG+stripPIXEL*3;
    
    delay(1);
    __disable_irq();

    uint16_t i=stripPIXEL*3;   //3 BYTES = 1 PIXEL
    
    while(i) { // While bytes left... (3 bytes = 1 pixel)
      i--;
      mask = 0x80; // reset the mask
      j=0;
        // reset the 8-bit counter
      do {
        a=0;
        b=0;
        c=0;

//========Set D0~D4, i.e. B7~B4=======
        if ((*ptrA)&mask) b|=0x10;// if masked bit is high
    //    else "nop";
        b<<=1;
        if ((*ptrB)&mask) b|=0x10;// if masked bit is high
    //    else "nop";
        b<<=1;
        if ((*ptrC)&mask) b|=0x10;// if masked bit is high
    //    else "nop";
        b<<=1;
        if ((*ptrD)&mask) b|=0x10;// if masked bit is high
   //     else "nop";

//=========Set A2, i.g. C2==========
        if ((*ptrE)&mask) c|=0x04;// if masked bit is high
   //     else "nop";
   
        GPIOA->BSRRL=0xE0;    //set A3~A5 to high
        GPIOB->BSRRL=0xF0;    //set D0~D4 to high
        GPIOC->BSRRL=0x04;    //set A2 to high
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

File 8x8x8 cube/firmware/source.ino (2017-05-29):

#include "beta-cube-library.h"
#include <math.h>
SYSTEM_THREAD(ENABLED);

String modes="off;fireworks;zplasma;fftjoy;squarral";
String mode="fireworks";
int setMode(String _mode);

#define FIRMWARE_VERSION "0.5.1"

#define MICROPHONE 12
#define GAIN_CONTROL 11
#define MAX_POINTS 20
#define SPEED 0.22


#define FIREWORKS 0
#define SQUARRAL 1
#define PLASMA 2
#define FFT_JOY 3
#define DEMO_ROUTINES 4


void add(Point& a, Point& b);


/******************************
 * fireworks variables *
 * ****************************/
 int centerX, centerY, centerZ;
int launchX, launchZ;
int brightness=50;
float radius=0;
float speed;
bool showRocket;
bool exploded;
float xInc, yInc, zInc;
float rocketX, rocketY, rocketZ;
float launchTime;
int maxSize;
Color rocketColor, fireworkColor;



/*********************************
 * squarral variables *
 * ******************************/

#define TRAIL_LENGTH 50

int frame=0;
Color voxelColor;
Point position, increment, pixel;
Point trailPoints[TRAIL_LENGTH];
int posX, posY, posZ;
int incX, incY, incZ;
int squarral_zInc=1;
int bound=0;
int boundInc=1;
unsigned char axis=0;
bool rainbow=true;

//maxBrightness is the brightness limit for each pixel.  All color data will be scaled down 
//so that the largest value is maxBrightness
int maxBrightness=50;

/********************************
 * zplasma variables *
 * *****************************/
float phase = 0.0;
float phaseIncrement = 0.035; // Controls the speed of the moving points. Higher == faster
float colorStretch = 0.23; // Higher numbers will produce tighter color bands 
float plasmaBrightness = 0.2;
Color plasmaColor;

/*********************************
 * FFTJoy variables *
 * *******************************/
#define M 4
float real[(int)pow(2,M)];
float imaginary[(int)pow(2,M)];
float maxValue=0;
float maxVal=8;
int   inputLevel=63;  //this sets the sensitivity for the onboard AGC circuit (0-255); the higher, the more sensitive
bool  smoothLEDs=true;  //switch for 'smoothening-out' the LEDs fade-to-black on the spectrum
bool  dotMode=true;
#define NUM_SAMPLES 2222
float micAverage;
float sample;

/**********************************
 * flip variables *
 * ********************************/
 //accelerometer pinout
#define X 13
#define Y 14
#define Z 15
#define AUTOCYCLE_TIME 22222
#define FACEPLANT 2300
#define UPSIDE_DOWN 1850
#define RIGHTSIDE_UP 2400
#define LEFT_SIDE 1800
#define RIGHT_SIDE 2400
#define FLIP_TIMEOUT 3000
#define FLIP_DEBOUNCE 250

long lastFaceplant=-1*FLIP_TIMEOUT;
bool upsideDown=false;
bool sideways=false;
bool autoCycle=true;    //start on autocycle by default
int upsideDownTime=-1*FLIP_TIMEOUT;
long lastAutoCycle=0;
int lastLeft=-1*FLIP_TIMEOUT;
int lastRight=-1*FLIP_TIMEOUT;
int accelerometer[3];
long lastChange=0;


int demo=FIREWORKS;

int frameCount=0;

/*******************************
 * fade variables *
 * ****************************/
bool fading=false;
int fadeValue=255;
int fadeSpeed=2;

Cube cube=Cube();

void initSquarral();
void squarral();

void initFireworks();
void prepRocket();
void updateFireworks();
float distance(float x, float y, float z, float x1, float y1, float z1);
void add(Point& a, Point& b);

void fade();
void zPlasma();

void FFTJoy();
short FFT(short int dir,int m,float *x,float *y);

void checkFlipState();
void updateAccelerometer();
void setFadeSpeed();
void incrementDemo();
void decrementDemo();

bool firmwareUpToDate;
void setup() {
 publishCloudVariables();
 cube.begin();
 initMicrophone();
 initSquarral();
 initFireworks();
 pinMode(D7, OUTPUT);
 Serial.begin(115200);
 Serial.print("running system firmware version: ");
 Serial.println(System.version());
 if(strcmp(System.version(), FIRMWARE_VERSION)==0)
   firmwareUpToDate=true;
 else
   firmwareUpToDate=false;						  
										 
}

void publishCloudVariables()
{
	Particle.variable("mode", mode);
	Particle.variable("modes", modes);
	Particle.function("setMode", setMode);
	Particle.function("setAutocycle", setAutocycle);
}

int setMode(String _mode)
{
	autoCycle=false;
	mode=_mode.toLowerCase();
	fading=true;
	return 0;
}

int setAutocycle(String _loop)
{
	if(_loop.toLowerCase().compareTo("false")==0)
	autoCycle=false;
	else
	autoCycle=true;
}




void loop() {
  if(firmwareUpToDate)
  digitalWrite(D7, HIGH);
  else
  {
  digitalWrite(D7, (frameCount%10>5));
  } 
 
    
  if(fading)
        fade();
    else
    {
            if(mode.compareTo("fftjoy")!=0)
            cube.background(black);
            if(mode.compareTo("fireworks")==0)
                updateFireworks();
            if(mode.compareTo("zplasma")==0)
                zPlasma();
            if(mode.compareTo("squarral")==0)
                squarral();
            if(mode.compareTo("fftjoy")==0)
                FFTJoy();
        frameCount++;
    }
    //check to see how if the cube has been flipped
    checkFlipState();

    cube.show();
    
    if(fading)
    {
        fadeValue-=fadeSpeed;
        //if we're done fading)
        if(fadeValue<=0)
        {
            fading=false;
            fadeValue=255;
        }
        else
            fade();
    }
}

void fade()
{
    Color voxelColor;
        for(int x=0;x<cube.size;x++)
            for(int y=0;y<cube.size;y++)
                for(int z=0;z<cube.size;z++)
                    {
                        voxelColor=cube.getVoxel(x,y,z);
                        if(voxelColor.red>0)
                            voxelColor.red--;
                        if(voxelColor.green>0)
                             voxelColor.green--;
                        if(voxelColor.blue>0)
                            voxelColor.blue--;
                        cube.setVoxel(x,y,z, voxelColor);    
                    }
}

/***************************************
 * fireworks functions *
 * ***********************************/
 
 
void updateFireworks()
{
	if(showRocket)
        cube.sphere(rocketX,rocketY,rocketZ,radius, rocketColor);
    if(exploded)
         cube.shell(rocketX,rocketY,rocketZ,radius,fireworkColor);
        

        if(exploded)
            radius+=speed;  //the sphere gets bigger
        if(showRocket)
        {
            rocketX+=xInc;
            rocketY+=yInc;
            rocketZ+=zInc;
        }
        //if our sphere gets too large, restart the animation in another random spot
        if(radius>maxSize)
            prepRocket();
        if(abs(distance(centerX,centerY,centerZ,rocketX, rocketY, rocketZ)-radius)<2)
            {
                showRocket=false;
                exploded=true;
            }
        
}

float distance(float x, float y, float z, float x1, float y1, float z1)
{
    return(sqrt(pow(x-x1,2)+pow(y-y1,2)+pow(z-z1,2)));
}
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

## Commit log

2014-09-11 first post
    [BOM_LyteLab_V4.xls, LyteLab_Base_Rev4.brd, LyteLab_Base_Rev4.sch]
2014-09-25 added LED sticks and acrylic case files
    [2mm acrylic parts.dxf, 3mm acrylic parts.dxf, LED_strip.brd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]
2014-10-17 added the 16 cube files and separated everything into neat little boxes
    [2mm acrylic parts.dxf, 3mm acrylic parts.dxf, BOM_LyteLab_V4.xls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]
2014-10-17 cleaned up removed files
    [2mm acrylic parts.dxf, 3mm acrylic parts.dxf, BOM_LyteLab_V4.xls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]
2014-11-15 updated to rev 7
    [L3DCube_16LED_Rev1.brd, L3DCube_16LED_Rev1.sch, baseboard.brd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]
2014-11-25 changed .dxf files to R14 format
    [2mm acrylic parts.dxf, 3mm acrylic parts.dxf]
2014-12-21 updated lasercut files to christmas cube version (rev 0.7)
    [2mm acrylic parts.dxf, 2mm.DXF, 2mm_eng.DXF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]
2015-02-20 updated files for v2 for the 16x cube
    [L3DCube_16LED_Rev1.brd, LyteLab_16x16_Base_Rev1.brd, LyteLab_16x16_Base_Rev1.sch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]
2015-06-03 updated to the kickstarter production cubes
    [LED strip.brd, LED strip.sch, baseboard BOM.xls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]
2015-06-03 cleaned up the schematic a bit
    [Base Board.brd, Base Board.sch, L3D_Necklace_Rev1.brd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]
2015-06-04 renamed a couple lines in the schematic
    [Base Board.sch]
2015-11-25 updated 8x bom, schematic and layout for the baseboard
    [Base Board.brd, Base Board.sch, L3DCube_16x16_Base_Rev3.brd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]
2016-04-11 added BOM for the 1x1x1 cube
2017-03-31 added 16x case files
    [3mm.DXF, 6mm.DXF, 8mm.DXF]
2017-03-31 added 16x solidworks model for reference
    [BigCubePowerPlugholder.SLDPRT, DC2DC.SLDPRT, KPJX-PM-4S_rB8.SLDPRT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]
2017-05-29 added firmware to repo
    [Base Board.brd, Base Board.sch, L3DCube_16x16_Base_Rev3.brd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]
